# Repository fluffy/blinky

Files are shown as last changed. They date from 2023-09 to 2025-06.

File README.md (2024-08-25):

# blinky

Blinking lights to tell time. And it beeps.

# Build and flash

Build with:
```
mkdir build ; cd build ; cmake .. ; make
```

Note when programming the GPS board, the GPS must be unplugged while
programming.

Program flash using stlink with:
```
st-flash --reset --format ihex write build/blinky.hex
```

Can program using Stm32CubeProgrammer with RTS=1, DTR=0, baud at 115200,
Parity Even, data bits 8, stop bits 1, flow control off.

Program flash using USB serial with:
```
stm32flash -w build/blinky.hex -v -b 115200 -m 8e1 -i "-dtr," /dev/cu.usbserial-31110
```

If this fails, try the following reset then try to flash again. This
will not work on a brand new uninitialized board, the board needs to be
programmed for the first time with st-flash.

Can reset the board with:
```
stty -f /dev/cu.usbserial-31110 hup
```

Monitor output connect with Serial program. Use 115200 baud with 8 bits,
no parity, 1 stop bit. Set the RTS and DTR both low. Screen fails to do
this. It sets RTS and DTR both high it will not work.

To use python miniterm (replace usbserial-31110 with number on your machine):
```
pyserial-miniterm -e --parity N --rts 0 --dtr 0 /dev/cu.usbserial-31110 115200
```
Can exit the miniterm with CTRL+]. This will cause board reset when it starts.

# Tools and Dependencies

Set up a mac to be able to build by installing:

* TODO
* pip3 install pyserial

# Features

## Blink Timing Board

On the Rev A hardware 1.0 software have:

* Timing board with TXCO, LTC Sync in, LTC Sync out, LED grid,
  battery power, USB debug, audio in/out

* Display 120 fps tick on 10x4 grid
* 3.3V LTC Sync Out
* PPS out is hold sync button while booting
* Jitter of less than 1 ms
* Jam sync to 3.3V Sync input
* Time drift of < 5 ms in 1 hour
* USB port for serial data
* read  calibration from EEPROM
* audio out of beep
* headset monitor of audio out
* usb upgrade of firmware
* Status LEDs: error(red), external synced (green),  not sync (
  blue ), have sync (teal)
* audio input to detect beep
* battery with 2h life and USB charger

## Clock and GPS Board

On the Rev A hardware 0.2 software have:

* GPS board with GPS, OCXO
* LTC sync out, LTC sync in
* Does not have audio or led display grid
* 10 MHz sine wave output 1V p2p into 50 ohm, 3 channels
* Sync to GPS PPS
* Show current PPS offset from GPS PPS
* Compare PPS accuracy to GPS over 24 hours
* read  calibration from EEPROM
* USB serial display of: Time, GPS Error, SyncIn Error
* Aux input of 10 MHz signal to compare
* PPS jitter of about +/- 20 ns and error less than 10 ns
* USB upgrade of firmware
* USB 3A power for gps board
* USB output serial data for computer time sync

## Light GPS Board

On the Rev A hardware 0.2 software have:

* GPS board with GPS
* LTC sync out
* Does not have audio or led display grid
* Sync to GPS PPS
* USB upgrade of firmware
* USB power
* USB output serial data for computer time sync

## Wishlist

* time into browser measure computer time offset
* software upgrade from browser

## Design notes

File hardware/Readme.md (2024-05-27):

# Notes on updating hardware

If the schematic or boards in changed such that the software can tell
the difference, the rev need to go up a letter. Other changes can get a
sub number on the rev letter.

## Schematics

Don't update sybols  / footprint from libraries. It over writes stuff.

When done, do a plot to generate schematic in production subdir.

## PCB

When done, do an export of step to generate a model in production
subdir.

## JLCPCB

Make sure to have them check part placement becuase it will be
wrong. Even what they have in the preivewi tool does not allways match
what they have in productions.

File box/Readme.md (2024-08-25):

# Box Info

The main design is in the .FCStd files and crearted with FreeCad.

Most the design paramters are on the "Data" sheet.

Select the object in FreeCad to export the parts as .3mf and .step. The
exported files are in the prod subdirectory.

Go to the front and back drawing and right click on page to select
"Export DXF" and export as .dxf to the prod subdirectory. Using the
export option on the file menu does not work. The eDrawings app on osx
can look at DXF and STEP files.

Import the DXF files into XCR or lightburn for laser cutting.

Upload the step file to sendcutsend.com or jlcpcb.co. With send cut
send, had selected 2mm thick 6061 T6 Aluminum and had it annodized.

3D print using the .3mf files. Set a inner brim of 7 mm on 1st layer
seems to help with small holes.

## Data Flow

KiCad generates step models for the PCBs and puts them in
hardware/blink/productions dir.

This PCB is imported into the FreeCAD drawing for box which generates
DXF files in box/prod dir.

This is brought in to laserA.xcs with "xTool Creative Space" application
to add the labels and set up for laser cutting.

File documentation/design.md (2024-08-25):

# Design Notes for Rev A

## Terminology

Sync refers to Sync In

PPS refers to Sync Out

Mon refers to monitor of PPS

## Signals

- ExtIn 10 MHz input on PA0
- RefIn 10 Mhz OCXO input on PA15

- PPS 1 pps output - inverts on on output buffer - PA8 on Timer #1
- Mon 1 pps in ( from PPS ) - PB11 & AUX PA2
- SyncIn 1 pps input - inverts on buffer  - PB3 and aux PC6
- GpsIn 1 pps input - PB10 and aux PA1

 On blink board:
 - AUX\_CLK, AUX\_GPS_PPS , GPS\_RX, GPX\_TX not used
 - CLK on PA15 is 2.048 Mhz signal

## Timers

system clock or RefIn drives main 32 bit counter

ExtIn drives aux 32 bit counter

Main and aux count at 10 Mhz and wrap ever second.

Every timer can capture syncMon to provide sync of counters

Main and Aux can capture: SyncMon, SyncIn, GpsIn

Timer 1 can generate SyncOut and can sync to Main or Aux timer.

Display TImer drives LED and sync to main or aux rollover

### PPS Out Timer #1  - hTimePps (aka Sync Out)

* Use timer 1. This timer running at 168 Mhz input clock

* CH1 - PA8 - TimePps\_CH\_SYNC\_OUT increments at 50 KHz does 20 ms
wide output pulse every 1 second Resets based on ITR1 from Tim2 Update
Event (main)

* 16 bits

* sync off of timer 2.  loop ever 1.1 seconds.  Input APB2 @ 168 MHz

### Main Timer #2 - hTimeSync (aka SyncIn/main)

* Use timer 2
* max 42 Mhz
* 32 bits
* clocked with ETR from main TCXO at 2.024 MHz or 10 MHz
* period of 1 second ( adjusted in software )
* adjustment store in EEPROM

* ETR: PA15
* CH1: PA0 - NA with ETR
* CH2: PA3  - sync\_in   TimeSync\_CH\_SYNC\_IN
* CH3: PB10  - gps   TimeSync\_CH\_GPS\_PPS
* CH4: PB11  - sync\_mon   TimeSync\_CH\_SYNC\_MON

CH1 is disabled if ETR is in use

* Capture Sync Mon
* Capture PPS In
* Capture GPS PPS

Input APB1 at 84 MHz

### ADC Timer - Timer 3

* count at 1MHz
* 114 count - about 440*20 Hz
* not sync, trigger out to ADC1
Input APB1 at 84 MHz

### Blink Timer - TImer 4

* use timer 4
* trigger reset by main timer every second
* Reset on ITR1 from Tim2
* period 1 ms
* interrupt ( 1 KHz) to drive LEDs
Input APB1 at 84 MHz

### Aux Timer - Timer 5

Assumes that that Aux signal is getting a 10Mhz signal.

* Use 32 bit timer 5
* max 42 Mhz
* ETR:
* CH1: PA0 - AUX\_CLK
* CH2:  PA1 - GPS
* CH3: PA2 - AUX_MON
* Ch4: PA4  - no

CH1 ends up feeding clock.  Capture the Captures both edges of external
so scale by 2 to couting at 10 MHz. The SyncMon capture time allows this
to be coorelated with the other main clock.

* capture SyncMon
* capture GPS PPS
* capture SyncIn
* Input APB1 at 84 MHz

### DAC Timer - Timer 6

* note this does not reset on main
* 1 Mhz count rate
* 8 KHz period ( 1000 count )
* trigger out to DAC2
* Input APB1 at 84 MHz

### TImer 8 - used to time LTC

* has SYCN_IN2 on CH1 on PC6
* reset on main
* 50 KHz rate

1.1 seconds , count up on main at 50 KHz
Input APB2 @ 168 MHz

## Serial

* USB\_RX/TX on PB6/PB7 on USART1

* GPS\_RX1/TX1 on PC10/PC11

* GPS is NMEA-0183 set at 4800 baud 8N1

* GPS is Garmin "GPS 16x LVS"

## DAC

* CH1 is voltage toVCO - PA4
* CH2 is audio out - PA5

* DAC2 is DMA stream 6 memory to peripheral on DMA controller #1
* Normal not circular

## ADC

* uses TIM 3

# Interrupt Handling

On each Main Sync Mon
- save sync out local seconds and microseconds

On each Main GPS PPS
- increment gps seconds and save lastGpsTime in local seconds, microseconds

on each Main SyncIn
- save syncIn local seconds and microsecond

on each Main SyncOut
- if off, turn on, load syncOutOffset+10ms * (seconds%10)
- in on, turn off, load syncOutOffset

on each Aux SyncMon
* save aux 32 bit timer in AuxSyncMon auxSeconds

On each Main Timer rollover
* reset ms time and offset by syncOutOffset
* increment local seconds

On each Blink Timer
* increment msTime
* set all the LEDS based on msTime and local Seconds

Periodically on main thread
* compute gps offset microseconds (32 bit signed)
* compute syncIn offset microseconds (32 bit signed)
* compute syncMon offset microseconds (32 bit signed)
* compute aux offset microseconds ( 32 bit ) from synMon times on main and aux
* if have recent syncIn, adjust syncOutOffset to match syncIn
* if have recent gpsPPS, adjust syncOutOffset to match gps pps

* save last 100 seconds of syncInOffset, gpsOffset, auxOffset, syncMon offset
* compute average offset over last 100s for GPS, Aux, SyncIn
* compute drift rate in Hz over last 100s for GPS, Aux, SyncIn
* compute stdDev off of drift linear for GPS, Aux, Sync

* adjust period of main to match GPS, Aux, Sync in that priority order

# Charging & Power

Max charges rate is 500 mA up to 4.1 V then drops off with m charges up
to 4.2 V. This charge rate selected to not go over USB limit.  Using 820
mAH battery. Current consumption of about 170 mA when *not* on battery.

The blink board uses about 150 mA when running ( bouncing around 145 to
165 based on how many leds ).

On the ev9 board blink board, the 3.3v regulator, in 25C room, runs
about 40 C at 5V input and 50C at 7V input. Indicating about 33 C/watt
thermal resitance which pretty much matched specs for AMS117.

# Calibrating and Adjusting

On frequency counter. On "internal setup" set timeout off.  Noise Reject
on, DC, 1M ohm, manual level 200 mV History grom from 1 s - 20 ns to 1
s+20 ns, 40 bins

On the 2.048 Mhz VCO, will need to adjust pot to get in range. 30 degree
turn made huge difference.

# ESD

The SN74LVC1G14 provide ESD protection. The USB has pretection with the
TODO chip. The USB power CC1/2 power monitor circuits have no
protection. The AD8397 for audio ciricuits on blink board have no
protection on current design. The ADA4807 on clock board have no
protection. The power input on clock board has no protection.

# Linear Time Codes

The spec for them is at
https://www.itu.int/dms_pubrec/itu-r/rec/br/R-REC-BR.780-2-200504-W!!PDF-E.pdf
and more info at https://en.wikipedia.org/wiki/Linear_timecode

# UI and Modes

Buttons controll the varios modes.

Sync button causes it to sync to an input. If it has GPS then use
that, otherwise if have sync in, use that.

Display button moves between: blink,  audio latency, and off

Mute button moves between: rx only, rx & tx

Status LED is:
RED: Error
Purple: Bad power
Blue: Running but not synced
Green: Synced and running

Will auto sync on first sync if sync buton has never been hit

## Configureation

EEProm stores, serial number and device type, calibration info, config
if LTC or PPS output

## Serial Ouput

Sends @ mark for timing host software

Sends current time HH::MM:SS

All metrics reset to zero on first mon pulse after press of sync button

On clock board, mark pulse is GPS, on blink it is Sync

Measurements:

* Current SyncIn Offset in uS

* Current GPS Offset in uS

* Current Mon Offset in uS

* Tick time of last mon pulse

* Tick time of last sync pulse

* Tick time of last gps pulse

* Current Mon ExtOffset in uS

* Current GPS ExtOffset in uS

* Tick time of last ext mon pulse

* Tick time of last ext gps pulse

* GPS seconds of last gps pulse

* LTC seconds of last sync pulse

* Local counter rollover count  ( seconds )

* Ext counter rollover count ( seconds )

The current values are copied to prev once a seconds in the mon pulse
interupt then used to compute the rest of the metrics

Metrics:

* Current time from varios soruces.

* Time erorrs between sources

* Rate of change between sources over 1,10,100 seconds

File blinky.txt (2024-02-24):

Configuration	blinky
STM32CubeMX 	6.10.0
Date	02/24/2024
MCU	STM32F405RGTx

PERIPHERALS	MODES	FUNCTIONS	PINS
ADC1	IN10	ADC1_IN10	PC0
ADC2	IN7	ADC2_IN7	PA7
DAC	DAC_OUT1	DAC_OUT1	PA4
DAC	DAC_OUT2	DAC_OUT2	PA5
I2C1	I2C	I2C1_SCL	PB8
I2C1	I2C	I2C1_SDA	PB9
RCC	Crystal/Ceramic Resonator	RCC_OSC_IN	PH0-OSC_IN
RCC	Crystal/Ceramic Resonator	RCC_OSC_OUT	PH1-OSC_OUT
SYS	Serial Wire	SYS_JTCK-SWCLK	PA14
SYS	Serial Wire	SYS_JTMS-SWDIO	PA13
SYS	SysTick	SYS_VS_Systick	VP_SYS_VS_Systick
TIM1	Reset Mode	TIM1_VS_ControllerModeReset	VP_TIM1_VS_ControllerModeReset
TIM1	ITR1	TIM1_VS_ClockSourceITR	VP_TIM1_VS_ClockSourceITR
TIM1	Internal Clock	TIM1_VS_ClockSourceINT	VP_TIM1_VS_ClockSourceINT
TIM1	Output Compare CH1	TIM1_CH1	PA8
TIM2	ETR2	TIM2_ETR	PA15
TIM2	Input Capture direct mode	TIM2_CH2	PB3
TIM2	Input Capture direct mode	TIM2_CH3	PB10
TIM2	Input Capture direct mode	TIM2_CH4	PB11
TIM3	Internal Clock	TIM3_VS_ClockSourceINT	VP_TIM3_VS_ClockSourceINT
TIM4	Reset Mode	TIM4_VS_ControllerModeReset	VP_TIM4_VS_ControllerModeReset
TIM4	ITR1	TIM4_VS_ClockSourceITR	VP_TIM4_VS_ClockSourceITR
TIM4	Internal Clock	TIM4_VS_ClockSourceINT	VP_TIM4_VS_ClockSourceINT
TIM5	External Clock Mode 1	TIM5_VS_ControllerModeClock	VP_TIM5_VS_ControllerModeClock
TIM5	TI1_ED	TIM5_CH1	PA0-WKUP
TIM5	Input Capture direct mode	TIM5_CH2	PA1
TIM5	Input Capture direct mode	TIM5_CH3	PA2
TIM8	Internal Clock	TIM8_VS_ClockSourceINT	VP_TIM8_VS_ClockSourceINT
TIM8	Input Capture direct mode	TIM8_CH1	PC6
USART1	Asynchronous	USART1_RX	PA10
USART1	Asynchronous	USART1_TX	PA9
USART3	Asynchronous	USART3_RX	PC11
USART3	Asynchronous	USART3_TX	PC10

Pin Nb	PINs	FUNCTIONs	LABELs
2	PC13-ANTI_TAMP	GPIO_Input	BTN1
3	PC14-OSC32_IN	GPIO_Output	NCOL10
4	PC15-OSC32_OUT	GPIO_Output	NROW1
5	PH0-OSC_IN	RCC_OSC_IN	HSE_IN
6	PH1-OSC_OUT	RCC_OSC_OUT	HSE_OUT
8	PC0	ADC1_IN10	AUD_IN
9	PC1	GPIO_Output	NROW2
10	PC2	GPIO_Output	NROW3
11	PC3	GPIO_Output	NROW4
14	PA0-WKUP	TIM5_CH1	AUX_CLK
15	PA1	TIM5_CH2	AUX_GPS_PPS
16	PA2	TIM5_CH3	AUX_SYNC_MON
17	PA3	GPIO_Output	LED4
20	PA4	DAC_OUT1	OSC_ADJ
21	PA5	DAC_OUT2	AUD_OUT
22	PA6	GPIO_Output	LED1
23	PA7	ADC2_IN7	LED2
24	PC4	GPIO_Output	LED7
25	PC5	GPIO_Output	LED8
26	PB0	GPIO_Output	LED9
27	PB1	GPIO_Output	LED10
28	PB2	GPIO_Input	BOOT1
29	PB10	TIM2_CH3	GPS_PPS
30	PB11	TIM2_CH4	SYNC_MON
33	PB12	GPIO_Output	NCOL8
34	PB13	GPIO_Output	NCOL7
35	PB14	GPIO_Output	NCOL6
36	PB15	GPIO_Output	NCOL5
37	PC6	TIM8_CH1	AUX_SYNC_IN
38	PC7	GPIO_Output	NCOL4
39	PC8	GPIO_Output	NCOL3
40	PC9	GPIO_Output	NCOL2
41	PA8	TIM1_CH1	SYNC_OUT
42	PA9	USART1_TX	USB_RX
43	PA10	USART1_RX	USB_TX
44	PA11	GPIO_Output	LEDMG
45	PA12	GPIO_Output	LEDMR
46	PA13	SYS_JTMS-SWDIO	SWDIO
49	PA14	SYS_JTCK-SWCLK	SWDCLK
50	PA15	TIM2_ETR	CLK
51	PC10	USART3_TX	GPS_RX1
52	PC11	USART3_RX	GPS_TX1
53	PC12	GPIO_Output	NCOL9
54	PD2	GPIO_Output	DB3
55	PB3	TIM2_CH2	SYNC_IN
56	PB4	GPIO_Input	LED3
57	PB5	GPIO_Output	NROW5
58	PB6	GPIO_Output	NCOL1
59	PB7	GPIO_Output	LEDMB
61	PB8	I2C1_SCL	SCL
62	PB9	I2C1_SDA	SDA
PERIPHERALS	MODES	FUNCTIONS	PINS
ADC1	IN10	ADC1_IN10	PC0
ADC2	IN7	ADC2_IN7	PA7
DAC	DAC_OUT1	DAC_OUT1	PA4
DAC	DAC_OUT2	DAC_OUT2	PA5
I2C1	I2C	I2C1_SCL	PB8
I2C1	I2C	I2C1_SDA	PB9
RCC	Crystal/Ceramic Resonator	RCC_OSC_IN	PH0-OSC_IN
RCC	Crystal/Ceramic Resonator	RCC_OSC_OUT	PH1-OSC_OUT
SYS	Serial Wire	SYS_JTCK-SWCLK	PA14
SYS	Serial Wire	SYS_JTMS-SWDIO	PA13
SYS	SysTick	SYS_VS_Systick	VP_SYS_VS_Systick
TIM1	Reset Mode	TIM1_VS_ControllerModeReset	VP_TIM1_VS_ControllerModeReset
TIM1	ITR1	TIM1_VS_ClockSourceITR	VP_TIM1_VS_ClockSourceITR
TIM1	Internal Clock	TIM1_VS_ClockSourceINT	VP_TIM1_VS_ClockSourceINT
TIM1	Output Compare CH1	TIM1_CH1	PA8
TIM2	ETR2	TIM2_ETR	PA15
TIM2	Input Capture direct mode	TIM2_CH2	PB3
TIM2	Input Capture direct mode	TIM2_CH3	PB10
TIM2	Input Capture direct mode	TIM2_CH4	PB11
TIM3	Internal Clock	TIM3_VS_ClockSourceINT	VP_TIM3_VS_ClockSourceINT
TIM4	Reset Mode	TIM4_VS_ControllerModeReset	VP_TIM4_VS_ControllerModeReset
TIM4	ITR1	TIM4_VS_ClockSourceITR	VP_TIM4_VS_ClockSourceITR
TIM4	Internal Clock	TIM4_VS_ClockSourceINT	VP_TIM4_VS_ClockSourceINT
TIM5	External Clock Mode 1	TIM5_VS_ControllerModeClock	VP_TIM5_VS_ControllerModeClock
TIM5	TI1_ED	TIM5_CH1	PA0-WKUP
TIM5	Input Capture direct mode	TIM5_CH2	PA1
TIM5	Input Capture direct mode	TIM5_CH3	PA2
TIM8	Internal Clock	TIM8_VS_ClockSourceINT	VP_TIM8_VS_ClockSourceINT
TIM8	Input Capture direct mode	TIM8_CH1	PC6
USART1	Asynchronous	USART1_RX	PA10
USART1	Asynchronous	USART1_TX	PA9
USART3	Asynchronous	USART3_RX	PC11
USART3	Asynchronous	USART3_TX	PC10

Pin Nb	PINs	FUNCTIONs	LABELs
2	PC13-ANTI_TAMP	GPIO_Input	BTN1
3	PC14-OSC32_IN	GPIO_Output	NCOL10
4	PC15-OSC32_OUT	GPIO_Output	NROW1
5	PH0-OSC_IN	RCC_OSC_IN	HSE_IN
6	PH1-OSC_OUT	RCC_OSC_OUT	HSE_OUT
8	PC0	ADC1_IN10	AUD_IN
9	PC1	GPIO_Output	NROW2
10	PC2	GPIO_Output	NROW3
11	PC3	GPIO_Output	NROW4
14	PA0-WKUP	TIM5_CH1	AUX_CLK
15	PA1	TIM5_CH2	AUX_GPS_PPS
16	PA2	TIM5_CH3	AUX_SYNC_MON
17	PA3	GPIO_Output	LED4
20	PA4	DAC_OUT1	OSC_ADJ
21	PA5	DAC_OUT2	AUD_OUT
22	PA6	GPIO_Output	LED1
23	PA7	ADC2_IN7	LED2
24	PC4	GPIO_Output	LED7
25	PC5	GPIO_Output	LED8
26	PB0	GPIO_Output	LED9
27	PB1	GPIO_Output	LED10
28	PB2	GPIO_Input	BOOT1
29	PB10	TIM2_CH3	GPS_PPS
30	PB11	TIM2_CH4	SYNC_MON
33	PB12	GPIO_Output	NCOL8
34	PB13	GPIO_Output	NCOL7
35	PB14	GPIO_Output	NCOL6
36	PB15	GPIO_Output	NCOL5
37	PC6	TIM8_CH1	AUX_SYNC_IN
38	PC7	GPIO_Output	NCOL4
39	PC8	GPIO_Output	NCOL3
40	PC9	GPIO_Output	NCOL2
41	PA8	TIM1_CH1	SYNC_OUT
42	PA9	USART1_TX	USB_RX
43	PA10	USART1_RX	USB_TX
44	PA11	GPIO_Output	LEDMG
45	PA12	GPIO_Output	LEDMR
46	PA13	SYS_JTMS-SWDIO	SWDIO
49	PA14	SYS_JTCK-SWCLK	SWDCLK
50	PA15	TIM2_ETR	CLK
51	PC10	USART3_TX	GPS_RX1
52	PC11	USART3_RX	GPS_TX1
53	PC12	GPIO_Output	NCOL9
54	PD2	GPIO_Output	DB3
55	PB3	TIM2_CH2	SYNC_IN
56	PB4	GPIO_Input	LED3
57	PB5	GPIO_Output	NROW5
58	PB6	GPIO_Output	NCOL1
59	PB7	GPIO_Output	LEDMB
61	PB8	I2C1_SCL	SCL
62	PB9	I2C1_SDA	SDA

SOFTWARE PROJECT

Project Settings : 
Project Name : blinky
Project Folder : /Users/fluffy/src/blinky
Toolchain / IDE : STM32CubeIDE
Firmware Package Name and Version : STM32Cube FW_F4 V1.27.1

Code Generation Settings : 
STM32Cube MCU packages and embedded software packs : Copy only the necessary library files
Generate peripheral initialization as a pair of '.c/.h' files per peripheral : No
Backup previously generated files when re-generating : No
Delete previously generated files when not re-generated : Yes
Set all free pins as analog (to optimize the power consumption) : No

Toolchains Settings : 
Compiler Optimizations :

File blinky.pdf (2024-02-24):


24/02/2024

blinky Project
Configuration Report

## 1. Description

### 1.1. Project

Project Name | blinky
Board Name | custom
Generated with: | STM32CubeMX 6.10.0
Date | 02/24/2024

### 1.2. MCU

MCU Series | STM32F4
MCU Line | STM32F405/415
MCU name | STM32F405RGTx
MCU Package | LQFP64
MCU Pin number | 64

### 1.3. Core(s) information

Core(s) | Arm Cortex-M4

## 2. Pinout Configuration

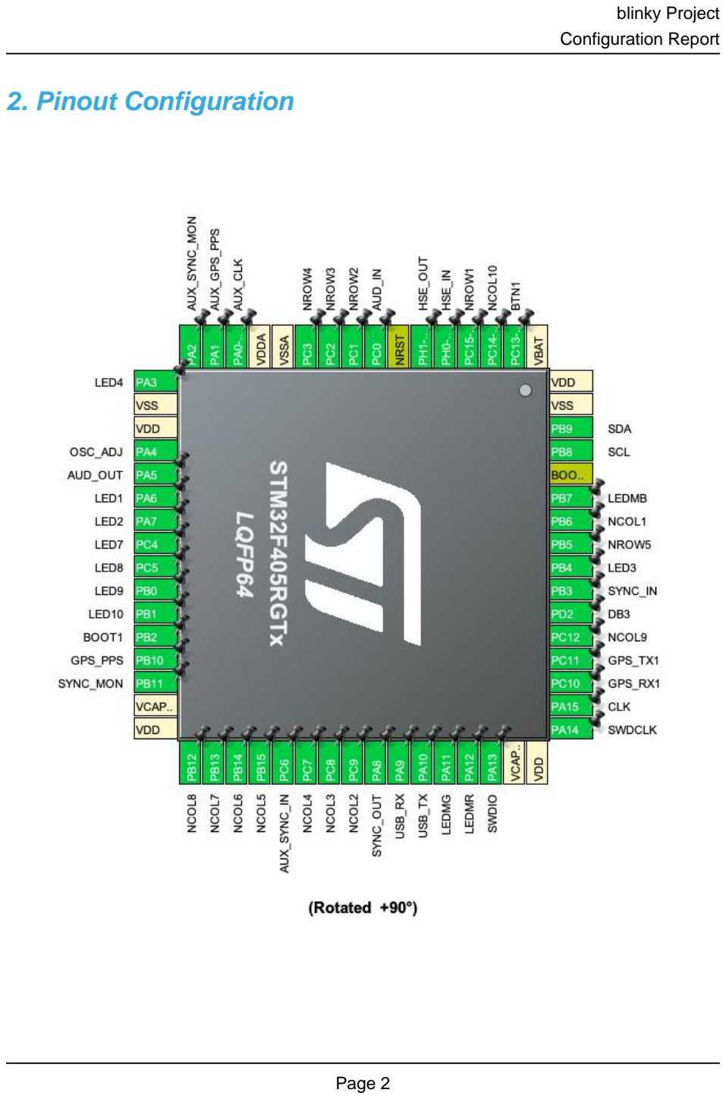
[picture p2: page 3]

## 3. Pins Configuration

Pin Number LQFP64 | Pin Name (function after reset) | Pin Type | Alternate Function(s) | Label
1 | VBAT | Power
2 | PC13-ANTI_TAMP * | I/O | GPIO_Input | BTN1
3 | PC14-OSC32_IN * | I/O | GPIO_Output | NCOL10
4 | PC15-OSC32_OUT * | I/O | GPIO_Output | NROW1
5 | PH0-OSC_IN | I/O | RCC_OSC_IN | HSE_IN
6 | PH1-OSC_OUT | I/O | RCC_OSC_OUT | HSE_OUT
7 | NRST | Reset
8 | PC0 | I/O | ADC1_IN10 | AUD_IN
9 | PC1 * | I/O | GPIO_Output | NROW2
10 | PC2 * | I/O | GPIO_Output | NROW3
11 | PC3 * | I/O | GPIO_Output | NROW4
12 | VSSA | Power
13 | VDDA | Power
14 | PA0-WKUP | I/O | TIM5_CH1 | AUX_CLK
15 | PA1 | I/O | TIM5_CH2 | AUX_GPS_PPS
16 | PA2 | I/O | TIM5_CH3 | AUX_SYNC_MON
17 | PA3 * | I/O | GPIO_Output | LED4
18 | VSS | Power
19 | VDD | Power
20 | PA4 | I/O | DAC_OUT1 | OSC_ADJ
21 | PA5 | I/O | DAC_OUT2 | AUD_OUT
22 | PA6 * | I/O | GPIO_Output | LED1
23 | PA7 | I/O | ADC2_IN7 | LED2
24 | PC4 * | I/O | GPIO_Output | LED7
25 | PC5 * | I/O | GPIO_Output | LED8
26 | PB0 * | I/O | GPIO_Output | LED9
27 | PB1 * | I/O | GPIO_Output | LED10
28 | PB2 * | I/O | GPIO_Input | BOOT1
29 | PB10 | I/O | TIM2_CH3 | GPS_PPS
30 | PB11 | I/O | TIM2_CH4 | SYNC_MON
31 | VCAP_1 | Power
32 | VDD | Power
33 | PB12 * | I/O | GPIO_Output | NCOL8
34 | PB13 * | I/O | GPIO_Output | NCOL7
35 | PB14 * | I/O | GPIO_Output | NCOL6
36 | PB15 * | I/O | GPIO_Output | NCOL5

Pin Number LQFP64 | Pin Name (function after reset) | Pin Type | Alternate Function(s) | Label
37 | PC6 | I/O | TIM8_CH1 | AUX_SYNC_IN
38 | PC7 * | I/O | GPIO_Output | NCOL4
39 | PC8 * | I/O | GPIO_Output | NCOL3
40 | PC9 * | I/O | GPIO_Output | NCOL2
41 | PA8 | I/O | TIM1_CH1 | SYNC_OUT
42 | PA9 | I/O | USART1_TX | USB_RX
43 | PA10 | I/O | USART1_RX | USB_TX
44 | PA11 * | I/O | GPIO_Output | LEDMG
45 | PA12 * | I/O | GPIO_Output | LEDMR
46 | PA13 | I/O | SYS_JTMS-SWDIO | SWDIO
47 | VCAP_2 | Power
48 | VDD | Power
49 | PA14 | I/O | SYS_JTCK-SWCLK | SWDCLK
50 | PA15 | I/O | TIM2_ETR | CLK
51 | PC10 | I/O | USART3_TX | GPS_RX1
52 | PC11 | I/O | USART3_RX | GPS_TX1
53 | PC12 * | I/O | GPIO_Output | NCOL9
54 | PD2 * | I/O | GPIO_Output | DB3
55 | PB3 | I/O | TIM2_CH2 | SYNC_IN
56 | PB4 * | I/O | GPIO_Input | LED3
57 | PB5 * | I/O | GPIO_Output | NROW5
58 | PB6 * | I/O | GPIO_Output | NCOL1
59 | PB7 * | I/O | GPIO_Output | LEDMB
60 | BOOT0 | Boot
61 | PB8 | I/O | I2C1_SCL | SCL
62 | PB9 | I/O | I2C1_SDA | SDA
63 | VSS | Power
64 | VDD | Power

* The pin is affected with an I/O function

## 4. Clock Tree Configuration

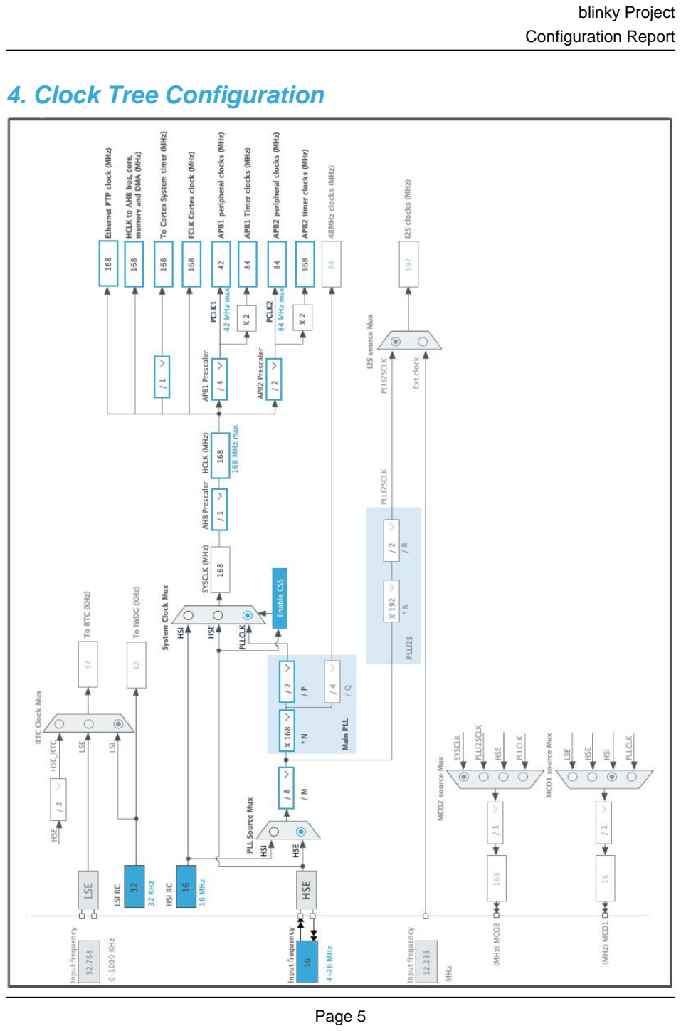
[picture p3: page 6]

## 5. Software Project

### 5.1. Project Settings

Name | Value
Project Name | blinky
Project Folder | /Users/fluffy/src/blinky
Toolchain / IDE | STM32CubeIDE
Firmware Package Name and Version | STM32Cube FW_F4 V1.27.1
Application Structure | Advanced
Generate Under Root | Yes
Do not generate the main() | No
Minimum Heap Size | 0x200
Minimum Stack Size | 0x400

### 5.2. Code Generation Settings

Name | Value
STM32Cube MCU packages and embedded software | Copy only the necessary library files
Generate peripheral initialization as a pair of '.c/.h' files | No
Backup previously generated files when re-generating | No
Keep User Code when re-generating | Yes
Delete previously generated files when not re-generated | Yes
Set all free pins as analog (to optimize the power consumption) | No
Enable Full Assert | Yes

### 5.3. Advanced Settings - Generated Function Calls

Rank | Function Name | Peripheral Instance Name
1 | SystemClock_Config | RCC
2 | MX_GPIO_Init | GPIO
3 | MX_DMA_Init | DMA
4 | MX_TIM8_Init | TIM8
5 | MX_DAC_Init | DAC
6 | MX_I2C1_Init | I2C1
7 | MX_USART1_UART_Init | USART1
8 | MX_ADC1_Init | ADC1
9 | MX_TIM5_Init | TIM5
10 | MX_TIM1_Init | TIM1
11 | MX_TIM4_Init | TIM4

Rank | Function Name | Peripheral Instance Name
12 | MX_TIM2_Init | TIM2
13 | MX_TIM6_Init | TIM6
14 | MX_TIM3_Init | TIM3
15 | MX_ADC2_Init | ADC2
16 | MX_USART3_UART_Init | USART3

## 1. Power Consumption Calculator report

### 1.1. Microcontroller Selection

Series | STM32F4
Line | STM32F405/415
MCU | STM32F405RGTx
Datasheet | DS8626_Rev8

### 1.2. Parameter Selection

Temperature | 25
Vdd | 3.3

### 1.3. Battery Selection

Battery | Li-SOCL2(A3400)
Capacity | 3400.0 mAh
Self Discharge | 0.08 %/month
Nominal Voltage | 3.6 V
Max Cont Current | 100.0 mA
Max Pulse Current | 200.0 mA
Cells in series | 1
Cells in parallel | 1

### 1.4. Sequence

Step | Step1 | Step2
Mode | RUN | STOP
Vdd | 3.3 | 3.3
Voltage Source | Battery | Battery
Range | Scale1-High | No Scale
Fetch Type | FLASH | n/a
CPU Frequency | 168 MHz | 0 Hz
Clock Configuration | HSE PLL | Regulator_LP Flash-PwrDwn
Clock Source Frequency | 4 MHz | 0 Hz
Peripherals
Additional Cons. | 0 mA | 0 mA
Average Current | 46 mA | 280 µA
Duration | 0.1 ms | 0.9 ms
DMIPS | 210.0 | 0.0
Ta Max | 98.02 | 104.96
Category | In DS Table | In DS Table

### 1.5. Results

Sequence Time | 1 ms | Average Current | 4.85 mA
Battery Life | 29 days, 4 hours | Average DMIPS | 210.0 DMIPS

### 1.6. Chart

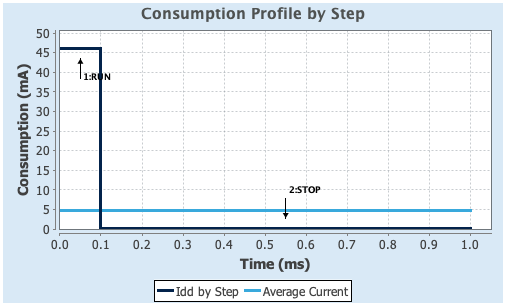
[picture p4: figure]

## 2. Peripherals and Middlewares Configuration

### 2.1. ADC1

mode: IN10
2.1.1. Parameter Settings:

ADCs_Common_Settings:

Mode | Independent mode
ADC_Settings:
Clock Prescaler | PCLK2 divided by 4
Resolution | 12 bits (15 ADC Clock cycles)
Data Alignment | Right alignment
Scan Conversion Mode | Disabled
Continuous Conversion Mode | Disabled
Discontinuous Conversion Mode | Disabled
DMA Continuous Requests | Disabled
End Of Conversion Selection | EOC flag at the end of single channel conversion
ADC_Regular_ConversionMode:
Number Of Conversion | 1
External Trigger Conversion Source | Regular Conversion launched by software
External Trigger Conversion Edge | None
Rank | 1
Channel | Channel 10
Sampling Time | 3 Cycles
ADC_Injected_ConversionMode:
Number Of Conversions | 0
WatchDog:
Enable Analog WatchDog Mode | false

### 2.2. ADC2

mode: IN7
2.2.1. Parameter Settings:

ADCs_Common_Settings:

Mode | Independent mode
ADC_Settings:
Clock Prescaler | PCLK2 divided by 4
Resolution | 12 bits (15 ADC Clock cycles)
Data Alignment | Right alignment

Scan Conversion Mode | Disabled
Continuous Conversion Mode | Disabled
Discontinuous Conversion Mode | Disabled
DMA Continuous Requests | Disabled
End Of Conversion Selection | EOC flag at the end of single channel conversion
ADC_Regular_ConversionMode:
Number Of Conversion | 1
External Trigger Conversion Source | Regular Conversion launched by software
External Trigger Conversion Edge | None
Rank | 1
Channel | Channel 7
Sampling Time | 3 Cycles
ADC_Injected_ConversionMode:
Number Of Conversions | 0
WatchDog:
Enable Analog WatchDog Mode | false

### 2.3. DAC

mode: OUT1 Configuration
mode: OUT2 Configuration
2.3.1. Parameter Settings:

DAC Out1 Settings:

Output Buffer | Enable
Trigger | None
DAC Out2 Settings:
Output Buffer | Enable
Trigger | Timer 6 Trigger Out event *
Wave generation mode | Disabled

### 2.4. I2C1

I2C: I2C
2.4.1. Parameter Settings:

Master Features:

I2C Speed Mode | Standard Mode
I2C Clock Speed (Hz) | 100000

Slave Features:

Clock No Stretch Mode | Disabled
Primary Address Length selection | 7-bit
Dual Address Acknowledged | Disabled
Primary slave address | 0
General Call address detection | Disabled

### 2.5. RCC

High Speed Clock (HSE): Crystal/Ceramic Resonator
2.5.1. Parameter Settings:

System Parameters:

VDD voltage (V) | 3.3
Instruction Cache | Enabled
Prefetch Buffer | Enabled
Data Cache | Enabled
Flash Latency(WS) | 5 WS (6 CPU cycle)
RCC Parameters:
HSI Calibration Value | 16
HSE Startup Timout Value (ms) | 100
LSE Startup Timout Value (ms) | 5000
Power Parameters:
Power Regulator Voltage Scale | Power Regulator Voltage Scale 1

### 2.6. SYS

Debug: Serial Wire
Timebase Source: SysTick

### 2.7. TIM1

Slave Mode: Reset Mode
Trigger Source: ITR1
Clock Source : Internal Clock Channel1: Output Compare CH1
2.7.1. Parameter Settings:

Counter Settings:

Prescaler (PSC - 16 bits value) | 3360-1 *
Counter Mode | Up
Counter Period (AutoReload Register - 16 bits value ) | 55000-1 *
Internal Clock Division (CKD) | No Division
Repetition Counter (RCR - 8 bits value) | 0
auto-reload preload | Disable
Slave Mode Controller | Reset Mode
Trigger Output (TRGO) Parameters:
Master/Slave Mode (MSM bit) | Disable (Trigger input effect not delayed)
Trigger Event Selection | Reset (UG bit from TIMx_EGR)
Break And Dead Time management - BRK Configuration:
BRK State | Disable
BRK Polarity | High
Break And Dead Time management - Output Configuration:
Automatic Output State | Disable
Off State Selection for Run Mode (OSSR) | Disable
Off State Selection for Idle Mode (OSSI) | Disable
Lock Configuration | Off
Output Compare Channel 1:
Mode | Toggle on match *
Pulse (16 bits value) | 1000 *
Output compare preload | Disable
CH Polarity | High
CH Idle State | Reset

### 2.8. TIM2

Clock Source : ETR2
Channel2: Input Capture direct mode Channel3: Input Capture direct mode Channel4: Input Capture direct mode
2.8.1. Parameter Settings:

Counter Settings:

Prescaler (PSC - 16 bits value) | 0
Counter Mode | Up
Counter Period (AutoReload Register - 32 bits value ) | 2048000-1 *
Internal Clock Division (CKD) | No Division
auto-reload preload | Disable

Trigger Output (TRGO) Parameters:

Master/Slave Mode (MSM bit) | Disable (Trigger input effect not delayed)
Trigger Event Selection | Update Event *
Clock:
Clock Filter (4 bits value) | 0
Clock Polarity | non inverted
Clock Prescaler | Prescaler not used
Input Capture Channel 2:
Polarity Selection | Falling Edge *
IC Selection | Direct
Prescaler Division Ratio | No division
Input Filter (4 bits value) | 0
Input Capture Channel 3:
Polarity Selection | Falling Edge *
IC Selection | Direct
Prescaler Division Ratio | No division
Input Filter (4 bits value) | 0
Input Capture Channel 4:
Polarity Selection | Falling Edge *
IC Selection | Direct
Prescaler Division Ratio | No division
Input Filter (4 bits value) | 0

### 2.9. TIM3

Clock Source : Internal Clock
2.9.1. Parameter Settings:

Counter Settings:

Prescaler (PSC - 16 bits value) | 84-1 *
Counter Mode | Up
Counter Period (AutoReload Register - 16 bits value ) | 114-1 *
Internal Clock Division (CKD) | No Division
auto-reload preload | Disable
Trigger Output (TRGO) Parameters:
Master/Slave Mode (MSM bit) | Disable (Trigger input effect not delayed)
Trigger Event Selection | Update Event *

### 2.10. TIM4

Slave Mode: Reset Mode
Trigger Source: ITR1
mode: Clock Source
2.10.1. Parameter Settings:

Counter Settings:

Prescaler (PSC - 16 bits value) | 84-1 *
Counter Mode | Up
Counter Period (AutoReload Register - 16 bits value ) | 1000-1 *
Internal Clock Division (CKD) | No Division
auto-reload preload | Disable
Slave Mode Controller | Reset Mode
Trigger Output (TRGO) Parameters:
Master/Slave Mode (MSM bit) | Disable (Trigger input effect not delayed)
Trigger Event Selection | Reset (UG bit from TIMx_EGR)

### 2.11. TIM5

Slave Mode: External Clock Mode 1
Trigger Source: TI1_ED
Channel2: Input Capture direct mode Channel3: Input Capture direct mode
2.11.1. Parameter Settings:

Counter Settings:

Prescaler (PSC - 16 bits value) | 1 *
Counter Mode | Up
Counter Period (AutoReload Register - 32 bits value ) | 10000000-1 *
Internal Clock Division (CKD) | No Division
auto-reload preload | Disable
Slave Mode Controller | ETR mode 1
Trigger Output (TRGO) Parameters:
Master/Slave Mode (MSM bit) | Disable (Trigger input effect not delayed)
Trigger Event Selection | Reset (UG bit from TIMx_EGR)
Trigger:
Trigger Filter (4 bits value) | 0

Input Capture Channel 2:

Polarity Selection | Rising Edge
IC Selection | Direct
Prescaler Division Ratio | No division
Input Filter (4 bits value) | 0
Input Capture Channel 3:
Polarity Selection | Rising Edge
IC Selection | Direct
Prescaler Division Ratio | No division
Input Filter (4 bits value) | 0

### 2.12. TIM6

mode: Activated
2.12.1. Parameter Settings:

Counter Settings:

Prescaler (PSC - 16 bits value) | 84-1 *
Counter Mode | Up
Counter Period (AutoReload Register - 16 bits value ) | 114-1 *
auto-reload preload | Disable
Trigger Output (TRGO) Parameters:
Trigger Event Selection | Update Event *

### 2.13. TIM8

Clock Source : Internal Clock Channel1: Input Capture direct mode
2.13.1. Parameter Settings:

Counter Settings:

Prescaler (PSC - 16 bits value) | 3360-1 *
Counter Mode | Up
Counter Period (AutoReload Register - 16 bits value ) | 55000-1 *
Internal Clock Division (CKD) | No Division
Repetition Counter (RCR - 8 bits value) | 0
auto-reload preload | Disable
Trigger Output (TRGO) Parameters:

Master/Slave Mode (MSM bit) | Disable (Trigger input effect not delayed)
Trigger Event Selection | Reset (UG bit from TIMx_EGR)
Input Capture Channel 1:
Polarity Selection | Both Edges *
IC Selection | Direct
Prescaler Division Ratio | No division
Input Filter (4 bits value) | 0

### 2.14. USART1

Mode: Asynchronous
2.14.1. Parameter Settings:

Basic Parameters:

Baud Rate | 115200
Word Length | 8 Bits (including Parity)
Parity | None
Stop Bits | 1
Advanced Parameters:
Data Direction | Receive and Transmit
Over Sampling | 16 Samples

### 2.15. USART3

Mode: Asynchronous
2.15.1. Parameter Settings:

Basic Parameters:

Baud Rate | 4800 *
Word Length | 8 Bits (including Parity)
Parity | None
Stop Bits | 1
Advanced Parameters:
Data Direction | Receive and Transmit
Over Sampling | 16 Samples

* User modified value

## 3. System Configuration

### 3.1. GPIO configuration

IP | Pin | Signal | GPIO mode | GPIO pull/up pull down | Max Speed | User Label
ADC1 | PC0 | ADC1_IN10 | Analog mode | No pull-up and no pull-down | n/a | AUD_IN
ADC2 | PA7 | ADC2_IN7 | Analog mode | No pull-up and no pull-down | n/a | LED2
DAC | PA4 | DAC_OUT1 | Analog mode | No pull-up and no pull-down | n/a | OSC_ADJ
| PA5 | DAC_OUT2 | Analog mode | No pull-up and no pull-down | n/a | AUD_OUT
I2C1 | PB8 | I2C1_SCL | Alternate Function Open Drain | No pull-up and no pull-down | Very High * | SCL
| PB9 | I2C1_SDA | Alternate Function Open Drain | No pull-up and no pull-down | Very High * | SDA
RCC | PH0-OSC_IN | RCC_OSC_IN | n/a | n/a | n/a | HSE_IN
| PH1-OSC_OUT | RCC_OSC_OUT | n/a | n/a | n/a | HSE_OUT
SYS | PA13 | SYS_JTMS-SWDIO | n/a | n/a | n/a | SWDIO
| PA14 | SYS_JTCK-SWCLK | n/a | n/a | n/a | SWDCLK
TIM1 | PA8 | TIM1_CH1 | Alternate Function Push Pull | No pull-up and no pull-down | Low | SYNC_OUT
TIM2 | PB10 | TIM2_CH3 | Alternate Function Push Pull | No pull-up and no pull-down | Low | GPS_PPS
| PB11 | TIM2_CH4 | Alternate Function Push Pull | No pull-up and no pull-down | Low | SYNC_MON
| PA15 | TIM2_ETR | Alternate Function Push Pull | No pull-up and no pull-down | Low | CLK
| PB3 | TIM2_CH2 | Alternate Function Push Pull | No pull-up and no pull-down | Low | SYNC_IN
TIM5 | PA0-WKUP | TIM5_CH1 | Alternate Function Push Pull | No pull-up and no pull-down | Low | AUX_CLK
| PA1 | TIM5_CH2 | Alternate Function Push Pull | No pull-up and no pull-down | Low | AUX_GPS_PPS
| PA2 | TIM5_CH3 | Alternate Function Push Pull | No pull-up and no pull-down | Low | AUX_SYNC_MON
TIM8 | PC6 | TIM8_CH1 | Alternate Function Push Pull | No pull-up and no pull-down | Low | AUX_SYNC_IN
USART1 | PA9 | USART1_TX | Alternate Function Push Pull | No pull-up and no pull-down | High * | USB_RX
| PA10 | USART1_RX | Alternate Function Push Pull | No pull-up and no pull-down | High * | USB_TX
USART3 | PC10 | USART3_TX | Alternate Function Push Pull | No pull-up and no pull-down | High * | GPS_RX1
| PC11 | USART3_RX | Alternate Function Push Pull | No pull-up and no pull-down | High * | GPS_TX1
GPIO | PC13-ANTI_TAMP | GPIO_Input | Input mode | Pull-down * | n/a | BTN1
| PC14-OSC32_IN | GPIO_Output | Output Push Pull | No pull-up and no pull-down | Low | NCOL10
| PC15-OSC32_OU T | GPIO_Output | Output Push Pull | No pull-up and no pull-down | Low | NROW1
| PC1 | GPIO_Output | Output Push Pull | No pull-up and no pull-down | Low | NROW2

IP | Pin | Signal | GPIO mode | GPIO pull/up pull down | Max Speed | User Label
| PC2 | GPIO_Output | Output Push Pull | No pull-up and no pull-down | Low | NROW3
| PC3 | GPIO_Output | Output Push Pull | No pull-up and no pull-down | Low | NROW4
| PA3 | GPIO_Output | Output Push Pull | No pull-up and no pull-down | Low | LED4
| PA6 | GPIO_Output | Output Push Pull | No pull-up and no pull-down | Low | LED1
| PC4 | GPIO_Output | Output Push Pull | No pull-up and no pull-down | Low | LED7
| PC5 | GPIO_Output | Output Push Pull | No pull-up and no pull-down | Low | LED8
| PB0 | GPIO_Output | Output Push Pull | No pull-up and no pull-down | Low | LED9
| PB1 | GPIO_Output | Output Push Pull | No pull-up and no pull-down | Low | LED10
| PB2 | GPIO_Input | Input mode | Pull-down * | n/a | BOOT1
| PB12 | GPIO_Output | Output Push Pull | No pull-up and no pull-down | Low | NCOL8
| PB13 | GPIO_Output | Output Push Pull | No pull-up and no pull-down | Low | NCOL7
| PB14 | GPIO_Output | Output Push Pull | No pull-up and no pull-down | Low | NCOL6
| PB15 | GPIO_Output | Output Push Pull | No pull-up and no pull-down | Low | NCOL5
| PC7 | GPIO_Output | Output Push Pull | No pull-up and no pull-down | Low | NCOL4
| PC8 | GPIO_Output | Output Push Pull | No pull-up and no pull-down | Low | NCOL3
| PC9 | GPIO_Output | Output Push Pull | No pull-up and no pull-down | Low | NCOL2
| PA11 | GPIO_Output | Output Push Pull | No pull-up and no pull-down | Low | LEDMG
| PA12 | GPIO_Output | Output Push Pull | No pull-up and no pull-down | Low | LEDMR
| PC12 | GPIO_Output | Output Push Pull | No pull-up and no pull-down | Low | NCOL9
| PD2 | GPIO_Output | Output Push Pull | No pull-up and no pull-down | High * | DB3
| PB4 | GPIO_Input | Input mode | Pull-down * | n/a | LED3
| PB5 | GPIO_Output | Output Push Pull | No pull-up and no pull-down | Low | NROW5
| PB6 | GPIO_Output | Output Push Pull | No pull-up and no pull-down | Low | NCOL1
| PB7 | GPIO_Output | Output Push Pull | No pull-up and no pull-down | Low | LEDMB

### 3.2. DMA configuration

DMA request | Stream | Direction | Priority
DAC2 | DMA1_Stream6 | Memory To Peripheral | Low
ADC1 | DMA2_Stream0 | Peripheral To Memory | Low

DAC2: DMA1_Stream6 DMA request Settings:

Mode: | Circular *
Use fifo: | Disable
Peripheral Increment: | Disable
Memory Increment: | Enable *
Peripheral Data Width: | Word *
Memory Data Width: | Word *

ADC1: DMA2_Stream0 DMA request Settings:

Mode: | Circular *
Use fifo: | Disable
Peripheral Increment: | Disable
Memory Increment: | Enable *
Peripheral Data Width: | Word *
Memory Data Width: | Word *

### 3.3. NVIC configuration

3.3.1. NVIC
Interrupt Table | Enable | Preenmption Priority | SubPriority
Non maskable interrupt | true | 0 | 0
Hard fault interrupt | true | 0 | 0
Memory management fault | true | 0 | 0
Pre-fetch fault, memory access fault | true | 0 | 0
Undefined instruction or illegal state | true | 0 | 0
System service call via SWI instruction | true | 0 | 0
Debug monitor | true | 0 | 0
Pendable request for system service | true | 0 | 0
System tick timer | true | 15 | 0
DMA1 stream6 global interrupt | true | 0 | 0
ADC1, ADC2 and ADC3 global interrupts | true | 0 | 0
TIM1 capture compare interrupt | true | 0 | 0
TIM2 global interrupt | true | 2 | 0
TIM3 global interrupt | true | 0 | 0
TIM4 global interrupt | true | 0 | 0
USART3 global interrupt | true | 0 | 0
TIM8 trigger and commutation interrupts and TIM14 global interrupt | true | 15 | 0
TIM8 capture compare interrupt | true | 3 | 0
TIM5 global interrupt | true | 0 | 0
TIM6 global interrupt, DAC1 and DAC2 underrun error interrupts | true | 0 | 0
DMA2 stream0 global interrupt | true | 0 | 0
PVD interrupt through EXTI line 16 | unused
Flash global interrupt | unused
RCC global interrupt | unused
TIM1 break interrupt and TIM9 global interrupt | unused
TIM1 update interrupt and TIM10 global interrupt | unused
TIM1 trigger and commutation interrupts and TIM11 global interrupt | unused
I2C1 event interrupt | unused
I2C1 error interrupt | unused
USART1 global interrupt | unused
TIM8 break interrupt and TIM12 global interrupt | unused
TIM8 update interrupt and TIM13 global interrupt | unused
FPU global interrupt | unused

3.3.2. NVIC Code generation
Enabled interrupt Table | Select for init sequence ordering | Generate IRQ handler | Call HAL handler
Non maskable interrupt | false | true | false
Hard fault interrupt | false | true | false
Memory management fault | false | true | false
Pre-fetch fault, memory access fault | false | true | false
Undefined instruction or illegal state | false | true | false
System service call via SWI instruction | false | true | false
Debug monitor | false | true | false
Pendable request for system service | false | true | false
System tick timer | false | true | true
DMA1 stream6 global interrupt | false | true | true
ADC1, ADC2 and ADC3 global interrupts | false | true | true
TIM1 capture compare interrupt | false | true | true
TIM2 global interrupt | false | true | true
TIM3 global interrupt | false | true | true
TIM4 global interrupt | false | true | true
USART3 global interrupt | false | true | true
TIM8 trigger and commutation interrupts and TIM14 global interrupt | false | true | true
TIM8 capture compare interrupt | false | true | true
TIM5 global interrupt | false | true | true
TIM6 global interrupt, DAC1 and DAC2 underrun error interrupts | false | true | true
DMA2 stream0 global interrupt | false | true | true

* User modified value

## 4. System Views

4.1. Category view
4.1.1. Current

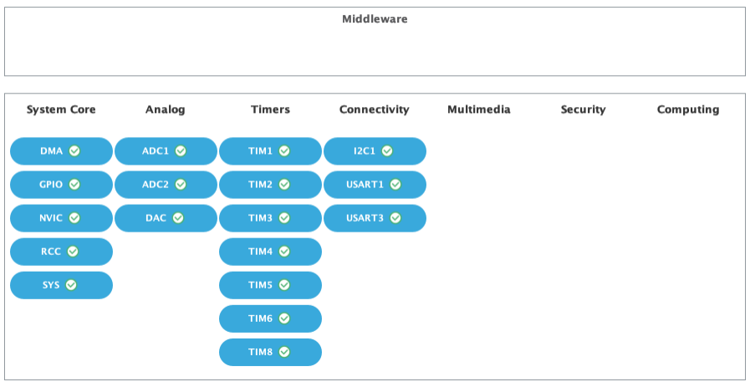
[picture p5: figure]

## 5. Docs & Resources

Type | Link
BSDL files | https://www.st.com/resource/en/bsdl_model/stm32f405-415_407-417_bsdl.zip
IBIS models | https://www.st.com/resource/en/ibis_model/stm32f405-415_407-417_ibis.zip
System View Description | https://www.st.com/resource/en/svd/stm32f4_svd.zip
Presentations | https://www.st.com/resource/en/product_presentation/stm32-stm8_embedded_software_solutions.pdf
Presentations | https://www.st.com/resource/en/product_presentation/stm32_eval-tools_portfolio.pdf
Presentations | https://www.st.com/resource/en/product_presentation/stm32_stm8_functi onal-safety-packages.pdf
Presentations | https://www.st.com/resource/en/product_presentation/stm32-stm8_software_development_tools.pdf
Presentations | https://www.st.com/resource/en/product_presentation/microcontrollers-stm32-family-overview.pdf
Brochures | https://www.st.com/resource/en/brochure/products-and-solutions-for-plcs-and-smart-i-os.pdf
Flyers | https://www.st.com/resource/en/flyer/flstm32nucleo.pdf
Flyers | https://www.st.com/resource/en/flyer/flstmcsuite.pdf
Flyers | https://www.st.com/resource/en/flyer/flstm32trust.pdf
Product Certifications | https://www.st.com/resource/en/certification_document/stm32_authentication_can.pdf
Application Notes | https://www.st.com/resource/en/application_note/an1181-electrostatic-discharge-sensitivity-measurement-stmicroelectronics.pdf
Application Notes | https://www.st.com/resource/en/application_note/an1709-emc-design-guide-for-stm8-stm32-and-legacy-mcus-stmicroelectronics.pdf
Application Notes | https://www.st.com/resource/en/application_note/an2606-stm32-microcontroller-system-memory-boot-mode-stmicroelectronics.pdf

Application Notes | https://www.st.com/resource/en/application_note/an2639-soldering-recommendations-and-package-information-for-leadfree-ecopack-mcus-and-mpus-stmicroelectronics.pdf
Application Notes | https://www.st.com/resource/en/application_note/an2867-oscillator-design-guide-for-stm8afals-stm32-mcus-and-mpus-stmicroelectronics.pdf
Application Notes | https://www.st.com/resource/en/application_note/an2945-stm8s-and-stm32-mcus-a-consistent-832bit-product-line-for-painless-migration-stmicroelectronics.pdf
Application Notes | https://www.st.com/resource/en/application_note/an3070-managing-the-driver-enable-signal-for-rs485-and-iolink-communications-with-the-stm32s-usart-stmicroelectronics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
Application Notes | https://www.st.com/resource/en/application_note/an3126-audio-and-waveform-generation-using-the-dac-in-stm32-products-stmicroelectronics.pdf
Application Notes | https://www.st.com/resource/en/application_note/an3154-can-protocol-used-in-the-stm32-bootloader-stmicroelectronics.pdf
Application Notes | https://www.st.com/resource/en/application_note/an3155-usart-protocol-used-in-the-stm32-bootloader-stmicroelectronics.pdf
Application Notes | https://www.st.com/resource/en/application_note/an3156-usb-dfu-protocol-used-in-the-stm32-bootloader-stmicroelectronics.pdf
Application Notes | https://www.st.com/resource/en/application_note/an3364-migration-and-compatibility-guidelines-for-stm32-microcontroller-applications-stmicroelectronics.pdf
Application Notes | https://www.st.com/resource/en/application_note/an3371-using-the-hardware-realtime-clock-rtc-in-stm32-f0-f2-f3-f4-and-l1-series-of-mcus-stmicroelectronics.pdf
Application Notes | https://www.st.com/resource/en/application_note/an3997-audio-playback-and-recording-using-the-stm32f4discovery-stmicroelectronics.pdf
Application Notes | https://www.st.com/resource/en/application_note/an3998-pdm-audio-software-decoding-on-stm32-microcontrollers-stmicroelectronics.pdf
Application Notes | https://www.st.com/resource/en/application_note/an4013-stm32-crossseries-timer-overview-stmicroelectronics.pdf
Application Notes | https://www.st.com/resource/en/application_note/an4031-using-the-

| stm32f2-stm32f4-and-stm32f7-series-dma-controller-stmicroelectronics.pdf
Application Notes | https://www.st.com/resource/en/application_note/an4073-how-to-improve-adc-accuracy-when-using-stm32f2xx-and-stm32f4xx-microcontrollers-stmicroelectronics.pdf
Application Notes | https://www.st.com/resource/en/application_note/an4076-two-or-three-shunt-resistor-based-current-sensing-circuit-design-in-3phase-inverters-stmicroelectronics.pdf
Application Notes | https://www.st.com/resource/en/application_note/an4221-i2c-protocol-used-in-the-stm32-bootloader-stmicroelectronics.pdf
Application Notes | https://www.st.com/resource/en/application_note/an4229-how-to-implement-a-vocoder-solution-using-stm32-microcontrollers-stmicroelectronics.pdf
Application Notes | https://www.st.com/resource/en/application_note/an4277-using-stm32-device-pwm-shutdown-features-for-motor-control-and-digital-power-conversion-stmicroelectronics.pdf
Application Notes | https://www.st.com/resource/en/application_note/an4286-spi-protocol-used-in-the-stm32-bootloader-stmicroelectronics.pdf
Application Notes | https://www.st.com/resource/en/application_note/an4488-getting-started-with-stm32f4xxxx-mcu-hardware-development-stmicroelectronics.pdf
Application Notes | https://www.st.com/resource/en/application_note/an4566-extending-the-dac-performance-of-stm32-microcontrollers-stmicroelectronics.pdf
Application Notes | https://www.st.com/resource/en/application_note/an4640-peripherals-interconnections-on-stm32f4057xx-stm32f4157xx-stm32f42xxx-stm32f43xxx-stm32f446xx-and-stm32f469479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
Application Notes | https://www.st.com/resource/en/application_note/an4655-virtually-increasing-the-number-of-serial-communication-peripherals-in-stm32-applications-stmicroelectronics.p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
Application Notes | https://www.st.com/resource/en/application_note/an4739-stm32cube-firmware-examples-for-stm32f4-series-stmicroelectronics.pdf
Application Notes | https://www.st.com/resource/en/application_note/an4750-handling-of-soft-errors-in-stm32-applications-stmicroelectronics.pdf
Application Notes | https://www.st.com/resource/en/application_note/an4759-using-the-

| hardware-realtime-clock-rtc-and-the-tamper-management-unit-tamp-with-stm32-microcontrollers-stmicroelectronics.pdf
Application Notes | https://www.st.com/resource/en/application_note/an4776-generalpurpose-timer-cookbook-for-stm32-microcontrollers-stmicroelectronics.pdf
Application Notes | https://www.st.com/resource/en/application_note/an4803-highspeed-si-simulations-using-ibis-and-boardlevel-simulations-using-hyperlynx-si-on-stm32-mcus-and-mpus-stmic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
Application Notes | https://www.st.com/resource/en/application_note/an4821-migrating-from-stm32f405415-line-and-stm32f407417-line-to-stm32l4-series-and-stm32l4-series-microcontrollers-s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
Application Notes | https://www.st.com/resource/en/application_note/an4850-stm32-mcus-spreadspectrum-clock-generation-principles-properties-and-implementation-stmicroelectronics.pdf
Application Notes | https://www.st.com/resource/en/application_note/an4908-stm32-usart-automatic-baud-rate-detection-stmicroelectronics.pdf
Application Notes | https://www.st.com/resource/en/application_note/an4989-stm32-microcontroller-debug-toolbox-stmicroelectronics.pdf
Application Notes | https://www.st.com/resource/en/application_note/an4995-using-an-electromyogram-technique-to-detect-muscle-activity-stmicroelectronics.pdf
Application Notes | https://www.st.com/resource/en/application_note/an5027-interfacing-pdm-digital-microphones-using-stm32-mcus-and-mpus-stmicroelectronics.pdf
Application Notes | https://www.st.com/resource/en/application_note/an5036-thermal-management-guidelines-for-stm32-applications-stmicroelectronics.pdf
Application Notes | https://www.st.com/resource/en/application_note/an5073-receiving-spdif-audio-stream-with-the-stm32f4f7h7-series-stmicroelectronics.pdf
Application Notes | https://www.st.com/resource/en/application_note/an5543-enhanced-methods-to-handle-spi-communication-on-stm32-devices-stmicroelectronics.pdf
Application Notes | https://www.st.com/resource/en/application_note/an4899-stm32-microcontroller-gpio-hardware-settings-and-lowpower-consumption-stmicroelectronics.pdf
Application Notes | https://www.st.com/resource/en/application_note/an5612-esd-protection-

| of-stm32-mcus-and-mpus-stmicroelectronics.pdf
Application Notes | https://www.st.com/resource/en/application_note/an5156-introduction-to-stm32-microcontrollers-security-stmicroelectronics.pdf
Application Notes | https://www.st.com/resource/en/application_note/an4838-introduction-to-memory-protection-unit-management-on-stm32-mcus-stmicroelectronics.pdf
Application Notes | https://www.st.com/resource/en/application_note/an4230-random-number-generation-validation-using-nist-statistical-test-suite-for-stm32-microcontrollers-stmicroelectr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
Application Notes | https://www.st.com/resource/en/application_note/an4879-introduction-to-usb-hardware-and-pcb-guidelines-using-stm32-mcus-stmicroelectronics.pdf
Application Notes | https://www.st.com/resource/en/application_note/an5225-introduction-to-usb-typec-power-delivery-for-stm32-mcus-and-mpus-stmicroelectronics.pdf
Application Notes | https://www.st.com/resource/en/application_note/an2834-how-to-optimize-the-adc-accuracy-in-the-stm32-mcus-stmicroelectronics.pdf
Application Notes | https://www.st.com/resource/en/application_note/an5816-how-to-build-stm32-lpbam-application-using-stm32cubemx-stmicroelectronics.pdf
Application Notes | https://www.st.com/resource/en/application_note/an5537-how-to-use-adc-oversampling-techniques-to-improve-signaltonoise-ratio-on-stm32-mcus-stmicroelectronics.pdf
Application Notes for related Tools & Software | https://www.st.com/resource/en/application_note/an1202_freertos_guide-freertos-guide-stmicroelectronics.pdf
Application Notes for related Tools & Software | https://www.st.com/resource/en/application_note/an1602_semihosting_in_truestudio-how-to-do-semihosting-in-truestudio-stmicroelectronics.pdf
Application Notes for related Tools & Software | https://www.st.com/resource/en/application_note/an1801_stm32cubeprogrammer_in_truestudio-installing-stm32cubeprogrammer-in-truestudio-stmicroelectronics.pdf
Application Notes for related Tools & Software | https://www.st.com/resource/en/application_note/atollic_editing_keyboard_shortcuts-atollic-editing-keyboard-shortcuts-stmicroelectronics.pdf

Application Notes for related Tools & Software | https://www.st.com/resource/en/application_note/iar_to_atollic_truestudio_migration_guide-truestudio-for-arm-migration-guide-iar-embedded-workbench-to-truestudio-stm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
Application Notes for related Tools & Software | https://www.st.com/resource/en/application_note/stm32cubemx_installation_in_truestudio-stm32cubemx-installation-in-truestudio-stmicroelectronics.pdf
Application Notes for related Tools & Software | https://www.st.com/resource/en/application_note/an2656-stm32f10xxx-lcd-glass-driver-firmware-stmicroelectronics.pdf
Application Notes for related Tools & Software | https://www.st.com/resource/en/application_note/an2790-tft-lcd-interfacing-with-the-highdensity-stm32f10xxx-fsmc-stmicroelectronics.pdf
Application Notes for related Tools & Software | https://www.st.com/resource/en/application_note/an3078-stm32-inapplication-programming-over-the-ic-bus-stmicroelectronics.pdf
Application Notes for related Tools & Software | https://www.st.com/resource/en/application_note/an3116-stm32s-adc-modes-and-their-applications-stmicroelectronics.pdf
Application Notes for related Tools & Software | https://www.st.com/resource/en/application_note/an3174-implementing-receivers-for-infrared-remote-control-protocols-using-stm32f10xxx-microcontrollers-stmicroelectro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
Application Notes for related Tools & Software | https://www.st.com/resource/en/application_note/an3241-qvga-tftlcd-direct-drive-using-the-stm32f10xx-fsmc-peripheral-stmicroelectronics.pdf
Application Notes for related Tools & Software | https://www.st.com/resource/en/application_note/an3307-guidelines-for-obtaining-iec-60335-class-b-certification-for-any-stm32-application-stmicroelectronics.pdf
Application Notes for related Tools & Software | https://www.st.com/resource/en/application_note/an3364-migration-and-compatibility-guidelines-for-stm32-microcontroller-applications-stmicroelectronics.pdf
Application Notes for related Tools & Software | https://www.st.com/resource/en/application_note/an3965-stm32f40xstm32f41x-inapplication-programming-using-the-usart-stmicroelectronics.pdf
Application Notes | https://www.st.com/resource/en/application_note/an3969-eeprom-

for related Tools & Software | emulation-in-stm32f40xstm32f41x-microcontrollers-stmicroelectronics.pdf
Application Notes for related Tools & Software | https://www.st.com/resource/en/application_note/an3988-clock-configuration-tool-for-stm32f40xx41xx427x437x-microcontrollers-stmicroelectronics.pdf
Application Notes for related Tools & Software | https://www.st.com/resource/en/application_note/an3990-upgrading-stm32f4discovery-board-firmware-using-a-usb-key-stmicroelectronics.pdf
Application Notes for related Tools & Software | https://www.st.com/resource/en/application_note/an3997-audio-playback-and-recording-using-the-stm32f4discovery-stmicroelectronics.pdf
Application Notes for related Tools & Software | https://www.st.com/resource/en/application_note/an3998-pdm-audio-software-decoding-on-stm32-microcontrollers-stmicroelectronics.pdf
Application Notes for related Tools & Software | https://www.st.com/resource/en/application_note/an4044-floating-point-unit-demonstration-on-stm32-microcontrollers-stmicroelectronics.pdf
Application Notes for related Tools & Software | https://www.st.com/resource/en/application_note/an4323-getting-started-with-stemwin-library-stmicroelectronics.pdf
Application Notes for related Tools & Software | https://www.st.com/resource/en/application_note/an4365-using-stm32f4-mcu-power-modes-with-best-dynamic-efficiency-stmicroelectronics.pdf
Application Notes for related Tools & Software | https://www.st.com/resource/en/application_note/an4435-guidelines-for-obtaining-ulcsaiec-607301603351-class-b-certification-in-any-stm32-application-stmicroelectroni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
Application Notes for related Tools & Software | https://www.st.com/resource/en/application_note/an4457-implementing-an-emulated-uart-on-stm32f4-microcontrollers-stmicroelectronics.pdf
Application Notes for related Tools & Software | https://www.st.com/resource/en/application_note/an4499-stm32--nrf51822-bluetooth-low-energy-system-solution-stmicroelectronics.pdf

Application Notes
for related Tools

https://www.st.com/resource/en/application_note/an4657-stm32-inapplication-programming-iap-using-the-usart-stmicroelectronics.pdf

& Software
Application Notes for related Tools & Software | https://www.st.com/resource/en/application_note/an4666-parallel-synchronous-transmission-using-gpio-and-dma-stmicroelectronics.pdf
Application Notes for related Tools & Software | https://www.st.com/resource/en/application_note/an4678-full-duplex-spi-emulation-for-stm32f4-microcontrollers-stmicroelectronics.pdf
Application Notes for related Tools & Software | https://www.st.com/resource/en/application_note/an4701-proprietary-code-readout-protection-on-microcontrollers-of-the-stm32f4-series-stmicroelectronics.pdf
Application Notes for related Tools & Software | https://www.st.com/resource/en/application_note/an4739-stm32cube-firmware-examples-for-stm32f4-series-stmicroelectronics.pdf
Application Notes for related Tools & Software | https://www.st.com/resource/en/application_note/an4758-proprietary-code-readout-protection-on-stm32l4-stm32l4-stm32g4-and-stm32wb-series-mcus-stmicroelectronics.pdf
Application Notes for related Tools & Software | https://www.st.com/resource/en/application_note/an4759-using-the-hardware-realtime-clock-rtc-and-the-tamper-management-unit-tamp-with-stm32-microcontrollers-stmicroe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
Application Notes for related Tools & Software | https://www.st.com/resource/en/application_note/an4841-digital-signal-processing-for-stm32-microcontrollers-using-cmsis-stmicroelectronics.pdf
Application Notes for related Tools & Software | https://www.st.com/resource/en/application_note/an4968-proprietary-code-read-out-protection-pcrop-on-stm32f72xxx-and-stm32f73xxx-microcontrollers-stmicroelectronics.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
Application Notes for related Tools & Software | https://www.st.com/resource/en/application_note/an5054-secure-programming-using-stm32cubeprogrammer-stmicroelectronics.pdf
Application Notes for related Tools & Software | https://www.st.com/resource/en/application_note/an5056-integration-guide-for-the-xcubesbsfu-stm32cube-expansion-package-stmicroelectronics.pdf
Application Notes for related Tools & Software | https://www.st.com/resource/en/application_note/an5360-getting-started-with-projects-based-on-the-stm32mp1-series-in-stm32cubeide-stmicroelectronics.pdf

Application Notes for related Tools & Software | https://www.st.com/resource/en/application_note/an5361-getting-started-with-projects-based-on-dualcore-stm32h7-microcontrollers-in-stm32cubeide-stmicroelectronics.pd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
Application Notes for related Tools & Software | https://www.st.com/resource/en/application_note/an5394-getting-started-with-projects-based-on-the-stm32l5-series-in-stm32cubeide-stmicroelectronics.pdf
Application Notes for related Tools & Software | https://www.st.com/resource/en/application_note/an5418-how-to-build-a-simple-usbpd-sink-application-with-stm32cubemx-stmicroelectronics.pdf
Application Notes for related Tools & Software | https://www.st.com/resource/en/application_note/an5426-migrating-graphics-middleware-projects-from-stm32cubemx-540-to-stm32cubemx-550-stmicroelectronics.pdf
Application Notes for related Tools & Software | https://www.st.com/resource/en/application_note/an5464-position-control-of-a-threephase-permanent-magnet-motor-using-xcubemcsdk-or-xcubemcsdkful-stmicroelectronics.p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
Application Notes for related Tools & Software | https://www.st.com/resource/en/application_note/an5564-getting-started-with-projects-based-on-dualcore-stm32wl-microcontrollers-in-stm32cubeide-stmicroelectronics.pd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
Application Notes for related Tools & Software | https://www.st.com/resource/en/application_note/an5698-adapting-the-xcubestl-functional-safety-package-for-stm32-iec-61508-compliant-to-other-safety-standards-stmicr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
Application Notes for related Tools & Software | https://www.st.com/resource/en/application_note/an5731-stm32cubemx-and-stm32cubeide-threadsafe-solution-stmicroelectronics.pdf
Application Notes for related Tools & Software | https://www.st.com/resource/en/application_note/an4502-stm32-smbuspmbus-expansion-package-for-stm32cube-stmicroelectronics.pdf
Application Notes for related Tools & Software | https://www.st.com/resource/en/application_note/an5952-how-to-use-cmake-in-stm32cubeide-stmicroelectronics.pdf
Errata Sheets | https://www.st.com/resource/en/errata_sheet/es0182-stm32f405407xx-and-stm32f415417xx-device-errata-stmicroelectronics.pdf
Datasheet | https://www.st.com/resource/en/datasheet/dm00037051.pdf
Programming | https://www.st.com/resource/en/programming_manual/pm0214-stm32-

Manuals | cortexm4-mcus-and-mpus-programming-manual-stmicroelectronics.pdf
Reference Manuals | https://www.st.com/resource/en/reference_manual/rm0090-stm32f405415-stm32f407417-stm32f427437-and-stm32f429439-advanced-armbased-32bit-mcus-stmicroelectronics.pdf
Technical Notes & Articles | https://www.st.com/resource/en/technical_note/tn0516-overview-of-the-stm32f0xf100xxf103xx-and-stm32f2xxf30xf4xx-mcus-pmsm-singledual-foc-sdk-v40-stmicroelectronics.p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
Technical Notes & Articles | https://www.st.com/resource/en/technical_note/tn1163-description-of-wlcsp-for-microcontrollers-and-recommendations-for-its-use-stmicroelectronics.pdf
Technical Notes & Articles | https://www.st.com/resource/en/technical_note/tn1204-tape-and-reel-shipping-media-for-stm32-microcontrollers-in-bga-packages-stmicroelectronics.pdf
Technical Notes & Articles | https://www.st.com/resource/en/technical_note/tn1205-tape-and-reel-shipping-media-for-stm8-and-stm32-microcontrollers-in-fpn-packages-stmicroelectronics.pdf
Technical Notes & Articles | https://www.st.com/resource/en/technical_note/tn1206-tape-and-reel-shipping-media-for-stm8-and-stm32-microcontrollers-in-qfp-packages-stmicroelectronics.pdf
Technical Notes & Articles | https://www.st.com/resource/en/technical_note/tn1207-tape-and-reel-shipping-media-for-stm8-and-stm32-microcontrollers-in-so-packages-stmicroelectronics.pdf
Technical Notes & Articles | https://www.st.com/resource/en/technical_note/tn1208-tape-and-reel-shipping-media-for-stm8-and-stm32-microcontrollers-in-tssop-and-ssop-packages-stmicroelectronics.p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
Technical Notes & Articles | https://www.st.com/resource/en/technical_note/tn1433-reference-device-marking-schematics-for-stm32-microcontrollers-and-microprocessors-stmicroelectronics.pdf

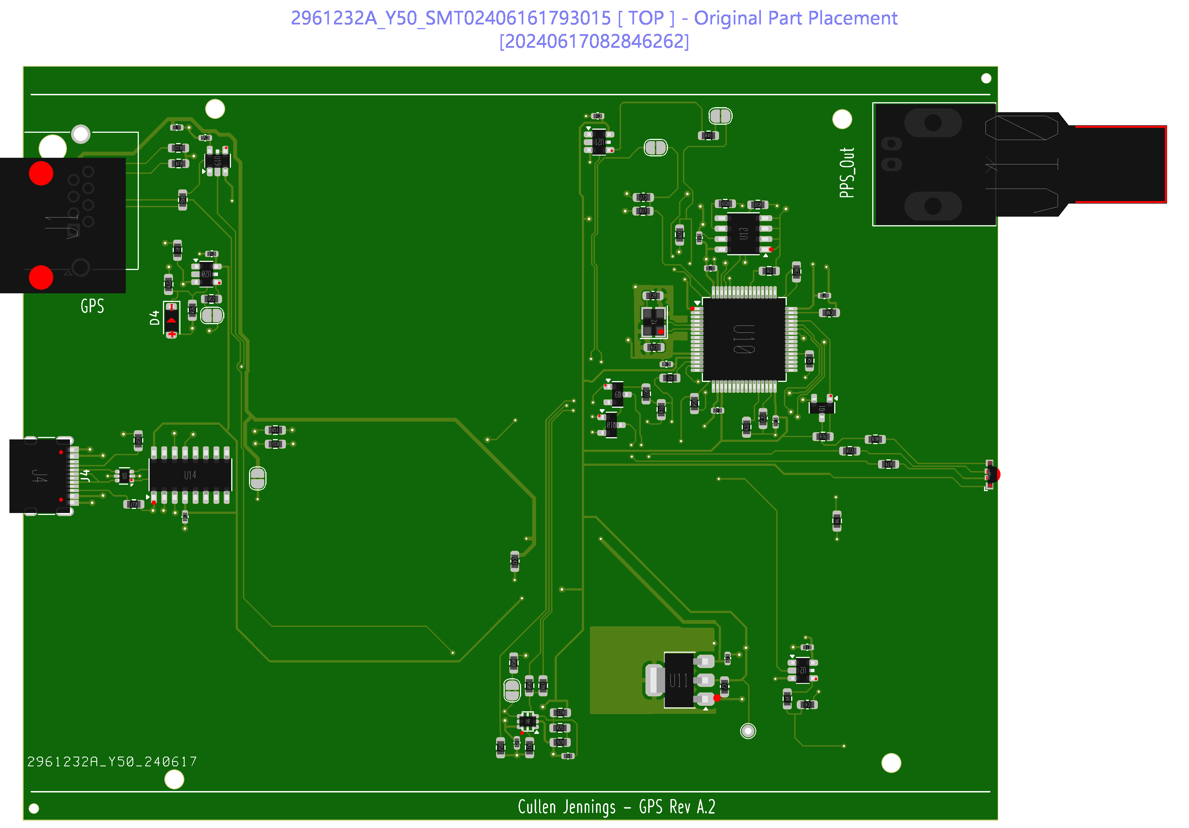
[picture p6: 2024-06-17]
hardware/gps_A/production/orig-pcb.png

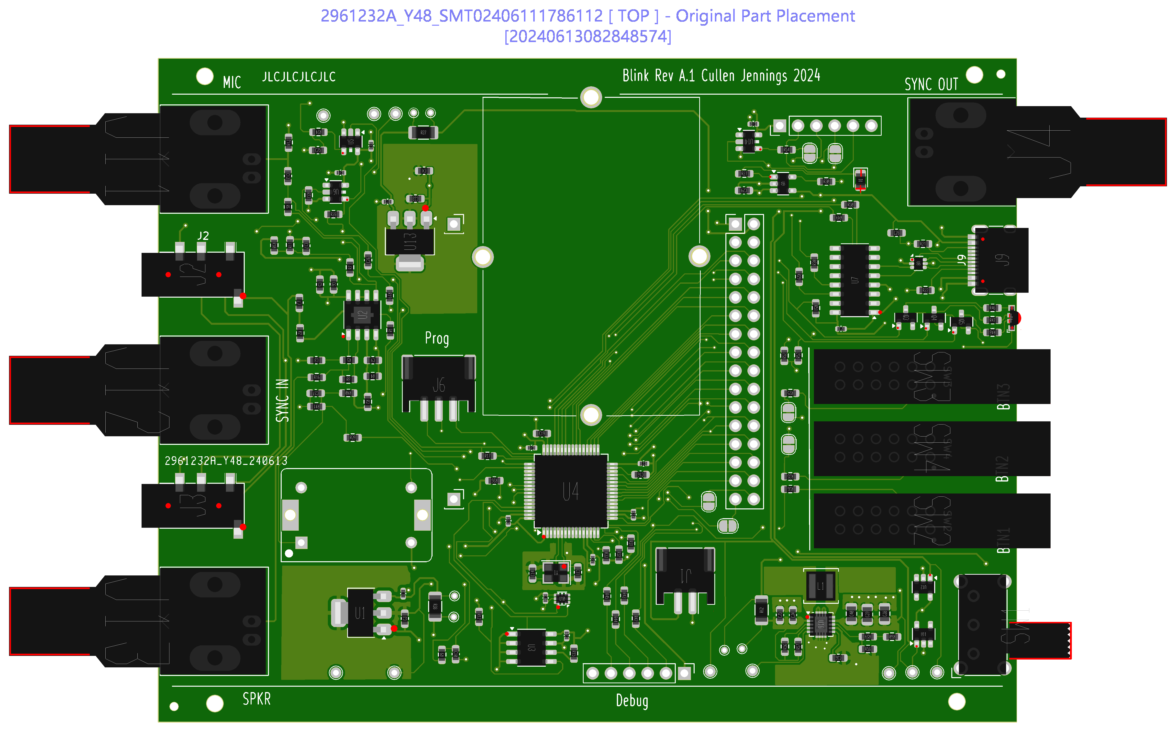
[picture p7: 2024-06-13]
hardware/blink_A/production/prod-original.png

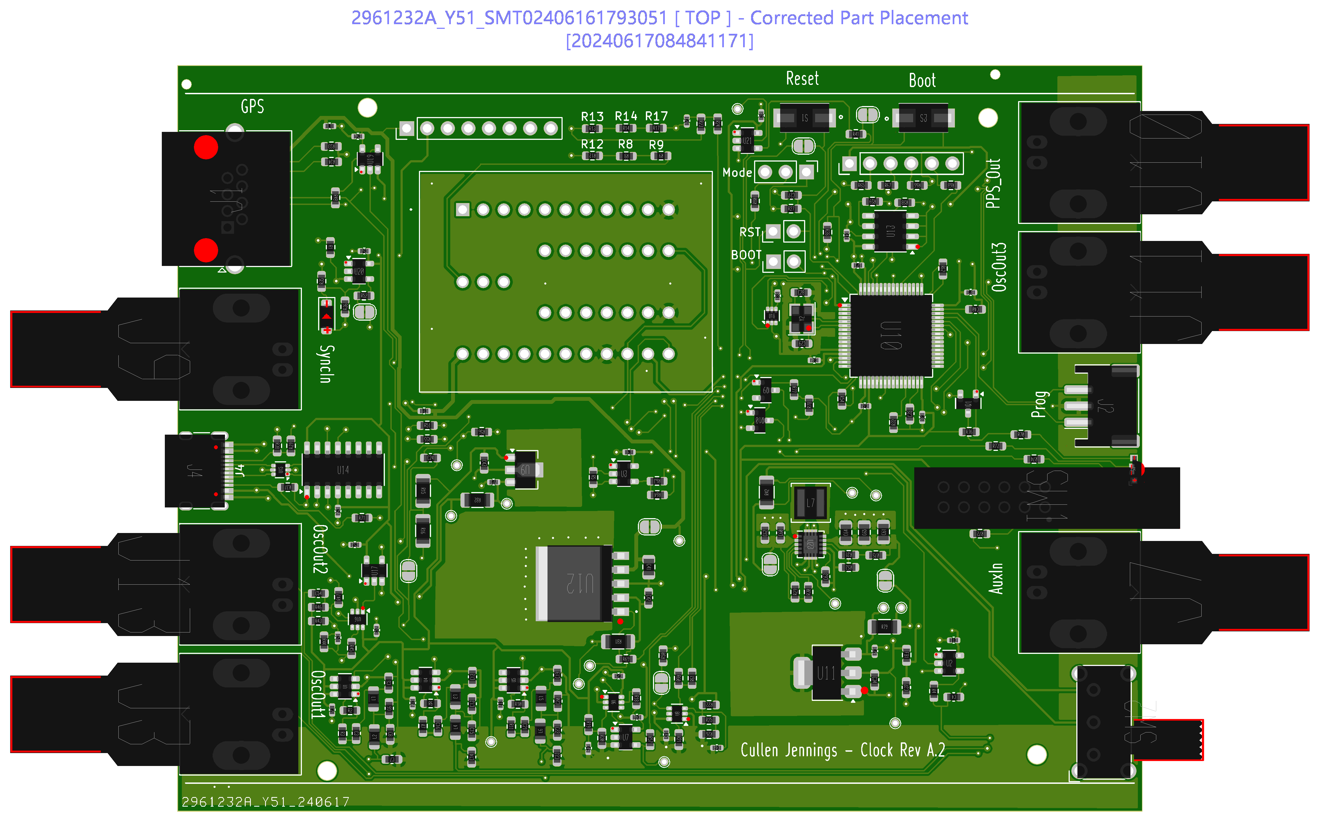
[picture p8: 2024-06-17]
hardware/clock_A/production/fixed-pcb.png

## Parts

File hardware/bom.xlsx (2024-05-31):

Part | MPN | NumGPS | NumClock | NumBlink | Price | Needed | Have | Order Notes | Ordered
GPS PCB |  | 1 |  |  | 62.00 | 5 |  | price is Q2
Clock PCB |  |  | 1 |  | 110.00 | 2 |  | price is Q2
Blink PCB |  |  |  | 1 | 60.00 | 10 |  | price is Q2
Disp PCB |  |  |  | 1 | 9.00 | 10 |  | price is Q10
Battery |  |  |  | 1 | 15.00 | 10 |  | https://www.amazon.ca/gp/product/B082152887
Battery Tape |  |  |  | 1 | 0.25 | 10 | 10 | https://www.amazon.ca/gp/product/B0BDFDS75Z | 0
1/2 Nut |  | 1 | 6 | 4 | 0.50 | 57 |  |  | 100
1/2 Washer |  | 1 | 6 | 4 | 0.40 | 57 | 0 |  | 100
Red Button | Mouser 612-1R-RD | 1 | 1 | 1 | 0.25 | 17 | 3 |  | 50
Black Button |  |  |  | 1 | 0.25 | 10 | 3 |  | 30
White Button |  |  |  | 1 | 0.25 | 10 | 4 |  | 30
TCXO | ACVTX1018A-2.048MHZ-D10 |  |  | 1 | 44.00 | 10 | 4 |  | 6
OCXO | AOCJY4A-10.000MHZ-SW |  | 1 |  | 220.00 | 2 | 2 |  | 0
GPS Unit | Garmin GPS 16x LVS | 1 | 1 |  | 100.00 | 7 | 1 | https://www.amazon.ca/gp/product/B0016NYHOA | 1
M3x6CapScrew |  | 8 | 8 | 8 | 0.10 | 136 |  | https://www.amazon.ca/Alloy-Steel-Socket-Screws-Black/dp/B00W8YSCIS | 200
Box |  | 1 | 1 | 1 | 13.50 | 17 | 19 | https://www.amazon.ca/gp/product/B010DHQPVW | 0
Plexiglass |  |  |  | 1 |  | 10
front plate gps |  | 1 |  |  | 9.00 | 5 |  | Q4
front plate clock |  |  | 1 |  | 9.00 | 2 |  | Q4
front plate blink |  |  |  | 1 | 7.50 | 10 |  | Q10 ?
back plate gps |  | 1 |  |  | 9.00 | 5 |  | Q4
back plate clock |  |  | 1 |  | 9.00 | 2 |  | Q4
back plate blink |  |  |  | 1 | 7.50 | 10 |  | Q10
2 row headers |  |  |  | 1 |  | 10
1 row headers |  |  |  | 2 |  | 20
window glue |  |  |  |  |  |  |  |  | 0
usb cable |  | 1 | 1 | 1
audio cable |  |  |  | 1
headset |  |  |  | 1
 | Total Cost | $195.45 | $467.95 | $161.90

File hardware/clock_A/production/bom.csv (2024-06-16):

Designator | Footprint | Quantity | Value | LCSC Part #
C1, C10, C11, C17, C18, C2, C25, C26, C30, C31, C32, C33, C36, C38, C39, C45, C46, C47, C48, C49, C50, C51, C52, C53, C55, C56, C57, C58, C9 | 0402 | 29 | 100n | C307331
C12, C14, C19, C23, C5, C7 | 0603 | 6 | 150p | C1594
C13, C20, C8 | 0603 | 3 | 330p | C1664
C15, C22, C6 | 0603 | 3 | 220p | C1603
C16, C21, C3 | 0603 | 3 | 1n0 | C1588
C24, C27, C37, C54, C63 | 0603 | 5 | 100n | C14663
C28, C29 | 0603 | 2 | 33p | C1663
C34, C43, C60, C62 | 0603 | 4 | 10u | C96446
C35, C40, C42 | 0603 | 3 | 2u2 | C23630
C4 | 0603 | 1 | 47p | C1671
C41, C61, C64, C65 | 0805 | 4 | 22u | C45783
D4 | D_SOD-123 | 1 | B5819W SL | C8598
D5 | LED_RGB_MHS110FRGBCT | 1 | LED_ABGR | C496820
FB1 | 0603 | 1 | 120Ω@100MHz | C127301
J1 | RJ45_Amphenol_RJHSE5380 | 1 | RJ45 | C464586
J10, J11, J13, J3, J7, J9 | BNC_Amphenol_B6252HB-NPP3G-50_Horizontal-CJ | 6 | KH-BNC50-3511 | C2837587
J2 | JST_PH_S3B-PH-SM4-TB_1x03-1MP_P2.00mm_Horizontal | 1 | Conn_01x03 | C265101
J4 | USB_C_Receptacle_HRO_TYPE-C-31-M-12 | 1 | USB_C_Receptacle | C165948
L1, L2, L3, L4, L5, L6 | 0805 | 6 | 1uH | C1042
L7 | L_Coilcraft_XAL4020-XXX | 1 | 1.5uH | C3033018
Q1, Q10, Q9 | SOT-23 | 3 | 2N7002 | C8545
R1, R46, R47 | 0603 | 3 | 100R | C22775
R10, R2, R6 | 0603 | 3 | 510R | C23193
R11, R3, R7 | 0603 | 3 | 49R9 | C23185
R12, R13, R58, R59 | 0603 | 4 | 1K5 | C22843
R14 | 0603 | 1 | 330R | C23138
R15, R16 | 1206 | 2 | 100R 250mW | C17901
R17 | 0603 | 1 | 20R | C22950
R18, R21, R45 | 0603 | 3 | 130K | C22795
R19, R20, R22, R24, R29, R30, R39, R41, R43, R44, R5, R51, R52, R54, R55, R56, R57, R60, R61, R62, R63, R64, R65, R66, R67, R68, R69, R71, R72, R80 | 0603 | 30 | 1K0 | C21190
R23 | 0603 | 1 | 22K | C31850
R25, R48, R8 | 0603 | 3 | 270R | C22966
R26 | 0603 | 1 | 22R0 | C23345
R27, R28, R76, R77, R78 | 0603 | 5 | 47K | C25819
R31 | 0603 | 1 | 120K | C25808
R32, R33, R34, R36 | 0603 | 4 | 4K7 | C23162
R35 | 0603 | 1 | 3K3 | C22978
R37, R38 | 0603 | 2 | 5K1 | C23186
R4 | 0603 | 1 | 200R | C8218
R42 | 1206 | 1 | 0R020 | C2765435
R50 | 0603 | 1 | 10K | C25804
R53, R75 | 0603 | 2 | 12K | C22790
R70 | 0603 | 1 | 150R | C22808
R73, R74 | 0603 | 2 | 47R | C23182
R79, R81, R82 | 1206 | 3 | 0R1 | C25334
R9 | 0603 | 1 | 2R0 | C22977
S1, S3 | SW_147873-2 | 2 | 147873-2 | C266189
SW1 | PBH4UOANAGX | 1 | SW_Push_4PDT | C273424
SW2 | SW_E-Switch_EG1224_SPDT_Angled | 1 | SW_SPDT | C273395
U1, U4, U5 | SOT-23-6 | 3 | ADA4807-1 | C2058411
U10 | LQFP-64_10x10mm_P0.5mm | 1 | STM32F405RGTx | C15742
U11 | SOT-223-3_TabPin2 | 1 | AMS1117-3.3 | C6186
U12 | DPAK172P1054X200-6N | 1 | BA50DD0WHFP-TR | C509718
U13 | SOIC-8_3.9x4.9mm_P1.27mm | 1 | M24C02-RMN | C83836
U14 | SOIC-16_3.9x9.9mm_P1.27mm | 1 | CH340C | C7464026
U15 | SOT-666 | 1 | USBLC6-2P6 | C2827693
U16, U6, U8 | SOT-363_SC-70-6 | 3 | TLV3603DCKR | C5213955
U17, U19, U2, U20, U21, U3, U7 | SOT-23-5 | 7 | SN74LVC1G14DBV | C133145
U18 | SOT-563 | 1 | TMP112AIDRLR | C28927
U23 | Texas_S-PWSON-N10_ThermalVias-CJ | 1 | TPS63060 | C48567
U9 | SOT-89-3 | 1 | L78L05_SOT89 | C71136
Y2 | Crystal_SMD_3225-4Pin_3.2x2.5mm | 1 | 16MHz | C13738

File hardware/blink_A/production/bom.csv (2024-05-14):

Designator | Footprint | Quantity | Value | LCSC Part #
C1, C12, C15, C18, C2, C20, C21, C22, C23, C24, C30, C31, C32 | 0402 | 13 | 100n | C307331
C10, C17, C27, C36, C4, C6, C9 | 0603 | 7 | 100n | C14663
C11, C14 | 0603 | 2 | 33p | C1663
C13, C26, C3, C33, C5, C7, C8 | 0603 | 7 | 10u | C19702
C16, C19 | 0603 | 2 | 2u2 | C23630
C25 | 0603 | 1 | 47p | C1671
C28, C29 | 0603 | 2 | 4u7 | C19666
C34, C35 | 0603 | 2 | 10u | C96446
C38, C39, C40 | 0805 | 3 | 22uF | C45783
D1 | 0805 | 1 | LED | C130114
D4 | LED_RGB_MHS110FRGBCT | 1 | LED_ABGR | C496820
J1 | JST_PH_S2B-PH-SM4-TB_1x02-1MP_P2.00mm_Horizontal | 1 | Conn_01x02 | C295747
J11, J12, J13, J4 | BNC_Amphenol_B6252HB-NPP3G-50_Horizontal-CJ | 4 | KH-BNC50-3511 | C2837587
J2, J3 | Jack_3.5mm_PJ320D_Horizontal-CJ | 2 | PJ-320D | C431535
J6 | JST_PH_S3B-PH-SM4-TB_1x03-1MP_P2.00mm_Horizontal | 1 | Conn_01x03 | C265101
J9 | USB_C_Receptacle_HRO_TYPE-C-31-M-12 | 1 | USB_C_Receptacle | C165948
L1 | L_Coilcraft_XAL4020-XXX | 1 | 1.5uH | C3033018
Q3, Q4, Q5 | SOT-23 | 3 | 2N7002 | C8545
R1, R13, R16, R19, R2 | 0603 | 5 | 560R | C23204
R10, R11, R17, R20, R23, R25, R27, R28, R29, R35, R36, R42, R43, R44, R45, R49, R5, R50, R54, R56, R57 | 0603 | 21 | 1K0 | C21190
R12, R15 | 0603 | 2 | 1K5 | C22843
R21, R22 | 0603 | 2 | 5K1 | C23186
R24 | 0603 | 1 | 200R | C8218
R26, R31, R32, R33, R40, R41 | 0603 | 6 | 4K7 | C23162
R3, R39, R4, R51, R52, R53, R59, R9 | 0603 | 8 | 47K | C25819
R30 | 0603 | 1 | 2K0 | C22975
R37, R38, R62 | 1206 | 3 | 0R1 | C25334
R46 | 0603 | 1 | 150R | C22808
R47, R48 | 0603 | 2 | 47R | C23182
R58 | 0603 | 1 | 5.6K | C23189
R6 | 0603 | 1 | 10K | C25804
R60 | 0603 | 1 | 33R0 | C23140
R7 | 0603 | 1 | 1R0 | C22936
R8 | 0603 | 1 | 100K | C25803
SW1 | SW_E-Switch_EG1224_SPDT_Angled | 1 | SW_SPDT | C273395
SW2, SW3, SW4 | PBH4UOANAGX | 3 | SW_Push_4PDT | C273424
U1, U13 | SOT-223-3_TabPin2 | 2 | AMS1117-3.3 | C6186
U10 | SOT-563 | 1 | TMP112AIDRLR | C28927
U11, U12 | SOT-23-5 | 2 | MAX40200AUK | C2649430
U14, U5, U6 | SOT-23-5 | 3 | SN74LVC1G14DBV | C133145
U16 | Texas_S-PWSON-N10_ThermalVias | 1 | TPS63060 | C48567
U2 | SOIC-8_3.9x4.9mm_P1.27mm | 1 | AD8397 | C578714
U3 | SOIC-8_3.9x4.9mm_P1.27mm | 1 | M24C02-RMN | C83836
U4 | LQFP-64_10x10mm_P0.5mm | 1 | STM32F405RGTx | C15742
U7 | SOIC-16_3.9x9.9mm_P1.27mm | 1 | CH340C | C84681
U8 | SOT-666 | 1 | USBLC6-2P6
U9 | SOT-23-5 | 1 | MCP73832-2-OT | C424093
Y1 | Crystal_SMD_3225-4Pin_3.2x2.5mm | 1 | 16MHz | C13738

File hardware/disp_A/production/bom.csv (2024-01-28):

Designator | Footprint | Quantity | Value | LCSC Part #
C32, C36, C38 | 0402 | 3 | 100n | C307331
D1, D10, D11, D4, D5, D6, D62, D63, D7, D8, D9 | 0603 | 11 | LED-R | C94869
D12, D13, D14, D15, D16, D17, D18, D19, D2, D20, D21, D22, D23, D24, D25, D26, D27, D28, D29, D30, D31, D32, D33, D34, D35, D36, D37, D38, D39, D40, D41, D42, D43, D44, D45, D46, D47, D48, D49, D50, D51, D52, D53, D54, D55, D56, D57, D58, D59, D60, D61 | 0603 | 51 | LED-G | C125093
D3 | 0603 | 1 | LED-Y | C72038
Q1, Q10, Q11, Q12, Q13, Q2, Q3, Q4, Q5, Q6, Q7, Q8, Q9 | SOT-23 | 13 | 2N7002 | C8545
R1, R2, R29, R30, R31, R34, R36, R38, R4, R40, R42, R44, R46, R48, R49, R50, R51, R52, R53, R55, R56, R57, R6 | 0603 | 23 | 100R | C22775
R3, R33, R35, R37, R39, R41, R43, R45, R47, R5 | 0603 | 10 | 4K7 | C23162

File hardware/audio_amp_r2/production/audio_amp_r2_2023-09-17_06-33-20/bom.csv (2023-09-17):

Designator | Footprint | Quantity | Value | LCSC Part #
C1, C3, C8 | 0805 | 3 | 0.1uF | C49678
C2, C6, C7 | 0805 | 3 | 10uF | C15850
C4 | CP_EIA-3528-21_Kemet-B | 1 | 100uF | C16133
C5 | CP_EIA-3216-18_Kemet-A | 1 | 10uF | C7171
J1, J2 | Jack_3.5mm_PJ320D_Horizontal-CJ | 2 | PJ-320D | C431535
J3 | JST_PH_S2B-PH-SM4-TB_1x02-1MP_P2.00mm_Horizontal | 1 | JST_PH_1x02 | C295747
J6, J7 | BNC_Amphenol_B6252HB-NPP3G-50_Horizontal-CJ | 2 | KH-BNC50-3511 | C2837587
J8 | PinHeader_1x04_P2.54mm_Vertical | 1 | Conn_01x04_Pin | C2883761
R1, R11, R2, R8 | 0805 | 4 | 47k | C17713
R12 | 0805 | 1 | 100R | C17408
R3 | 0805 | 1 | 1K | C17513
R4 | 0805 | 1 | 22K | C17560
R5, R6, R9 | 0805 | 3 | 560R | C28636
R7 | 0805 | 1 | 10K | C17414
U1 | SOIC-8_3.9x4.9mm_P1.27mm | 1 | AD8397 | C578714

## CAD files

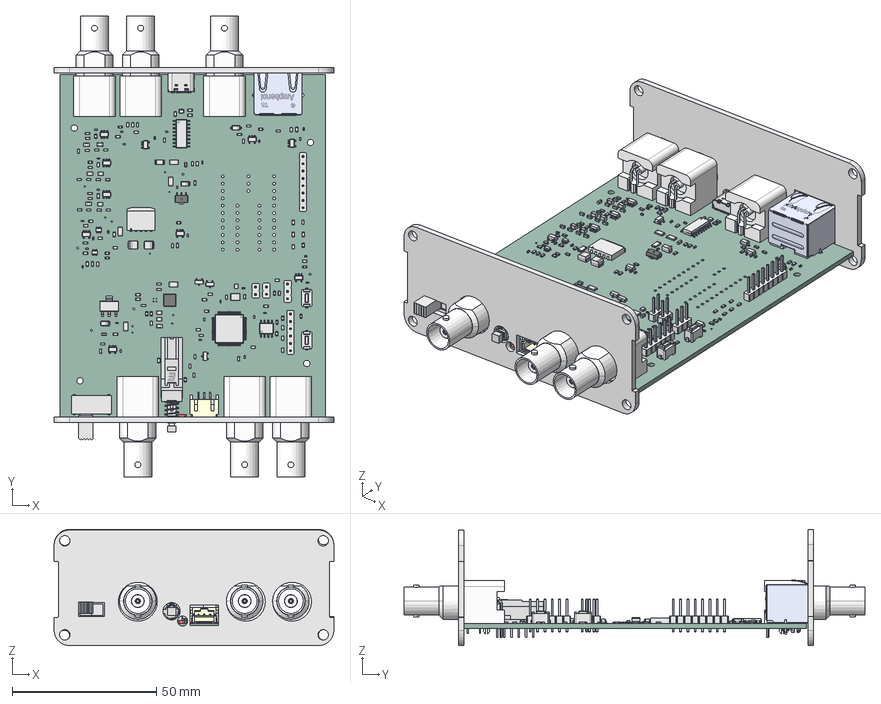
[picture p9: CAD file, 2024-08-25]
box/clockBoxA.FCStd
96.9 x 159.6 x 40.2 mm
Back
Front
C_0402_1005Metric
CP_EIA_3528_21_Kemet_B
R_0603_1608Metric
R_0603_1608Metric225
R_0603_1608Metric226
C_0603_1608Metric
C_0402_1005Metric055
C_0402_1005Metric056
R_0603_1608Metric227
R_0603_1608Metric228
D_SOD_123
R_0603_1608Metric229
SOT_23_5
R_0603_1608Metric231
R_0603_1608Metric233
R_0603_1608Metric235
SOT_23_017
R_0603_1608Metric237
R_1206_3216Metric
R_0603_1608Metric239
C_0603_1608Metric087
R_0603_1608Metric241
L_0805_2012Metric
L_0805_2012Metric002
Crystal_SMD_3225-4Pin_3.2x2.5mm
C_0603_1608Metric089
SOT_666
R_0603_1608Metric243
S3B-PH-SM4-TB(LF)(SN)
S3B-PH-SM4-TB(LF)(SN)001
S3B-PH-SM4-TB(LF)(SN)002
S3B-PH-SM4-TB(LF)(SN)003
S3B-PH-SM4-TB(LF)(SN)004
S3B-PH-SM4-TB(LF)(SN)005
C_0603_1608Metric091
C_0402_1005Metric058
R_0603_1608Metric245
CP_EIA_3216_18_Kemet_A
R_0603_1608Metric247
C_0402_1005Metric060
R_0603_1608Metric249
SW_E-Switch_EG1224_SPDT_Angled
R_0603_1608Metric251
CP_EIA_3216_18_Kemet_A001
R_0603_1608Metric253
R_0603_1608Metric255
R_0603_1608Metric257
C_0603_1608Metric093
C_0603_1608Metric095
PinHeader_1x08_P254mm_Vertical
SOT_23_018
R_0603_1608Metric259
C_0603_1608Metric097
C_0805_2012Metric
C_0402_1005Metric062
CP_EIA_3528_21_Kemet_B001
RJHSEx380x
R_1206_3216Metric013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

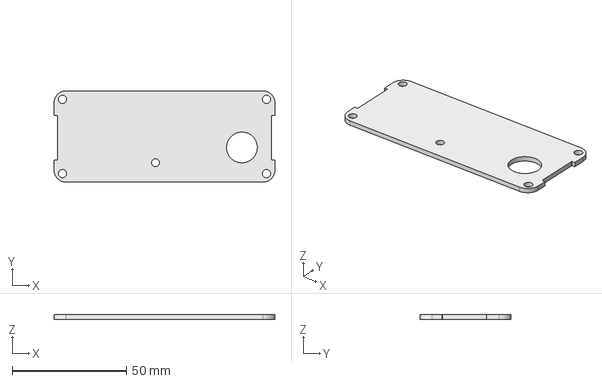
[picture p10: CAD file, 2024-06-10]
box/prod/gpsBoxA-Front.step
96.9 x 40.0 x 2.00 mm

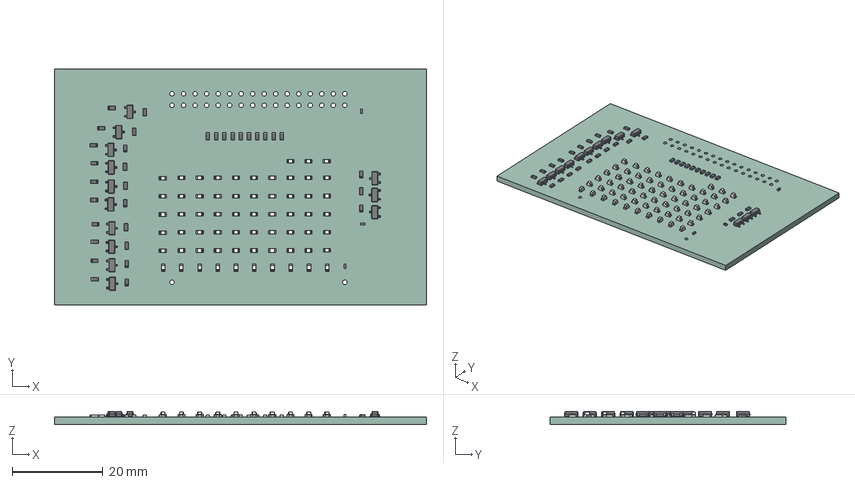
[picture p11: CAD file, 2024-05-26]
hardware/disp_A/production/disp_A.step
82.0 x 52.0 x 2.85 mm
LED_0603_1608Metric x 63
R_0603_1608Metric x 33
SOT_23 x 13
C_0402_1005Metric x 3
disp_A_PCB

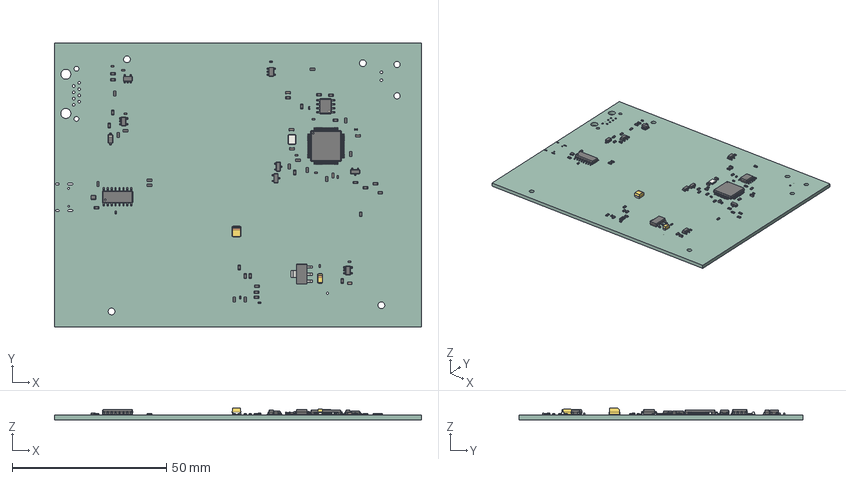
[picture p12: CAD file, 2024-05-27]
hardware/gps_A/production/gps_A.step
119.0 x 92.0 x 3.75 mm
C_0402_1005Metric x 15
R_0603_1608Metric x 38
C_0603_1608Metric x 6
D_SOD_123
SOT_23_5 x 4
Crystal_SMD_3225-4Pin_3.2x2.5mm
SOT_666
CP_EIA_3216_18_Kemet_A
CP_EIA_3528_21_Kemet_B
SOT_223
SOT_23 x 3
SOIC_8_39x49mm_P127mm
LQFP_64_10x10mm_P05mm
SOIC_16_39x99mm_P127mm
_autosave-gps_A_PCB

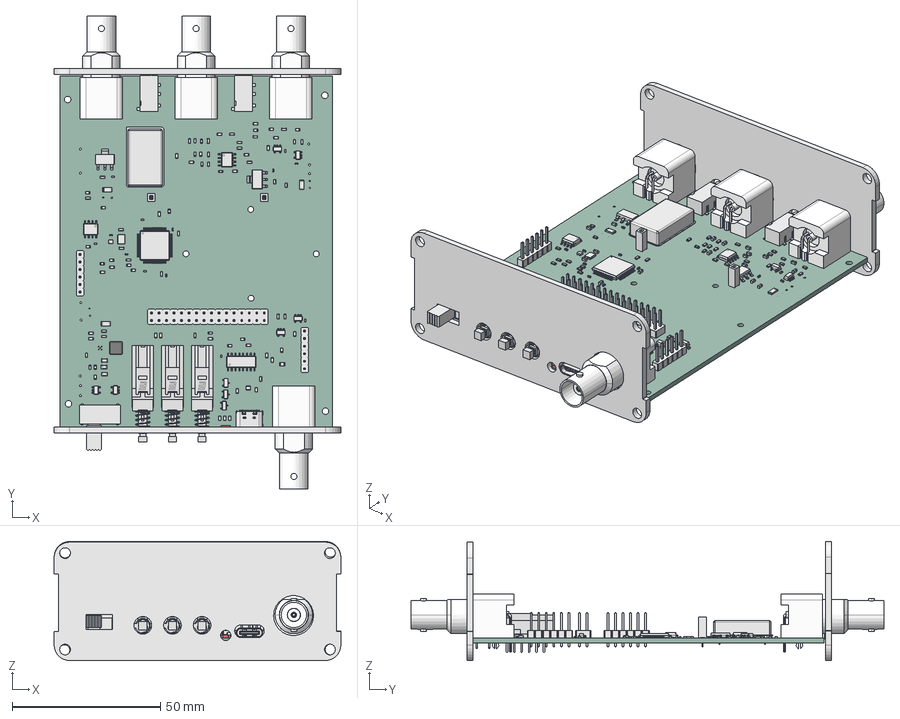
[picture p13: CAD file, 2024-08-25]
box/blinkBoxA.FCStd
96.9 x 159.8 x 40.2 mm
Back
Front
C_0603_1608Metric040
SOT_669
C_0603_1608Metric042
R_0603_1608Metric116
R_1206_3216Metric006
C_0402_1005Metric028
R_0603_1608Metric118
R_0603_1608Metric120
SOT_23_011
R_0603_1608Metric122
R_0603_1608Metric124
R_0603_1608Metric126
PBH4UxxNAGX006
C_0603_1608Metric044
C_0603_1608Metric046
C_0603_1608Metric048
R_0603_1608Metric128
Crystal_SMD_3225-4Pin_3.2x2.5mm002
SOIC_16_39x99mm_P127mm001
C_0603_1608Metric050
R_0603_1608Metric130
R_0603_1608Metric132
R_0603_1608Metric134
C_0603_1608Metric052
PinHeader_2x16_P254mm_Vertical001
R_0603_1608Metric136
SOT_670
PBH4UxxNAGX008
R_0603_1608Metric138
SOT_23_012
PinHeader_1x06_P254mm_Vertical002
C_0402_1005Metric030
R_0603_1608Metric140
SOT_23_013
C_0603_1608Metric054
R_0603_1608Metric142
R_0603_1608Metric144
SOT_671
C_0603_1608Metric056
R_0603_1608Metric146
SOT_672
R_0603_1608Metric148
SOT_673
SOT_23_014
C_0402_1005Metric032
C_0402_1005Metric034
R_0603_1608Metric150
C_0402_1005Metric036
PJ-320D-A
PJ-320D-A001
PJ-320D-A002
PJ-320D-A003
PJ-320D-A004
C_0603_1608Metric058
R_0603_1608Metric152
C_0402_1005Metric038
C_0603_1608Metric060
C_0603_1608Metric062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

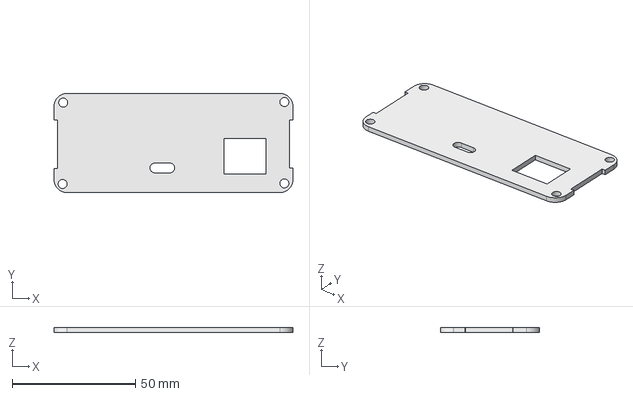
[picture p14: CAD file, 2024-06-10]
box/prod/gpsBoxA-Back.step
96.9 x 40.2 x 2.00 mm

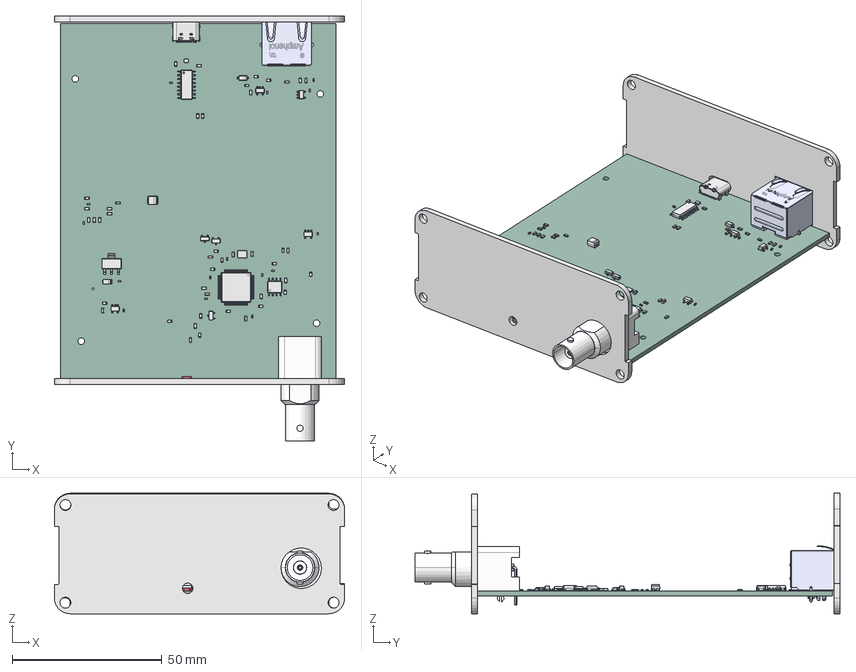
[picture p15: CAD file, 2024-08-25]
box/gpsBoxA.FCStd
96.9 x 141.8 x 40.2 mm
Back
Front
C_0402_1005Metric110
R_0603_1608Metric369
R_0603_1608Metric370
C_0603_1608Metric139
C_0402_1005Metric112
R_0603_1608Metric371
R_0603_1608Metric372
D_SOD_124
SOT_23_025
R_0603_1608Metric373
SOT_23_026
C_0603_1608Metric140
Crystal_SMD_3225-4Pin_3.2x2.5mm005
R_0603_1608Metric374
SOT_678
R_0603_1608Metric375
R_0603_1608Metric376
CP_EIA_3216_18_Kemet_A002
R_0603_1608Metric377
C_0402_1005Metric114
CP_EIA_3528_21_Kemet_B002
RJHSEx380x001
C_0603_1608Metric141
C_0402_1005Metric116
C_0402_1005Metric118
SOT_679
C_0402_1005Metric120
SOT_680
R_0603_1608Metric378
R_0603_1608Metric379
R_0603_1608Metric380
TYPE-C-31-M-12
TYPE-C-31-M-098
TYPE-C-31-M-099
TYPE-C-31-M-100
TYPE-C-31-M-101
TYPE-C-31-M-102
TYPE-C-31-M-103
TYPE-C-31-M-104
TYPE-C-31-M-105
TYPE-C-31-M-106
TYPE-C-31-M-107
TYPE-C-31-M-108
TYPE-C-31-M-109
TYPE-C-31-M-110
TYPE-C-31-M-111
TYPE-C-31-M-112
TYPE-C-31-M-113
TYPE-C-31-M-114
TYPE-C-31-M-115
TYPE-C-31-M-116
TYPE-C-31-M-117
TYPE-C-31-M-118
TYPE-C-31-M-119
TYPE-C-31-M-120
TYPE-C-31-M-121
TYPE-C-31-M-122
TYPE-C-31-M-123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

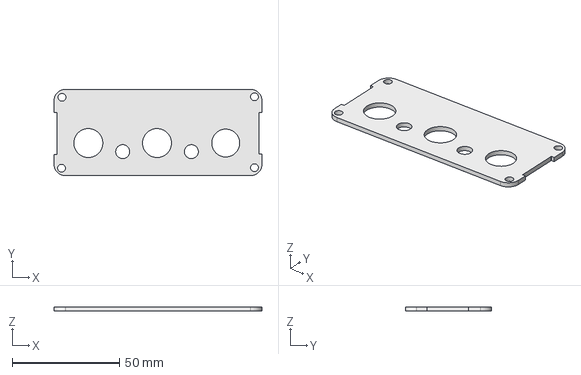
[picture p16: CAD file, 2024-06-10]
box/prod/blinkBoxA-Back.step
96.9 x 40.2 x 2.00 mm

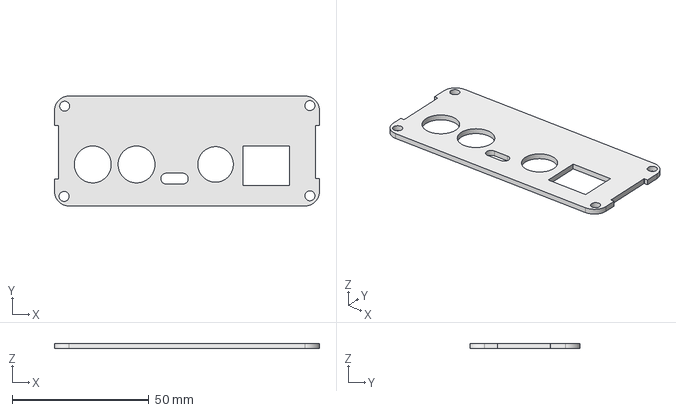
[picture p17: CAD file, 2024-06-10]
box/prod/clockBoxA-Back.step
96.9 x 40.2 x 2.00 mm

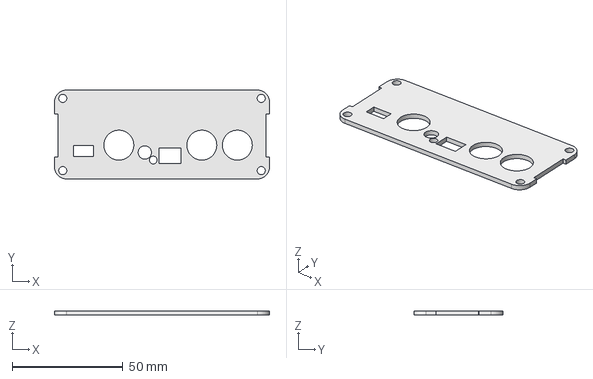
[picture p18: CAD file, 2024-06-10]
box/prod/clockBoxA-Front.step
96.9 x 40.0 x 2.00 mm

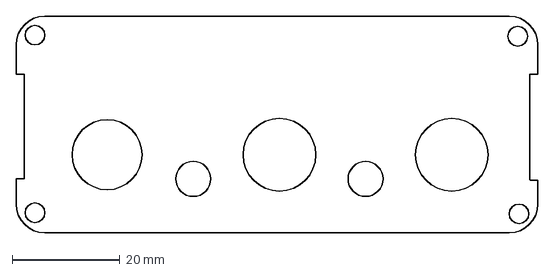
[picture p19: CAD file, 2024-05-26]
box/prod/blink-back.dxf
96.9 x 40.2 mm

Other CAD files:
box/prod/blinkBoxA-Front.step
box/prod/gpsA-front.step
box/prod/gpsA-back.step
box/prod/blinkA-front.step
box/prod/blinkA-back.step
box/prod/clockA-back.step
box/prod/clockA-front.step
box/prod/blinkA-back.dxf
box/prod/blinkBoxA-Back.3mf
box/prod/blinkBoxA-Back.dxf
box/prod/blinkBoxA-BlinkBoxABack.step
box/prod/blinkBoxA-Front.3mf
box/prod/blinkBoxA-Front.dxf
box/prod/clockA-back.dxf
box/prod/clockBoxA-Back.3mf
box/prod/clockBoxA-Back.dxf
box/prod/clockBoxA-BlinkBoxAFront.step
box/prod/clockBoxA-Front.3mf
box/prod/clockBoxA-Front.dxf
box/prod/gpsA-back.dxf
box/prod/gpsA-front.dxf
box/prod/gpsBoxA-Back.3mf
box/prod/gpsBoxA-Back.dxf
box/prod/gpsBoxA-Front.3mf
box/prod/gpsBoxA-Front.dxf

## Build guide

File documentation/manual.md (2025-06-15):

# Manual for Blink Box

This is the manual for V1.0 software on Rev A hardware.

## Overview

The blink box has a grid of LEDs that blink at a fix rate and are
synchronized to other blink box. The camera of a video conferencing device
can be pointed at one box, the send that the video conferencing system to
a screen. At the screen end, a photo is take of the screen of another
synchronized blink box. By looking at the image of the blink box on
screen, and the time that represents, and comparing it to the time
displayed by the local box, the overall camera glass to screen glass
latency can be computed.

Once the devices are synchronized, they will stay synchronized for over
10 hours.

## Controls and Display

### Buttons

Mute Button ( black  ): The audio beep used in testing can be very
irritating. This button turn the generation of the audio beep on and off.

Blank Button ( white  ): This control what is displayed on the LED
grid and cycles across three modes. In the first mode nothing is
displayed, in the second the detected audio latency is displayed, and in
the third, the time is displayed for video testing.

Sync Button ( red ):

### Status LED:

Red: Error. Look at USB serial to get more information.

Purple: Bad power. The USB port can not deliver enough power to run the
oscillator.

Blue: Not Synchronized. The output time is not synchronized and no
synchronization input is detected.

Teal: Could Sync. The output is not synchronized but an input sync signal
is detected. Pressing the sync button should cause the device to become
synchronized.

Green: Synchronized. The output has been synchronized with the device
connected to the sync input.

### LED grid

The main green LEDs display one green LED at a time and advance to the
next LED at a rate of 240 Hz. They display 4 across then go to the next
row. This results in the rows advancing at 30 Hz and there are 10 rows.

The red LEDs advance at a rate of 3 Hz and only the first 3 are used.

To read the time in frames for a 30 fps system, the user would look at
the red LEDs and take if it was 1,2 or 3rd and multiple that by 10 then
add which would give the frame numbers in the second.

Yellow LEDs: The first LED indicates an error, the second if the device
is synchronized or not, and the third if there is an input synchronization
signal detected or not.

## Video Latency Measurement

Two blink boxes are used called primary and secondary. The secondary will
synchronize it's time to the primary. The sync output of the primary is
connected to sync input of the secondary. This should cause the status
LED of the secondary to changes from blue to teal. At this point the sync
button can be pressed and the secondary should go to green to indicate
it is syhncrozed. The primary will remain blue.

The blank button is pressed once or twice to get into the mode where
video is showing timing data on both boxes.

The video camera of the input is pointed at the primary and relays that
video to screen at the output end. The secondary is set up beside the
output screen and a photo is take that captures both the screen and
secondary at the same time.

By looking at the photo, it is possible to see how far behind in time the
image on the screen is from the current time n the secondary unit which
provided the one way glass to glass latency of the system.

## Loss of Synchronization

They synchronization remains valid for about an hour on uncalibrated
system and over 10 hours on a calibrated system.

## Audio Latency Measurement

An headset need to be plugged into the headset jack of the blink
box. Without this, the computer will not detect there is a headset. A
cable is from the computer audio jack computer jack of the blink
box. For mobile devices, use a lightning or USB to 1/8 inch TRRS
adapter. The headsets can be used to check the that audio is working
thought the video conferencing system.

On the primary device, press mute button to toggle on off audio beep and
make sure you can hear it on the headset of the secondary device. You
may need to play with volume levels.

There are three ways to look at the audio latency. The first is to put
the display into audio mode and it will be displayed on the LEDs. TODO
explain reading. The second is plug the USB port into a computer and use
it as a serial connection which will print the latency. That is explain
in the uSB second. The last is to use the Speaker / Mic output jacks
and feed the mic from the primary and speaker from the secondary into a
two channel oscilloscope to measure the latency.

## Inputs and Outputs

### USB

The USB port provides a serial interface at 115200 baud, 8 bit, no
parity, 1 stop bit.

```
pyserial-miniterm -e --parity N --rts 0 --dtr 0  115200
```

The RTS and DTR do need to be low for the serial interface to work and
not all terminal programs support this.

The device of /dev/cu.usbserial-31110 would change but the easiest way to
find it is look at what devices are there before turning the blink box
on then what device are there after it is turned on.

### Sync in / out

The Sync in and out use Linear Time Codes to send and receive time.

### Headset and Computer Audio

These allow the blink box to be in the middle of the audio connection
and listening to audio going to the headset and sound coming from the mic
as well as inject synthetic audio beeps.

### Speaker / Mic

This allows an tap of what is going in mic or out speaker at amplified
levels that are appropriate for recording or sending to an
oscilloscope. The PicoScope 2204A is very nice for this.

## Mounting

Some iPad mounts and tripods can be used to hold the blink box in a good location.

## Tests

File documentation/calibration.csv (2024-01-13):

Date | Calibration | Product | Rev | Serial | OscType | intOsc | vcoValue | minError(ns) | maxError(ns) | slope(ns/vco)
11/1/23 | 53220A | Blink | EV6 | 1 | 2 |  | 1940 | 2 | 2 | -7.2
11/1/23 | 53220A | Blink | EV6 | 2 | 2 |  | 1950 | 13 | 13 | -6.3
11/26/23 | 53220A | Blink | EV8 | 3 | 2 | -542 |  | -14 | 8 | -0.3
11/26/23 | TM2500C | Clock | EV8 | 4 | 10 |  | 3250 | -18 | 6 | -0.015
11/26/23 | 53220A | Clock | EV8 | 5 | 0 | -658 |  | 144 | 160
11/26/23 | 53220A | Blink | EV8 | 6 | 2 | -534 |  | -10 | 8 | -0.3
1/7/24 | TM2500C | Clock | EV9.0 | 10 | 10 |  | 3300 | -12 | 8 | -0.01
1/7/24 | TM2500C | Blink | EV9.0 | 11 | 2 |  | 2750 | -10 | 16 | -0.25
1/7/24 | TM2500C | Blink | EV9.0 | 7 | 0 | -535 |  | -32 | 42 | 90
1/7/24 | TM2500C | Clock | EV9.1 | 12 | 0 | -566 |  | -40 | 190 | 75
1/12/24 | TM2500C | Blink | EV9.0 | 7 | 2 |  | 625 | -16 | 13 | -0.4

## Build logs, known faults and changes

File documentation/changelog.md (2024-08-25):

# 1.1 Software Changes

# Rev B  Harware Changes

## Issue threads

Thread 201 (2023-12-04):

Order Parts for Rev A

fluffy, 2023-12-04:
Order Stuff to build Rev A version
2 of the clock unit
5 of GPS unit
10 of Blink

- [x] nuts
- [x] washers
- [x] buttons
- [x] battery
- [x] battery tape
- [x] clock oscillators
- [x] blink oscillator
- [x] 6x2 gps end plates
- [x] 4x2 clock end plates
- [x] 12x2 blink end plates
- [x] boxes
- [x] bolts for boxes
- [ ] usb cables
- [ ] gps units
- [ ] plexiglass for disp window display
- [ ] audio cables
- [ ] headsets
- [x] 3 clock PCB
- [x] 6 GPS  PCB
- [x] 12 Blink PCB

Closed 2024-08-25.

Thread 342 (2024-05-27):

Build units for Rev A

fluffy, 2024-05-27:
- [ ] Cut box windows
- [x] Glue in box windows
- [ ] Solder display to blink boards
- [x] Solder headers & Osc
- [x] Engrave labels
- [x] Init flash and firmware
- [ ] Rough Calibration
- [x] Assemble box
- [ ] Burn in
- [ ] Final Calbration
- [ ] Final Test

Closed 2025-06-13.

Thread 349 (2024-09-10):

buttons labels wrong on end plates

fluffy, 2024-09-10:
1/2 plates are wrong

Closed 2025-06-15.

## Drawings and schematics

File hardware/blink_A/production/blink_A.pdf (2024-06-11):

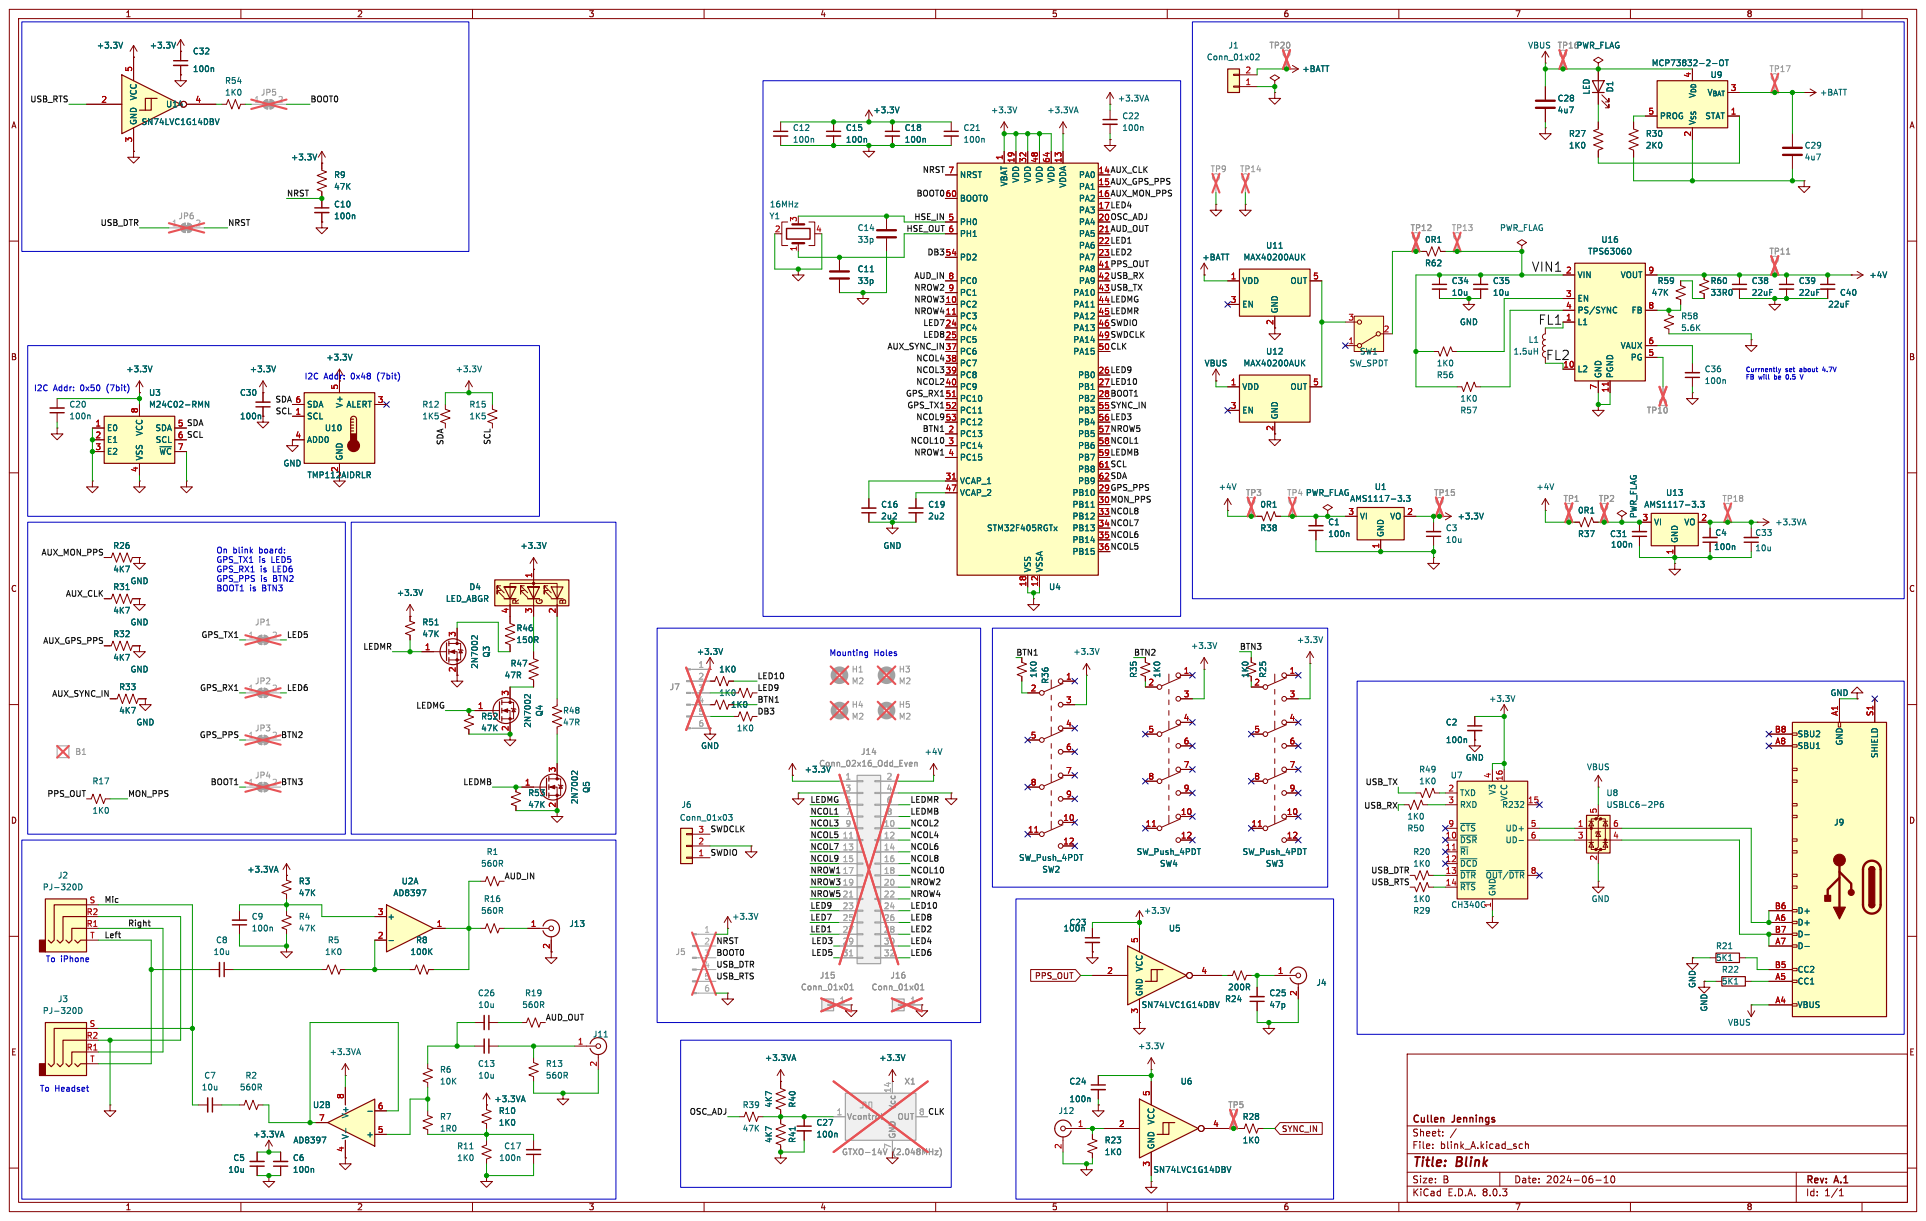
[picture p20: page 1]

1 PC2 10 PC3 11 VSSA 12 VDDA 13 PA0 14 PA1 15 PA2 16 PA3 17 VSS 18 VDD 19 PC13 2 PA4 20 PA5 21 PA6 22 PA7 23 PC4 24 PC5 25 PB0 26 PB1 27 PB2 28 PB10 29 PC14 3 PB11 30 VCAP_1 31 VDD 32 PB12 33 PB13 34 PB14 35 PB15 36 PC6 37 PC7 38 PC8 39 PC15 4 PC9 40 PA8 41 PA9 42 PA10 43 PA11 44 PA12 45 PA13 46 VCAP_2 47 VDD 48 PA14 49 PH0 5 PA15 50 PC10 51 PC11 52 PC12 53 PD2 54 PB3 55 PB4 56 PB5 57 PB6 58 PB7 59 PH1 6 BOOT0 60 PB8 61 PB9 62 VDD 64 NRST 7 PC0 8 PC1 9 +3.3V R60

1 PC2 10 PC3 11 VSSA 12 VDDA 13 PA0 14 PA1 15 PA2 16 PA3 17 VSS 18 VDD 19 PC13 2 PA4 20 PA5 21 PA6 22 PA7 23 PC4 24 PC5 25 PB0 26 PB1 27 PB2 28 PB10 29 PC14 3 PB11 30 VCAP_1 31 VDD 32 PB12 33 PB13 34 PB14 35 PB15 36 PC6 37 PC7 38 PC8 39 PC15 4 PC9 40 PA8 41 PA9 42 PA10 43 PA11 44 PA12 45 PA13 46 VCAP_2 47 VDD 48 PA14 49 PH0 5 PA15 50 PC10 51 PC11 52 PC12 53 PD2 54 PB3 55 PB4 56 PB5 57 PB6 58 PB7 59 PH1 6 BOOT0 60 PB8 61 PB9 62 VDD 64 NRST 7 PC0 8 PC1 9 U4 STM32F405RGTx R60

FB will be 0.5 V Mounting Holes

4 SDA 5 SCL 6 ~{WC}7 VCC

1 ~{DSR} 10 ~{RI} 11 ~{DCD} 12 ~{DTR} 13 ~{RTS} 14 R232 VCC 15 16 TXD 2 RXD 3 V3

4 UD+ 5 UD- 6 ~{OUT}/~{DTR} 8 ~{CTS} 9U7CH340C

To iPhone To Headset

File: blink_A.kicad_sch Sheet: / Cullen Jennings

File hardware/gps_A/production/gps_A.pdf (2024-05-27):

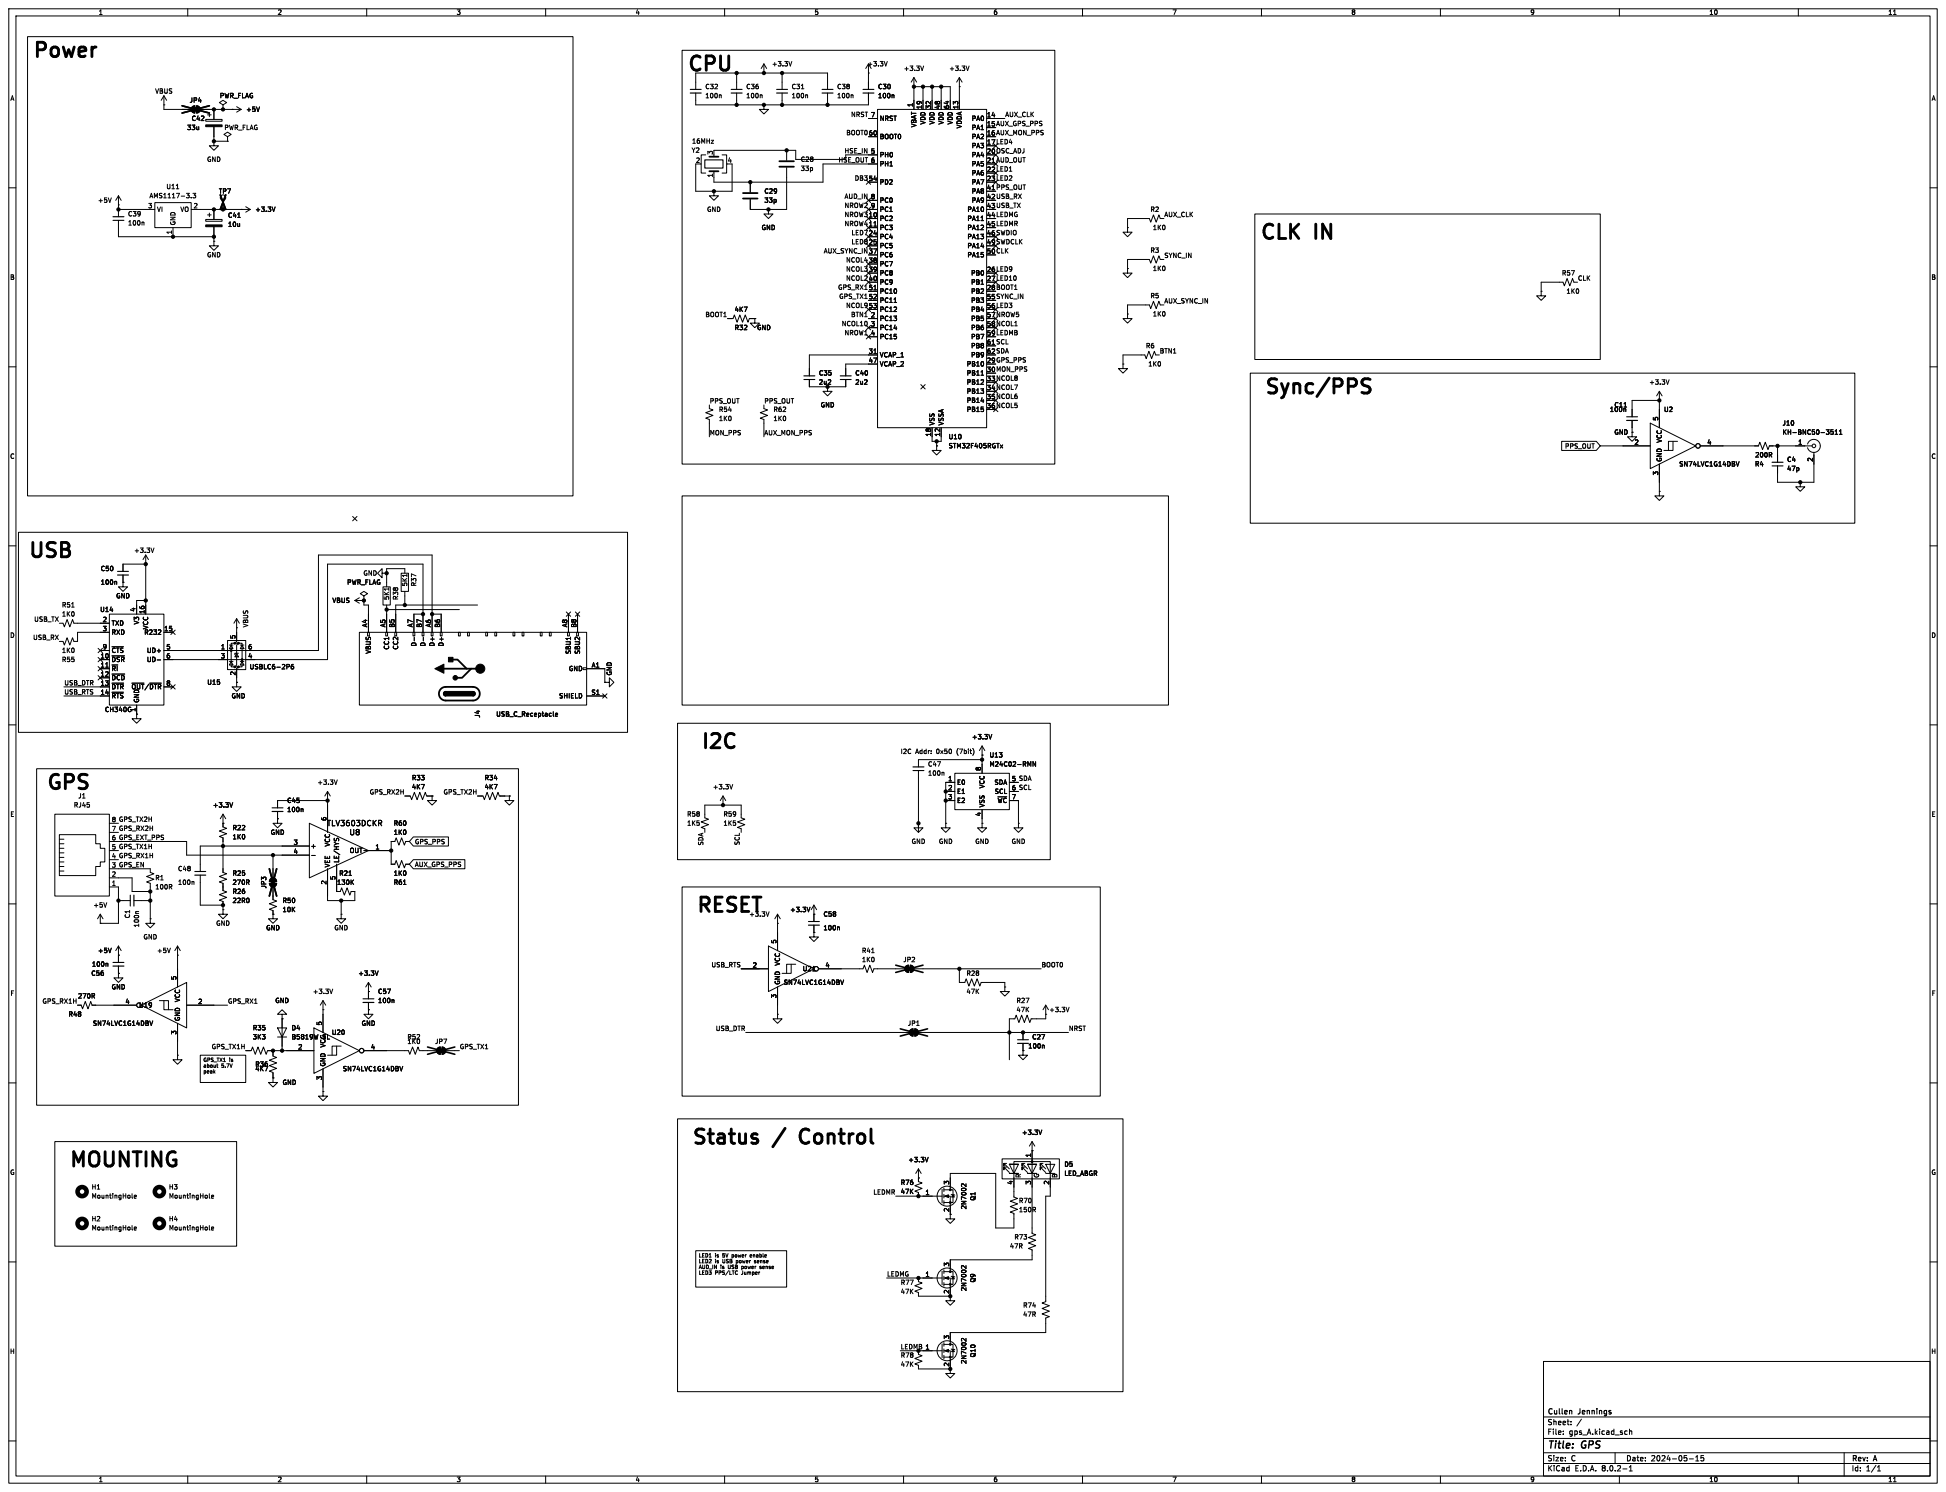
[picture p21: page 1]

LED3 PPS/LTC Jumper GPS_TX1 is about 5.7V

LED1 is 5V power enable
LED2 is USB power sense AUD_IN is USB power sense

File: gps_A.kicad_sch Sheet: / Cullen Jennings

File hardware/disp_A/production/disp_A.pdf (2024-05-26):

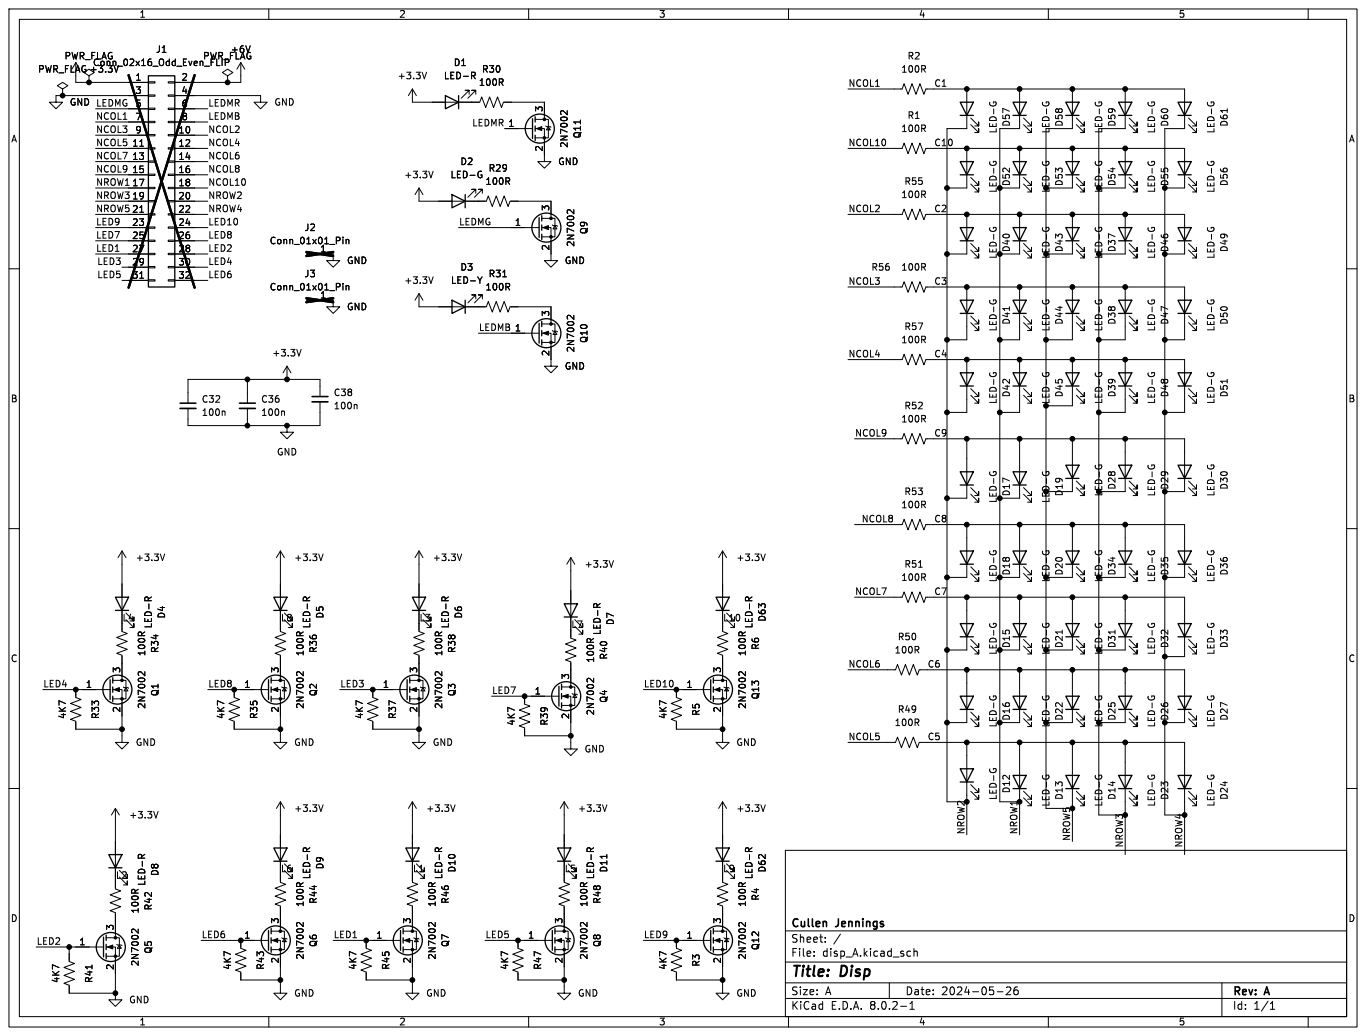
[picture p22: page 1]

File: disp_A.kicad_sch Sheet: / Cullen Jennings

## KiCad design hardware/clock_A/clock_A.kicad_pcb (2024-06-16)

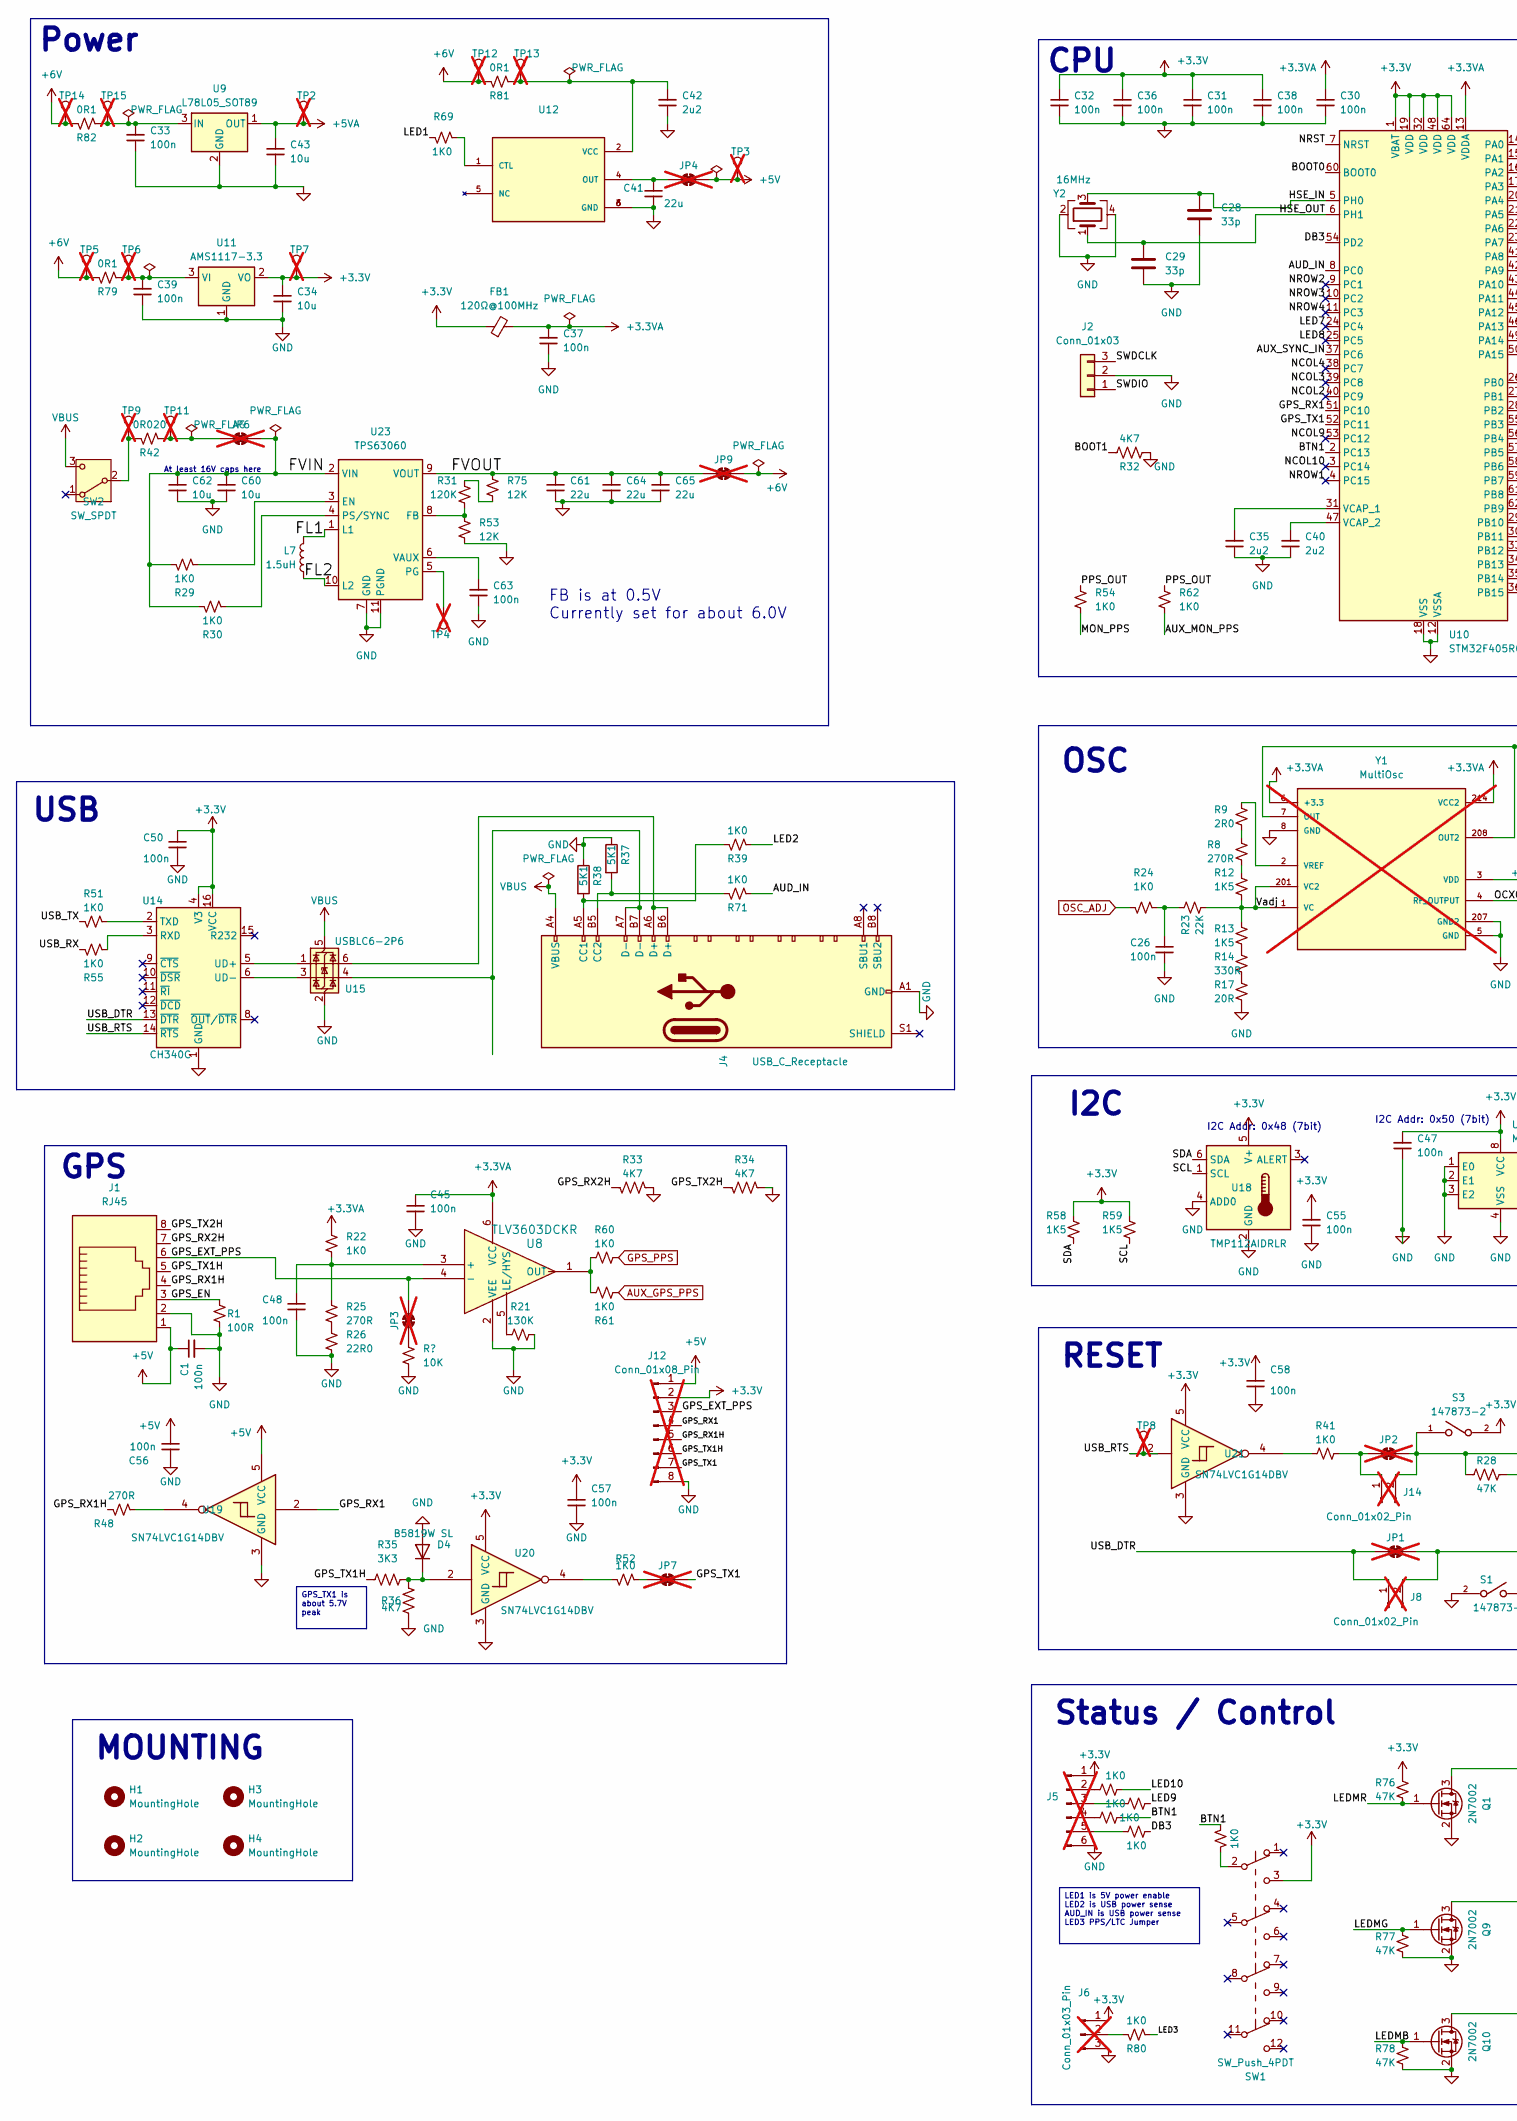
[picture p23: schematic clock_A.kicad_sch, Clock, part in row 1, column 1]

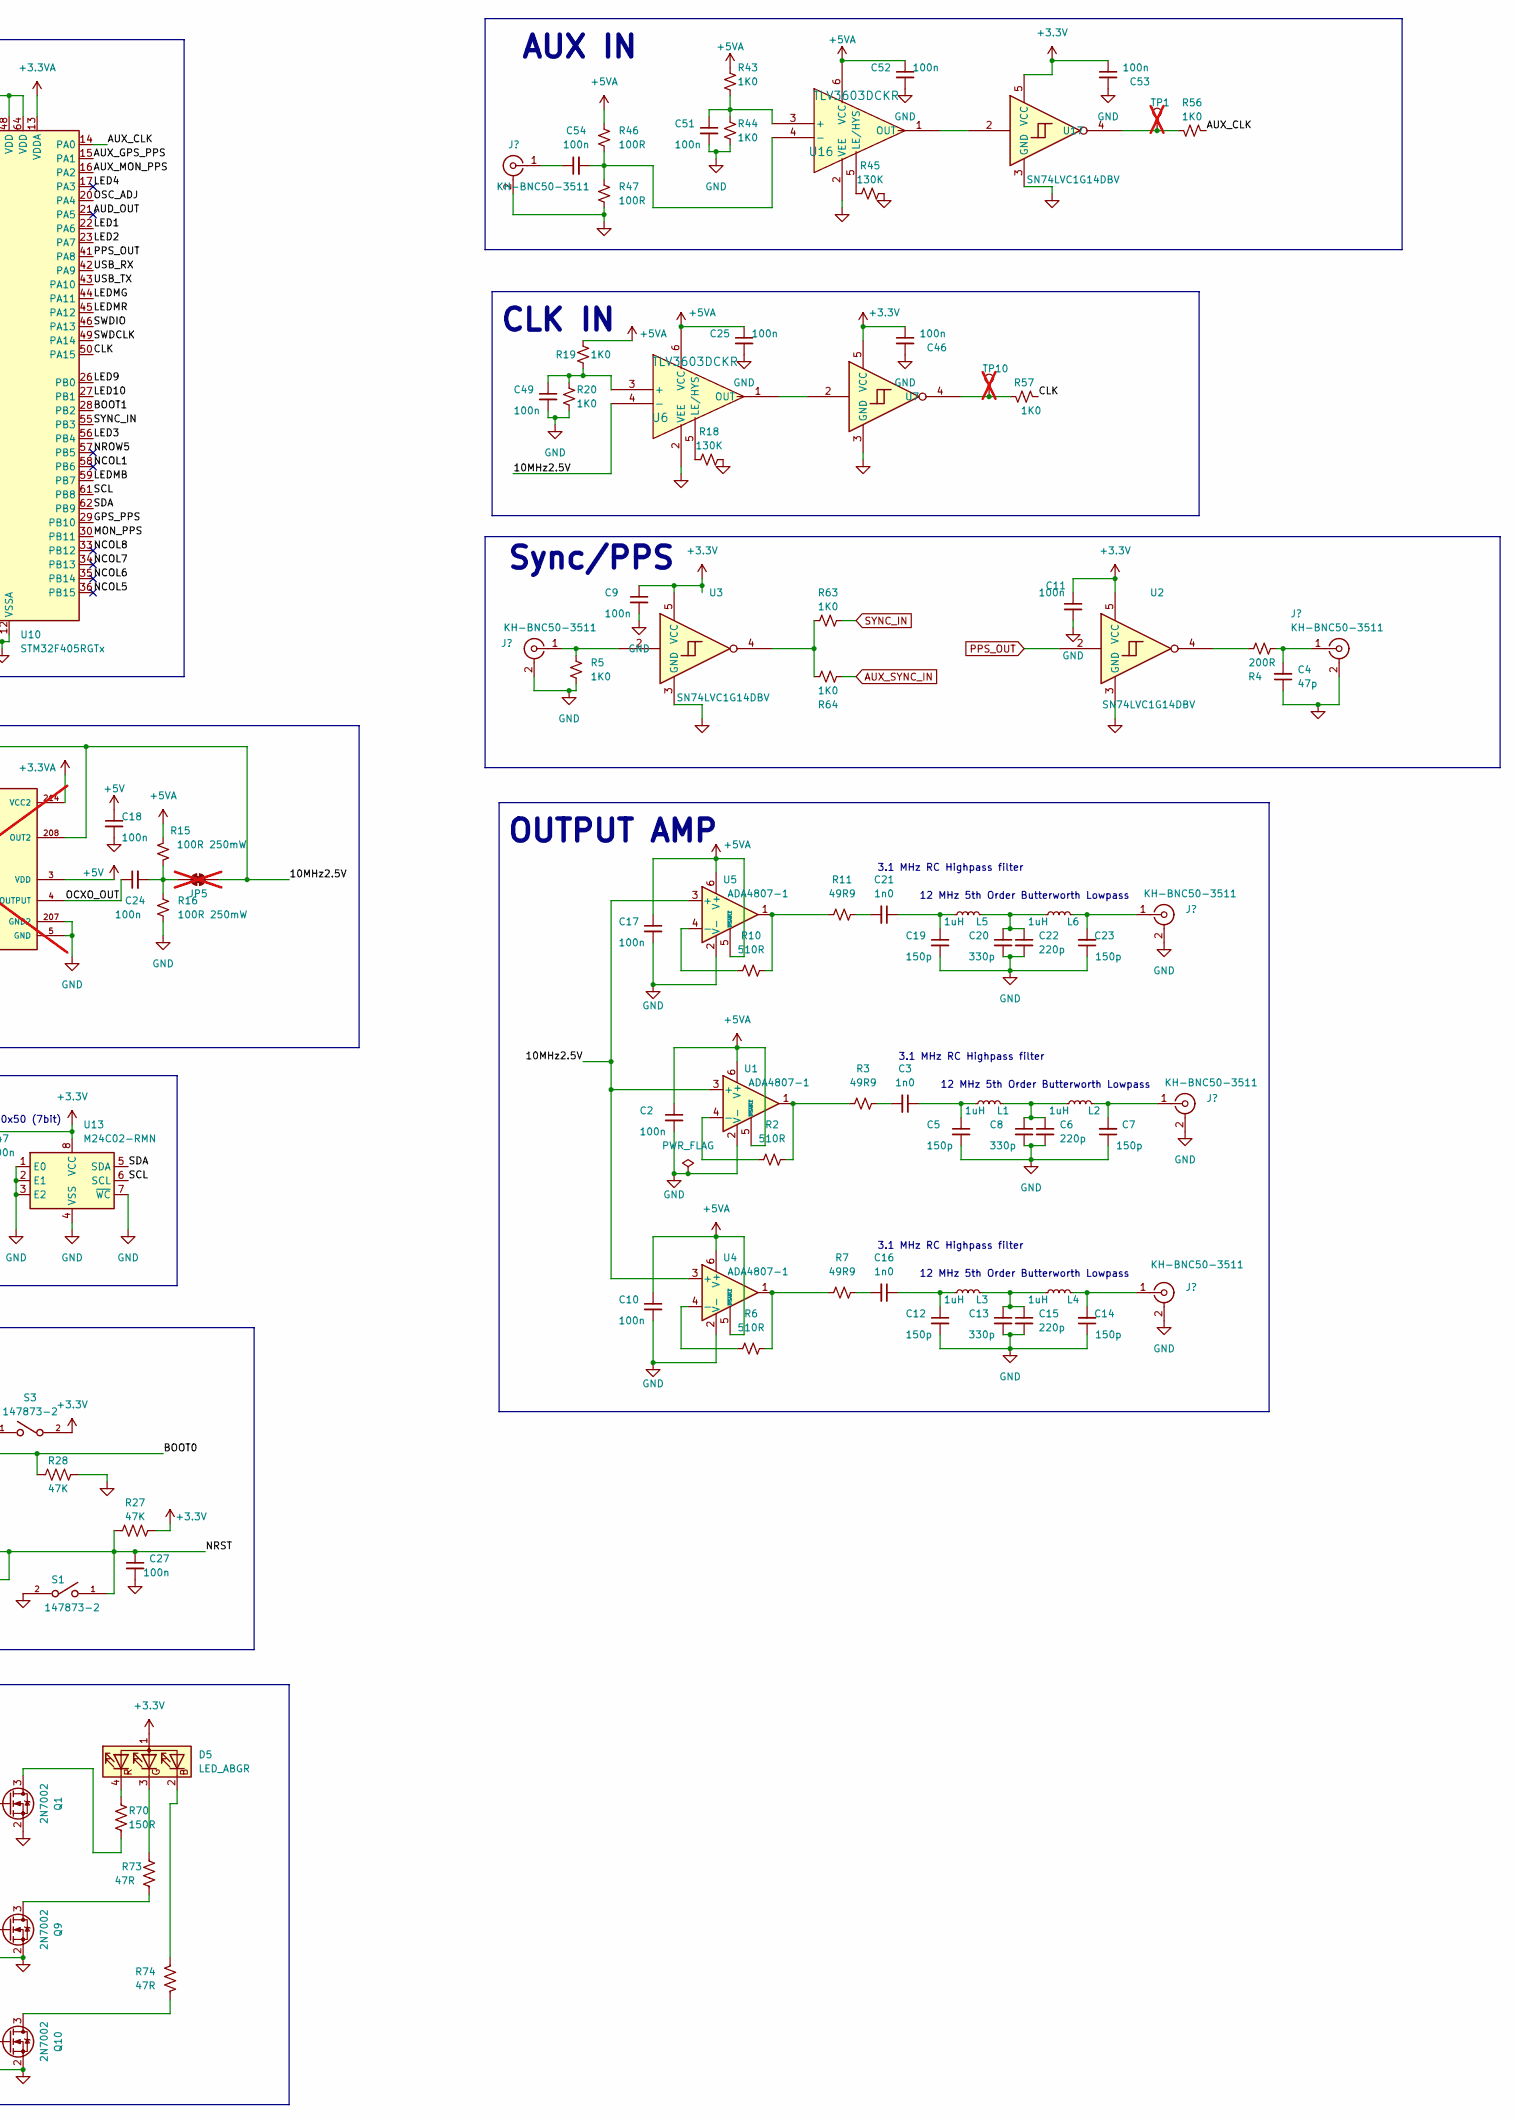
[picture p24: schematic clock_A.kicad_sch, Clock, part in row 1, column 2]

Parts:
C1, C2, C9, C10, C11, C17, C18, C25, C26, C30, C31, C32, C33, C36, C38, C39, C45, C46, C47, C48, C49, C50, C51, C52, C53, C55, C56, C57, C58: 100n; C_0402_1005Metric; JLCPCB Part # C307331
C3, C16, C21: 1n0; C_0603_1608Metric; JLCPCB Part # C1588
C4: 47p; C_0603_1608Metric; JLCPCB Part # C1671
C5, C7, C12, C14, C19, C23: 150p; C_0603_1608Metric; JLCPCB Part # C1594
C6, C15, C22: 220p; C_0603_1608Metric; JLCPCB Part # C1603
C8, C13, C20: 330p; C_0603_1608Metric; JLCPCB Part # C1664
C24, C27, C37, C54, C63: 100n; C_0603_1608Metric; JLCPCB Part # C14663
C28, C29: 33p; C_0603_1608Metric; JLCPCB Part # C1663
C34, C43, C60, C62: 10u; C_0603_1608Metric; JLCPCB Part # C96446
C35, C40, C42: 2u2; C_0603_1608Metric; JLCPCB Part # C23630
C41, C61, C64, C65: 22u; C_0805_2012Metric; JLCPCB Part # C45783
D4: B5819W SL; D_SOD-123; JLCPCB Part # C8598
D5: LED_ABGR; LED_RGB_MHS110FRGBCT; MPN MHS110FRGBCT; JLCPCB Part # C496820
FB1: 120Ω@100MHz; R_0603_1608Metric; JLCPCB Part # C127301
H1, H2, H3, H4: MountingHole; MountingHole_2.2mm_M2
J1: RJ45; RJ45_Amphenol_RJHSE5380; JLCPCB Part # C464586
J2: Conn_01x03; JST_PH_S3B-PH-SM4-TB_1x03-1MP_P2.00mm_Horizontal; JLCPCB Part # C265101
J3, J7, J9, J10, J11, J13: KH-BNC50-3511; BNC_Amphenol_B6252HB-NPP3G-50_Horizontal-CJ; JLCPCB Part # C2837587
J4: USB_C_Receptacle; USB_C_Receptacle_HRO_TYPE-C-31-M-12; JLCPCB Part # C165948
J5: Conn_01x06_Pin; PinHeader_1x06_P2.54mm_Vertical; not fitted
J6: Conn_01x03_Pin; PinHeader_1x03_P2.54mm_Vertical; not fitted
J8, J14: Conn_01x02_Pin; PinHeader_1x02_P2.54mm_Vertical; not fitted
J12: Conn_01x08_Pin; PinHeader_1x08_P2.54mm_Vertical; not fitted
JP1, JP2, JP3, JP4, JP5, JP6, JP7, JP9: SolderJumper_2_Bridged; SolderJumper-2_P1.3mm_Bridged2Bar_RoundedPad1.0x1.5mm; not fitted
L1, L2, L3, L4, L5, L6: 1uH; L_0805_2012Metric; JLCPCB Part # C1042
L7: 1.5uH; L_Coilcraft_XAL4020-XXX; MPN XFL4020-152MEC; JLCPCB Part # C3033018
Q1, Q9, Q10: 2N7002; SOT-23; JLCPCB Part # C8545
R1, R46, R47: 100R; R_0603_1608Metric; JLCPCB Part # C22775
R2, R6, R10: 510R; R_0603_1608Metric; JLCPCB Part # C23193
R3, R7, R11: 49R9; R_0603_1608Metric; JLCPCB Part # C23185
R4: 200R; R_0603_1608Metric; JLCPCB Part # C8218
R5, R19, R20, R22, R24, R29, R30, R39, R41, R43, R44, R51, R52, R54, R55, R56, R57, R60, R61, R62, R63, R64, R65, R66, R67, R68, R69, R71, R72, R80: 1K0; R_0603_1608Metric; JLCPCB Part # C21190
R8, R25, R48: 270R; R_0603_1608Metric; JLCPCB Part # C22966
R9: 2R0; R_0603_1608Metric; JLCPCB Part # C22977
R12, R13, R58, R59: 1K5; R_0603_1608Metric; JLCPCB Part # C22843
R14: 330R; R_0603_1608Metric; JLCPCB Part # C23138
R15, R16: 100R 250mW; R_1206_3216Metric; JLCPCB Part # C17901
R17: 20R; R_0603_1608Metric; JLCPCB Part # C22950
R18, R21, R45: 130K; R_0603_1608Metric; JLCPCB Part # C22795
R23: 22K; R_0603_1608Metric; JLCPCB Part # C31850
R26: 22R0; R_0603_1608Metric; JLCPCB Part # C23345
R27, R28, R76, R77, R78: 47K; R_0603_1608Metric; JLCPCB Part # C25819
R31: 120K; R_0603_1608Metric; JLCPCB Part # C25808
R32, R33, R34, R36: 4K7; R_0603_1608Metric; JLCPCB Part # C23162
R35: 3K3; R_0603_1608Metric; JLCPCB Part # C22978
R37, R38: 5K1; R_0603_1608Metric; JLCPCB Part # C23186
R42: 0R020; R_1206_3216Metric; JLCPCB Part # C2765435
R50: 10K; R_0603_1608Metric; JLCPCB Part # C25804
R53, R75: 12K; R_0603_1608Metric; JLCPCB Part # C22790
R70: 150R; R_0603_1608Metric; JLCPCB Part # C22808
R73, R74: 47R; R_0603_1608Metric; JLCPCB Part # C23182
R79, R81, R82: 0R1; R_1206_3216Metric; JLCPCB Part # C25334
S1, S3: 147873-2; SW_147873-2; JLCPCB Part # C266189
SW1: SW_Push_4PDT; PBH4UOANAGX; JLCPCB Part # C273424
SW2: SW_SPDT; SW_E-Switch_EG1224_SPDT_Angled; JLCPCB Part # C273395
TP1, TP2, TP3, TP4, TP5, TP6, TP7, TP8, TP9, TP10, TP11, TP12, TP13, TP14, TP15: TestPoint_THTPad_D1.0mm_Drill0.5mm; not fitted
U1, U4, U5: ADA4807-1; SOT-23-6; JLCPCB Rotation Offset 90
U2, U3, U7, U17, U19, U20, U21: SN74LVC1G14DBV; SOT-23-5; JLCPCB Part # C133145
U6, U8, U16: TLV3603DCKR; SOT-363_SC-70-6; JLCPCB Part # C5213955
U9: L78L05_SOT89; SOT-89-3; JLCPCB Part # C71136
U10: STM32F405RGTx; LQFP-64_10x10mm_P0.5mm; JLCPCB Part # C15742
U11: AMS1117-3.3; SOT-223-3_TabPin2; JLCPCB Part # C6186
U12: BA50DD0WHFP-TR; DPAK172P1054X200-6N; PARTREV 003; JLCPCB Position Offset -1.5,0
U13: M24C02-RMN; SOIC-8_3.9x4.9mm_P1.27mm; JLCPCB Part # C83836
U14: CH340C; SOIC-16_3.9x9.9mm_P1.27mm; JLCPCB Part # C7464026
U15: USBLC6-2P6; SOT-666; JLCPCB Part # C2827693
U18: TMP112AIDRLR; SOT-563; JLCPCB Part # C28927
U23: TPS63060; Texas_S-PWSON-N10_ThermalVias-CJ; JLCPCB Part # C48567
Y1: MultiOsc; XTAL_Multi; not fitted
Y2: 16MHz; Crystal_SMD_3225-4Pin_3.2x2.5mm; JLCPCB Part # C13738

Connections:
+3.3V: C9.1, C11.1, C31.1, C32.1, C34.1, C36.1, C38.1, C46.1, C47.2, C50.1, C53.1, C55.2, C57.1, C58.1, D5.1 (A), FB1.1, J5.1, J6.1, J12.2, R27.1, R58.1, R59.1, R76.1, S3.2, SW1.3 (C), TP7.1, U2.5 (VCC), U3.5 (VCC), U7.5 (VCC), U10.1 (VBAT), U10.19 (VDD), U10.32 (VDD), U10.48 (VDD), U10.64 (VDD), U11.2 (VO), U13.8 (VCC), U14.4 (V3), U14.16 (VCC), U17.5 (VCC), U18.5 (V+), U20.5 (VCC), U21.5 (VCC)
+3.3VA: C30.1, C37.2, C45.1, FB1.2, R22.1, U8.6 (VCC), U10.13 (VDDA), Y1.6 (+3.3), Y1.214 (VCC2)
+5V: C1.1, C18.1, C56.1, J1.1, J12.1, JP4.2 (B), TP3.1, U19.5 (VCC), Y1.3 (VDD)
+5VA: C2.1, C10.1, C17.1, C25.1, C43.1, C52.1, R15.1, R19.1, R43.1, R46.1, TP2.1, U1.5 (~DISABLE), U1.6 (V+), U4.5 (~DISABLE), U4.6 (V+), U5.5 (~DISABLE), U5.6 (V+), U6.6 (VCC), U9.1 (OUT), U16.6 (VCC)
+6V: JP9.2 (B), R79.2, R81.2, R82.2, TP5.1, TP12.1, TP14.1
/10MHz2.5V: JP5.1 (A), U1.3 (+), U4.3 (+), U5.3 (+), U6.4 (-), Y1.7 (OUT), Y1.208 (OUT2)
/AUD_IN: R71.2, U10.8 (PC0)
/AUD_OUT: U10.21 (PA5)
/AUX_CLK: R56.1, U10.14 (PA0)
/AUX_MON_PPS: R62.2, U10.16 (PA2)
/BOOT0: J14.2, JP2.2 (B), R28.1, S3.1, U10.60 (BOOT0)
/BOOT1: R32.2, U10.28 (PB2)
/BTN1: R66.1, R72.2, U10.2 (PC13)
/CLK: R57.1, U10.50 (PA15)
/DB3: R68.1, U10.54 (PD2)
/FL1: L7.1, U23.1 (L1)
/FL2: L7.2, U23.10 (L2)
/FVIN: C60.1, C62.1, JP6.2 (B), R29.1, R30.1, U23.2 (VIN)
/FVOUT: C61.1, C64.1, C65.1, JP9.1 (A), R75.1, U23.9 (VOUT)
/GPS_EN: J1.3, R1.1
/GPS_EXT_PPS: J1.6, J12.3, JP3.2 (B), U8.4 (-)
/GPS_RX1: J12.4, U10.51 (PC10), U19.2
/GPS_RX1H: J1.4, J12.5, R48.2
/GPS_RX2H: J1.7, R33.2
/GPS_TX1: J12.7, JP7.2 (B), U10.52 (PC11)
/GPS_TX1H: J1.5, J12.6, R35.2
/GPS_TX2H: J1.8, R34.2
/HSE_IN: C28.1, U10.5 (PH0), Y2.3
/HSE_OUT: C29.1, U10.6 (PH1), Y2.1
/LED1: R69.2, U10.22 (PA6)
/LED2: R39.2, U10.23 (PA7)
/LED3: R80.1, U10.56 (PB4)
/LED4: U10.17 (PA3)
/LED7: U10.24 (PC4)
/LED8: U10.25 (PC5)
/LED9: R67.1, U10.26 (PB0)
/LED10: R65.1, U10.27 (PB1)
/LEDMB: Q10.1 (G), R78.1, U10.59 (PB7)
/LEDMG: Q9.1 (G), R77.1, U10.44 (PA11)
/LEDMR: Q1.1 (G), R76.2, U10.45 (PA12)
/MON_PPS: R54.2, U10.30 (PB11)
/NCOL1: U10.58 (PB6)
/NCOL2: U10.40 (PC9)
/NCOL3: U10.39 (PC8)
/NCOL4: U10.38 (PC7)
/NCOL5: U10.36 (PB15)
/NCOL6: U10.35 (PB14)
/NCOL7: U10.34 (PB13)
/NCOL8: U10.33 (PB12)
/NCOL9: U10.53 (PC12)
/NCOL10: U10.3 (PC14)
/NROW1: U10.4 (PC15)
/NROW2: U10.9 (PC1)
/NROW3: U10.10 (PC2)
/NROW4: U10.11 (PC3)
/NROW5: U10.57 (PB5)
/NRST: C27.1, J8.2, JP1.2 (B), R27.2, S1.1, U10.7 (NRST)
/OCXO_OUT: C24.1, Y1.4 (RF_OUTPUT)
/SCL: R59.2, U10.61 (PB8), U13.6 (SCL), U18.1 (SCL)
/SDA: R58.2, U10.62 (PB9), U13.5 (SDA), U18.6 (SDA)
/SWDCLK: J2.3, U10.49 (PA14)
/SWDIO: J2.1, U10.46 (PA13)
/USB_DTR: J8.1, JP1.1 (A), U14.13 (~DTR)
/USB_RTS: TP8.1, U14.14 (~RTS), U21.2
/USB_RX: R55.1, U10.42 (PA9)
/USB_TX: R51.2, U10.43 (PA10)
/Vadj: R12.2, R13.1, R23.2, Y1.1 (VC), Y1.201 (VC2)
AUX_GPS_PPS: R61.2, U10.15 (PA1)
AUX_SYNC_IN: R64.1, U10.37 (PC6)
GND: C1.2, C2.2, C4.1, C5.2, C6.2, C7.1, C8.2, C9.2, C10.2, C11.2, C12.2, C13.2, C14.1, C15.2, C17.2, C18.2, C19.2, C20.2, C22.2, C23.1, C25.2, C26.2, C27.2, C28.2, C29.2, C30.2, C31.2, C32.2, C33.1, C34.2, C35.1, C36.2, C37.1, C38.2, C39.1, C40.1, C41.2, C42.1, C43.2, C45.2, C46.2, C47.1, C48.2, C49.2, C50.2, C51.2, C52.2, C53.2, C55.1, C56.2, C57.2, C58.2, C60.2, C61.2, C62.2, C63.1, C64.2, C65.2, D4.2 (A), J1.2, J2.2, J3.2 (Ext), J4.A1 (GND), J4.A12 (GND), J4.B1 (GND), J4.B12 (GND), J5.6, J6.3, J7.2 (Ext), J9.2 (Ext), J10.2 (Ext), J11.2 (Ext), J12.8, J13.2 (Ext), Q1.2 (S), Q9.2 (S), Q10.2 (S), R1.2, R5.2, R16.2, R17.2, R18.2, R20.2, R21.2, R26.2, R28.2, R32.1, R33.1, R34.1, R36.1, R37.1, R38.1, R44.2, R45.2, R47.2, R50.2, R53.2, R77.2, R78.2, S1.2, U1.2 (V-), U2.3 (GND), U3.3 (GND), U4.2 (V-), U5.2 (V-), U6.2 (VEE), U7.3 (GND), U8.2 (VEE), U9.2 (GND), U10.12 (VSSA), U10.18 (VSS), U10.63 (VSS), U11.1 (GND), U12.3 (GND), U12.6 (GND), U13.1 (E0), U13.2 (E1), U13.3 (E2), U13.4 (VSS), U13.7 (~WC), U14.1 (GND), U15.2 (GND), U16.2 (VEE), U17.3 (GND), U18.2 (GND), U18.4 (ADD0), U19.3 (GND), U20.3 (GND), U21.3 (GND), U23.7 (GND), U23.11 (PGND), Y1.5 (GND), Y1.8 (GND), Y1.207 (GND2), Y2.2, Y2.4
GPS_PPS: R60.1, U10.29 (PB10)
unnamed: C3.1, C5.1, L1.1
unnamed: C3.2, R3.2
unnamed: C6.1, C8.1, L1.2, L2.2
unnamed: C12.1, C16.1, L3.1
unnamed: C13.1, C15.1, L3.2, L4.2
unnamed: C16.2, R7.2
unnamed: C19.1, C21.1, L5.1
unnamed: C20.1, C22.1, L5.2, L6.2
unnamed: C21.2, R11.2
unnamed: C26.1, R23.1, R24.1
unnamed: D4.1 (K), R35.1, R36.2, U20.2
unnamed: D5.2 (BK), R74.1
unnamed: D5.3 (GK), R73.2
unnamed: D5.4 (RK), R70.2
unnamed: C23.2, J3.1 (In), L6.1
unnamed: J4.A5 (CC1), R38.2, R39.1
unnamed: J4.B5 (CC2), R37.2, R71.1
unnamed: J4.A6 (D+), J4.B6 (D+), U15.6 (I/O1)
unnamed: J4.A7 (D-), J4.B7 (D-), U15.4 (I/O2)
unnamed: J5.2, R65.2
unnamed: J5.3, R67.2
unnamed: J5.4, R66.2
unnamed: J5.5, R68.2
unnamed: J6.2, R80.2
unnamed: C54.1, J7.1 (In)
unnamed: J9.1 (In), R5.1, U3.2
unnamed: C4.2, J10.1 (In), R4.2
unnamed: C14.2, J11.1 (In), L4.1
unnamed: C7.2, J13.1 (In), L2.1
unnamed: J14.1, JP2.1 (A), R41.2
unnamed: JP3.1 (A), R50.1
unnamed: C41.1, JP4.1 (A), U12.4 (OUT)
unnamed: C24.2, JP5.2 (B), R15.2, R16.1
unnamed: JP6.1 (A), R42.1, TP11.1
unnamed: JP7.1 (A), R52.1
unnamed: Q1.3 (D), R70.1
unnamed: Q9.3 (D), R73.1
unnamed: Q10.3 (D), R74.2
unnamed: R2.2, R3.1, U1.1
unnamed: R4.1, U2.4
unnamed: R6.2, R7.1, U4.1
unnamed: R8.1, R9.2
unnamed: R10.2, R11.1, U5.1
unnamed: R8.2, R12.1
unnamed: R13.2, R14.1
unnamed: R14.2, R17.1
unnamed: R25.2, R26.1
unnamed: R31.1, R75.2
unnamed: R41.1, U21.4
unnamed: R48.1, U19.4
unnamed: R52.2, U20.4
unnamed: R56.2, TP1.1, U17.4
unnamed: R57.2, TP10.1, U7.4
unnamed: R63.2, R64.2, U3.4
unnamed: R72.1, SW1.2 (B)
unnamed: R42.2, SW2.2 (B), TP9.1
unnamed: R2.1, U1.4 (-)
unnamed: R6.1, U4.4 (-)
unnamed: R10.1, U5.4 (-)
unnamed: C49.1, R19.2, R20.1, U6.3 (+)
unnamed: R18.1, U6.5 (LE/HYS)
unnamed: U6.1 (OUT), U7.2
unnamed: C48.1, R22.2, R25.1, U8.3 (+)
unnamed: R21.1, U8.5 (LE/HYS)
unnamed: R60.2, R61.1, U8.1 (OUT)
unnamed: C33.2, R82.1, TP15.1, U9.3 (IN)
unnamed: C35.2, U10.31 (VCAP_1)
unnamed: C40.2, U10.47 (VCAP_2)
unnamed: C39.2, R79.1, TP6.1, U11.3 (VI)
unnamed: R69.1, U12.1 (CTL)
unnamed: C42.2, R81.1, TP13.1, U12.2 (VCC)
unnamed: R55.2, U14.3 (RXD)
unnamed: R51.1, U14.2 (TXD)
unnamed: U14.5 (UD+), U15.1 (I/O1)
unnamed: U14.6 (UD-), U15.3 (I/O2)
unnamed: C51.1, R43.2, R44.1, U16.3 (+)
unnamed: C54.2, R46.2, R47.1, U16.4 (-)
unnamed: R45.1, U16.5 (LE/HYS)
unnamed: U16.1 (OUT), U17.2
unnamed: R29.2, U23.3 (EN)
unnamed: R31.2, R53.1, U23.8 (FB)
unnamed: TP4.1, U23.5 (PG)
unnamed: R30.2, U23.4 (PS/SYNC)
unnamed: C63.2, U23.6 (VAUX)
unnamed: R9.1, Y1.2 (VREF)
OSC_ADJ: R24.2, U10.20 (PA4)
PPS_OUT: R54.1, R62.1, U2.2, U10.41 (PA8)
SYNC_IN: R63.1, U10.55 (PB3)
VBUS: J4.A4 (VBUS), J4.A9 (VBUS), J4.B4 (VBUS), J4.B9 (VBUS), SW2.3 (C), U15.5 (VBUS)

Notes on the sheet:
LED1 is 5V power enable LED2 is USB power sense AUD_IN is USB power sense LED3 PPS/LTC Jumper
GPS_TX1 is about 5.7V peak
At least 16V caps here
AUX IN
RESET
OUTPUT AMP
USB
3.1 MHz RC Highpass filter
GPS
CPU
I2C
Status / Control
Sync/PPS
CLK IN
MOUNTING
12 MHz 5th Order Butterworth Lowpass
FB is at 0.5V Currently set for about 6.0V
I2C Addr: 0x48 (7bit)
I2C Addr: 0x50 (7bit)
OSC
Power

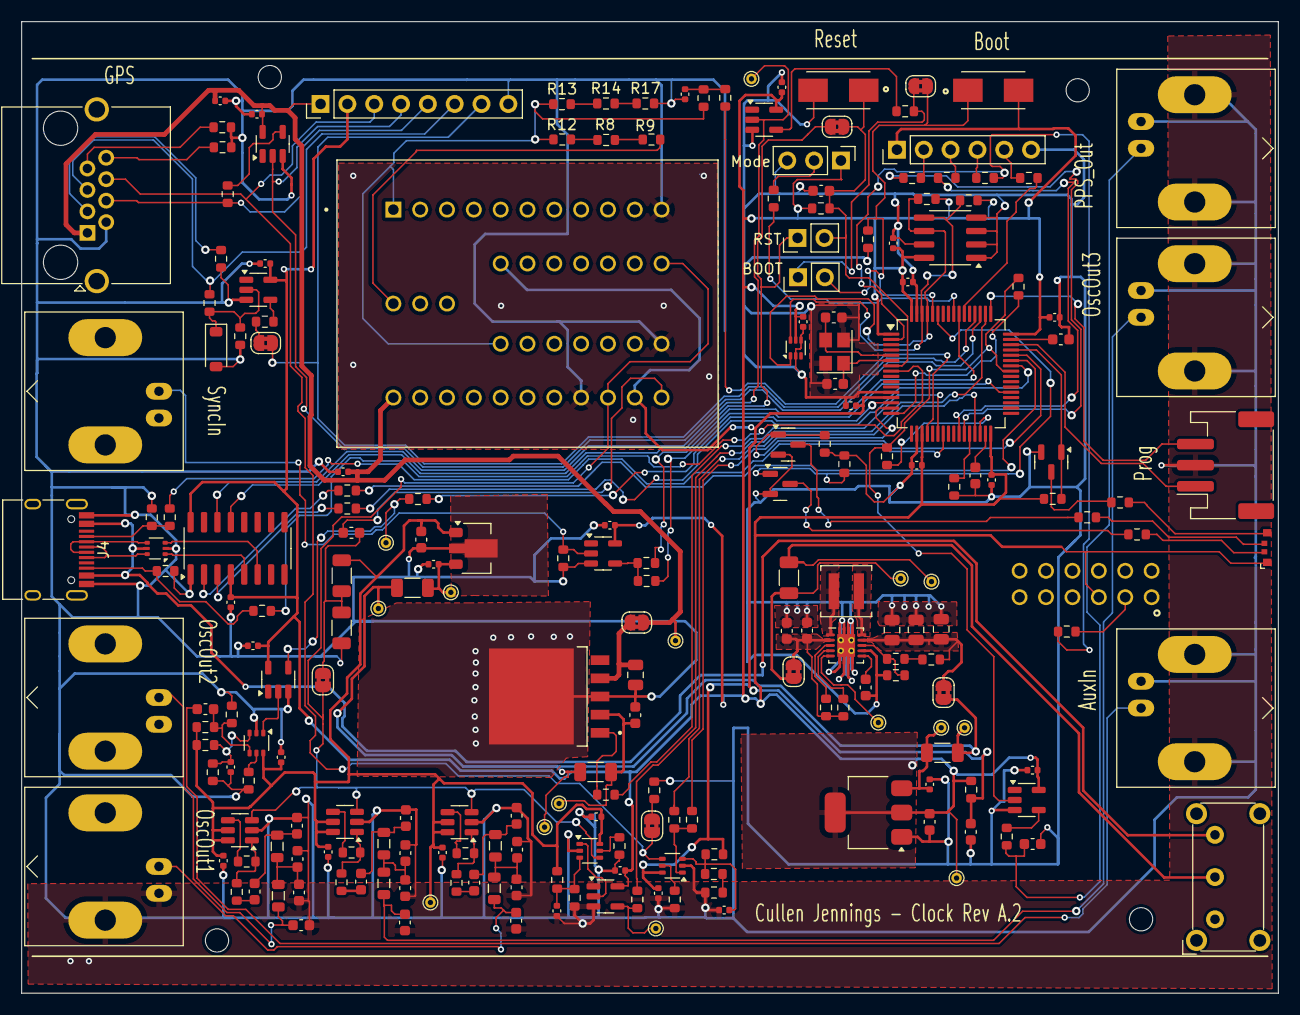
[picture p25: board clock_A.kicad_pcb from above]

Board: 2 copper layers, 119.0 x 92.0 mm, 225 parts (0 on the bottom side), 141 nets.

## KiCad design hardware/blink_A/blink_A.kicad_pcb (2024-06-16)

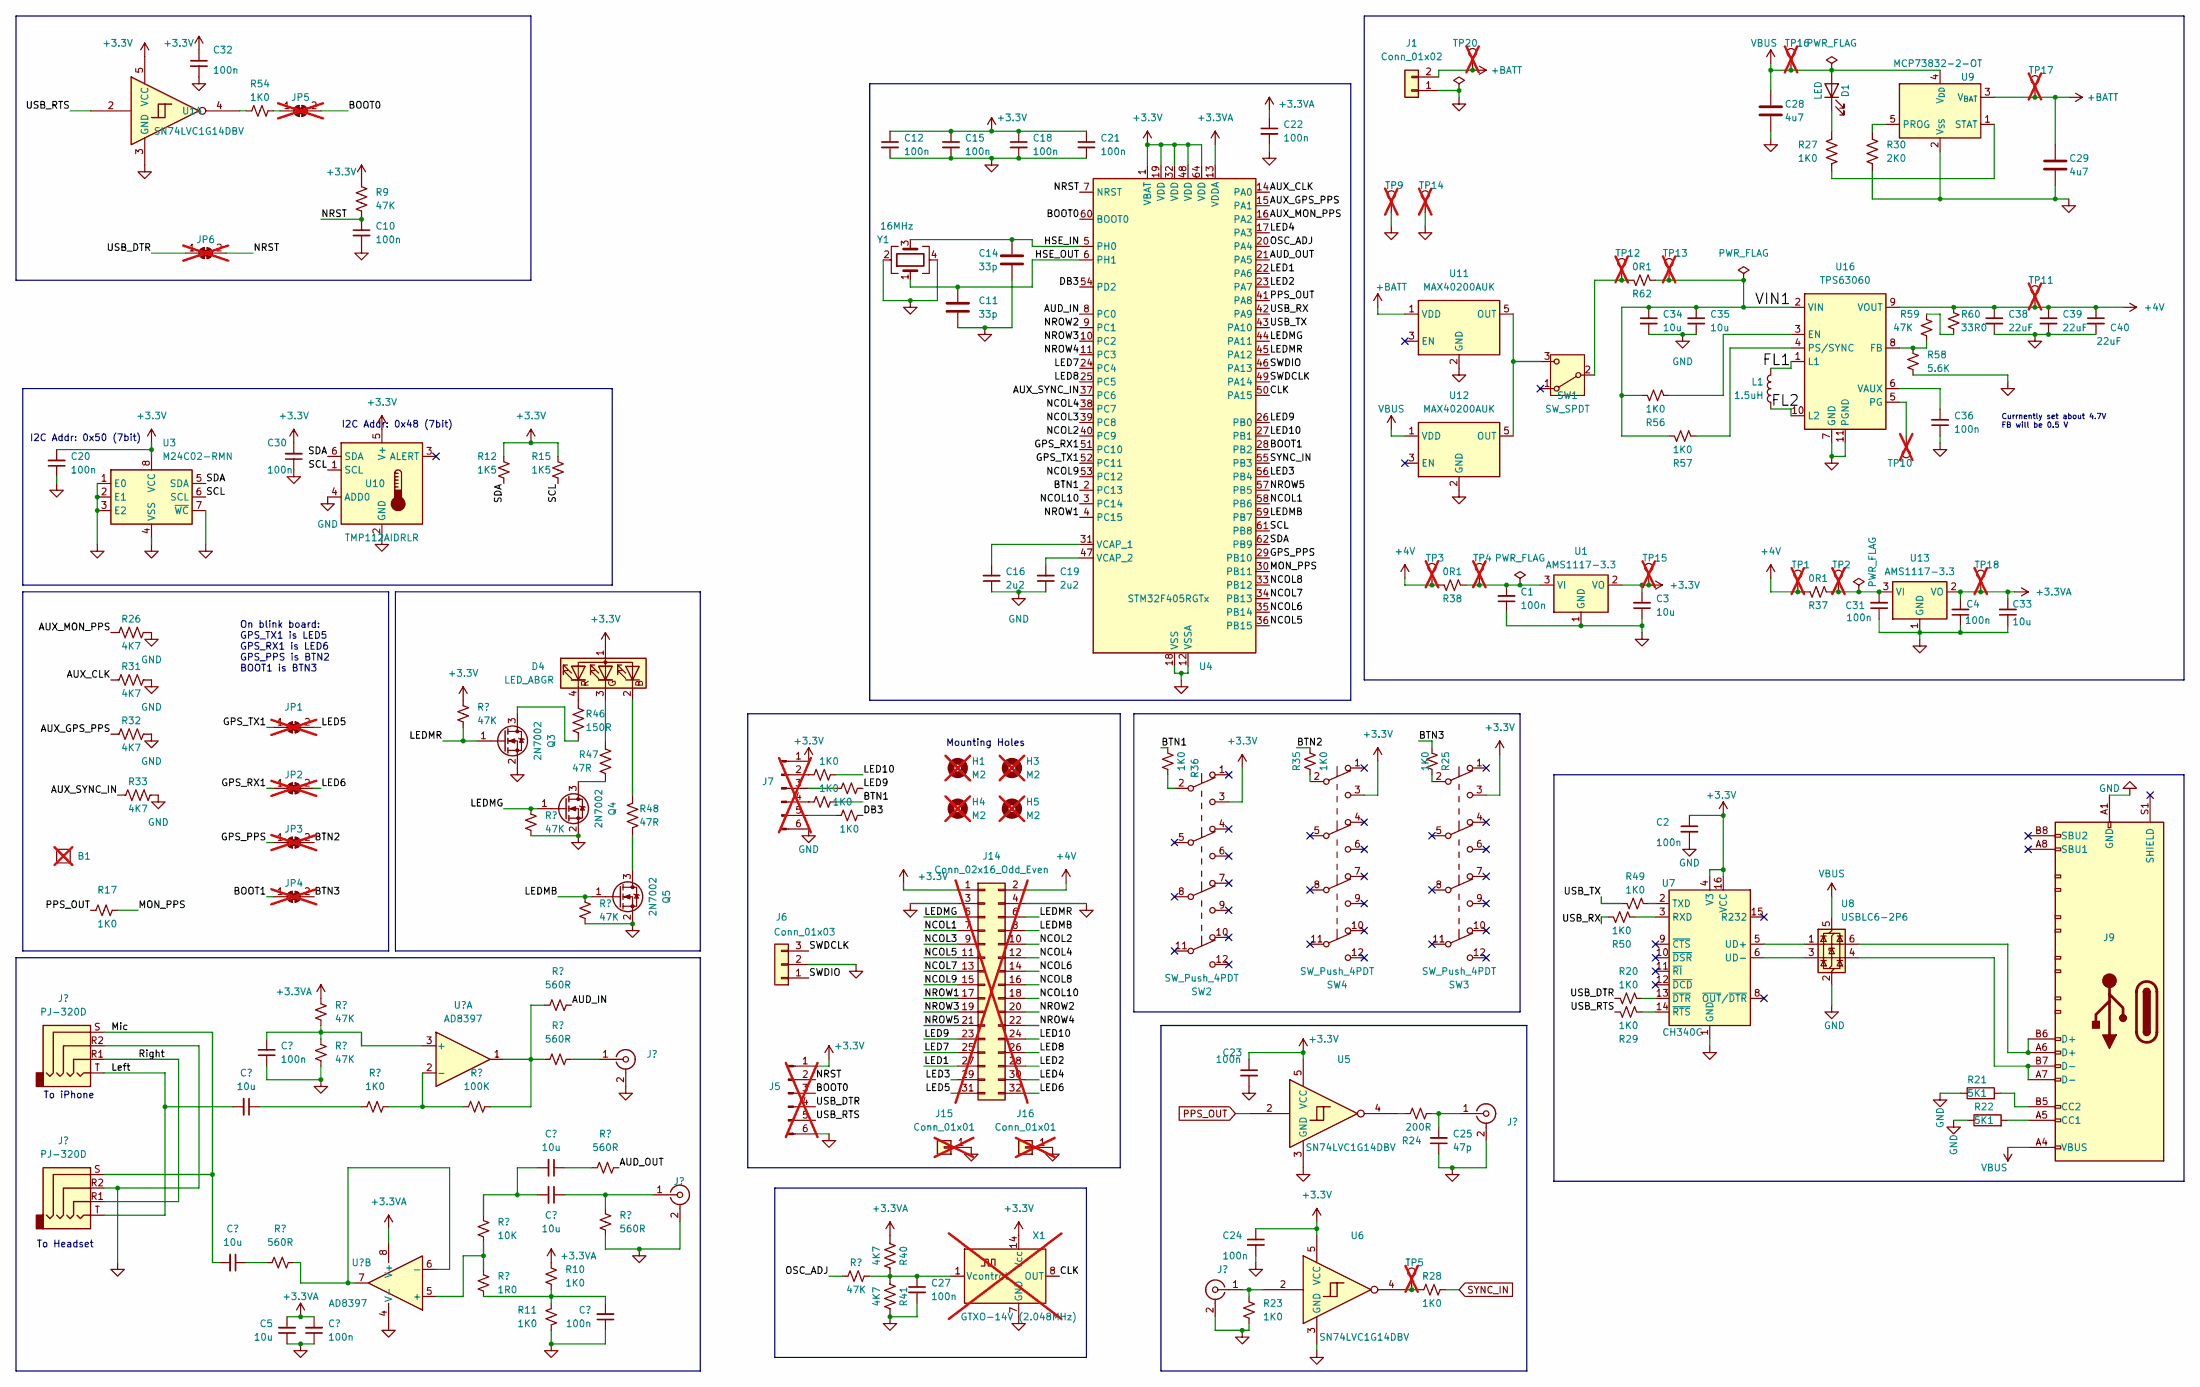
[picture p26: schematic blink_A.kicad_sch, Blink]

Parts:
B1: BatteryFlat1; not fitted
C1, C2, C12, C15, C18, C20, C21, C22, C23, C24, C30, C31, C32: 100n; C_0402_1005Metric; JLCPCB Part # C307331
C3, C5, C7, C8, C13, C26, C33: 10u; C_0603_1608Metric; JLCPCB Part # C19702
C4, C6, C9, C10, C17, C27, C36: 100n; C_0603_1608Metric; JLCPCB Part # C14663
C11, C14: 33p; C_0603_1608Metric; JLCPCB Part # C1663
C16, C19: 2u2; C_0603_1608Metric; JLCPCB Part # C23630
C25: 47p; C_0603_1608Metric; JLCPCB Part # C1671
C28, C29: 4u7; C_0603_1608Metric; JLCPCB Part # C19666
C34, C35: 10u; C_0603_1608Metric; JLCPCB Part # C96446
C38, C39, C40: 22uF; C_0805_2012Metric; JLCPCB Part # C45783
D1: LED; LED_0805_2012Metric; JLCPCB Part # C130114
D4: LED_ABGR; LED_RGB_MHS110FRGBCT; MPN MHS110FRGBCT; JLCPCB Part # C496820
H1, H3, H4, H5: M2; MountingHole_2.2mm_M2; not fitted
J1: Conn_01x02; JST_PH_S2B-PH-SM4-TB_1x02-1MP_P2.00mm_Horizontal; JLCPCB Part # C295747
J2, J3: PJ-320D; Jack_3.5mm_PJ320D_Horizontal-CJ; MPN PJ-320D; JLCPCB Part # C431535
J4, J11, J12, J13: KH-BNC50-3511; BNC_Amphenol_B6252HB-NPP3G-50_Horizontal-CJ; MPN KH-BNC50-3511; JLCPCB Part # C2837587
J5, J7: Conn_01x06_Pin; PinHeader_1x06_P2.54mm_Vertical; not fitted
J6: Conn_01x03; JST_PH_S3B-PH-SM4-TB_1x03-1MP_P2.00mm_Horizontal; JLCPCB Part # C265101
J9: USB_C_Receptacle; USB_C_Receptacle_HRO_TYPE-C-31-M-12; JLCPCB Part # C165948
J14: Conn_02x16_Odd_Even; PinHeader_2x16_P2.54mm_Vertical; not fitted
J15, J16: Conn_01x01; PinSocket_1x01_P2.54mm_Vertical; not fitted
JP1, JP2, JP3, JP4: SolderJumper_2_Bridged; SolderJumper-2_P1.3mm_Bridged_RoundedPad1.0x1.5mm; not fitted
JP5, JP6: SolderJumper_2_Bridged; SolderJumper-2_P1.3mm_Bridged2Bar_RoundedPad1.0x1.5mm; not fitted
L1: 1.5uH; L_Coilcraft_XAL4020-XXX; MPN XFL4020-152MEC; JLCPCB Part # C3033018
Q3, Q4, Q5: 2N7002; SOT-23; JLCPCB Part # C8545
R1, R2, R13, R16, R19: 560R; R_0603_1608Metric; JLCPCB Part # C23204
R3, R4, R9, R39, R51, R52, R53, R59: 47K; R_0603_1608Metric; JLCPCB Part # C25819
R5, R10, R11, R17, R20, R23, R25, R27, R28, R29, R35, R36, R42, R43, R44, R45, R49, R50, R54, R56, R57: 1K0; R_0603_1608Metric; JLCPCB Part # C21190
R6: 10K; R_0603_1608Metric; JLCPCB Part # C25804
R7: 1R0; R_0603_1608Metric; JLCPCB Part # C22936
R8: 100K; R_0603_1608Metric; JLCPCB Part # C25803
R12, R15: 1K5; R_0603_1608Metric; JLCPCB Part # C22843
R21, R22: 5K1; R_0603_1608Metric; JLCPCB Part # C23186
R24: 200R; R_0603_1608Metric; JLCPCB Part # C8218
R26, R31, R32, R33, R40, R41: 4K7; R_0603_1608Metric; JLCPCB Part # C23162
R30: 2K0; R_0603_1608Metric; JLCPCB Part # C22975
R37, R38, R62: 0R1; R_1206_3216Metric; JLCPCB Part # C25334
R46: 150R; R_0603_1608Metric; JLCPCB Part # C22808
R47, R48: 47R; R_0603_1608Metric; JLCPCB Part # C23182
R58: 5.6K; R_0603_1608Metric; JLCPCB Part # C23189
R60: 33R0; R_0603_1608Metric; JLCPCB Part # C23140
SW1: SW_SPDT; SW_E-Switch_EG1224_SPDT_Angled; JLCPCB Part # C273395
SW2, SW3, SW4: SW_Push_4PDT; PBH4UOANAGX; JLCPCB Part # C273424
TP1, TP2, TP3, TP4, TP12, TP13: TestPoint_THTPad_D1.0mm_Drill0.5mm; not fitted
TP5, TP9, TP10, TP11, TP14, TP15, TP16, TP17, TP18, TP20: TestPoint_THTPad_D1.5mm_Drill0.7mm; not fitted
U1, U13: AMS1117-3.3; SOT-223-3_TabPin2; JLCPCB Part # C6186
U2: AD8397; SOIC-8_3.9x4.9mm_P1.27mm; JLCPCB Part # C578714
U3: M24C02-RMN; SOIC-8_3.9x4.9mm_P1.27mm; JLCPCB Part # C83836
U4: STM32F405RGTx; LQFP-64_10x10mm_P0.5mm; JLCPCB Part # C15742
U5, U6, U14: SN74LVC1G14DBV; SOT-23-5; JLCPCB Part # C133145
U7: CH340C; SOIC-16_3.9x9.9mm_P1.27mm; JLCPCB Part # C7464026
U8: USBLC6-2P6; SOT-666; JLCPCB Rotation Offset 270
U9: MCP73832-2-OT; SOT-23-5; JLCPCB Part # C424093
U10: TMP112AIDRLR; SOT-563; JLCPCB Part # C28927
U11, U12: MAX40200AUK; SOT-23-5; JLCPCB Part # C2649430
U16: TPS63060; Texas_S-PWSON-N10_ThermalVias; JLCPCB Part # C48567
X1: GTXO-14V (2.048MHz); OSC_DIP-14; MPN ACVTX1018A-2.048MHZ-D10; not fitted
Y1: 16MHz; Crystal_SMD_3225-4Pin_3.2x2.5mm; JLCPCB Part # C13738

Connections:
+3.3V: C2.1, C3.2, C12.1, C15.1, C18.1, C20.2, C21.1, C23.1, C24.1, C30.2, C32.1, D4.1 (A), J5.1, J7.1, J14.1, R9.1, R12.1, R15.1, R51.2, SW2.3 (C), SW3.3 (C), SW4.3 (C), TP15.1, U1.2 (VO), U3.8 (VCC), U4.1 (VBAT), U4.19 (VDD), U4.32 (VDD), U4.48 (VDD), U4.64 (VDD), U5.5 (VCC), U6.5 (VCC), U7.4 (V3), U7.16 (VCC), U10.5 (V+), U14.5 (VCC), X1.14 (Vcc)
+3.3VA: C4.2, C5.2, C6.2, C22.1, C33.2, R3.2, R10.1, R40.1, TP18.1, U2.8 (V+), U4.13 (VDDA), U13.2 (VO)
+4V: C38.1, C39.1, C40.1, J14.2, R37.2, R38.2, R60.1, TP1.1, TP3.1, TP11.1, U16.9 (VOUT)
+BATT: C29.1, J1.2, TP17.1, TP20.1, U9.3 (V_{BAT}), U11.1 (VDD)
/AUD_IN: R1.1, U4.8 (PC0)
/AUD_OUT: R19.2, U4.21 (PA5)
/AUX_CLK: R31.1, U4.14 (PA0)
/AUX_GPS_PPS: R32.1, U4.15 (PA1)
/AUX_MON_PPS: R26.1, U4.16 (PA2)
/AUX_SYNC_IN: R33.1, U4.37 (PC6)
/BOOT0: J5.3, JP5.2 (B), U4.60 (BOOT0)
/BOOT1: JP4.1 (A), U4.28 (PB2)
/BTN1: R36.2, R44.1, U4.2 (PC13)
/BTN2: JP3.2 (B), R35.2
/BTN3: JP4.2 (B), R25.2
/CLK: U4.50 (PA15), X1.8 (OUT)
/DB3: R45.1, U4.54 (PD2)
/FL1: L1.1, U16.1 (L1)
/FL2: L1.2, U16.10 (L2)
/GPS_PPS: JP3.1 (A), U4.29 (PB10)
/GPS_RX1: JP2.1 (A), U4.51 (PC10)
/GPS_TX1: JP1.1 (A), U4.52 (PC11)
/HSE_IN: C14.1, U4.5 (PH0), Y1.3
/HSE_OUT: C11.1, U4.6 (PH1), Y1.1
/LED1: J14.27, U4.22 (PA6)
/LED2: J14.28, U4.23 (PA7)
/LED3: J14.29, U4.56 (PB4)
/LED4: J14.30, U4.17 (PA3)
/LED5: J14.31, JP1.2 (B)
/LED6: J14.32, JP2.2 (B)
/LED7: J14.25, U4.24 (PC4)
/LED8: J14.26, U4.25 (PC5)
/LED9: J14.23, R43.1, U4.26 (PB0)
/LED10: J14.24, R42.1, U4.27 (PB1)
/LEDMB: J14.8, Q5.1 (G), R53.2, U4.59 (PB7)
/LEDMG: J14.5, Q4.1 (G), R52.2, U4.44 (PA11)
/LEDMR: J14.6, Q3.1 (G), R51.1, U4.45 (PA12)
/Left: C8.2, J2.T, J3.T
/MON_PPS: R17.2, U4.30 (PB11)
/Mic: C7.2, J2.S, J3.S
/NCOL1: J14.7, U4.58 (PB6)
/NCOL2: J14.10, U4.40 (PC9)
/NCOL3: J14.9, U4.39 (PC8)
/NCOL4: J14.12, U4.38 (PC7)
/NCOL5: J14.11, U4.36 (PB15)
/NCOL6: J14.14, U4.35 (PB14)
/NCOL7: J14.13, U4.34 (PB13)
/NCOL8: J14.16, U4.33 (PB12)
/NCOL9: J14.15, U4.53 (PC12)
/NCOL10: J14.18, U4.3 (PC14)
/NROW1: J14.17, U4.4 (PC15)
/NROW2: J14.20, U4.9 (PC1)
/NROW3: J14.19, U4.10 (PC2)
/NROW4: J14.22, U4.11 (PC3)
/NROW5: J14.21, U4.57 (PB5)
/NRST: C10.1, J5.2, JP6.2 (B), R9.2, U4.7 (NRST)
/OSC_ADJ: R39.2, U4.20 (PA4)
/Right: J2.R1, J3.R1
/SCL: R15.2, U3.6 (SCL), U4.61 (PB8), U10.1 (SCL)
/SDA: R12.2, U3.5 (SDA), U4.62 (PB9), U10.6 (SDA)
/SWDCLK: J6.3, U4.49 (PA14)
/SWDIO: J6.1, U4.46 (PA13)
/USB_DTR: J5.4, JP6.1 (A), R20.2
/USB_RTS: J5.5, R29.1, U14.2
/USB_RX: R50.1, U4.42 (PA9)
/USB_TX: R49.2, U4.43 (PA10)
/VIN1: C34.1, C35.1, R56.1, R57.1, R62.1, TP13.1, U16.2 (VIN)
GND: C1.1, C2.2, C3.1, C4.1, C5.1, C6.1, C9.1, C10.2, C11.2, C12.2, C14.2, C15.2, C16.1, C17.1, C18.2, C19.1, C20.1, C21.2, C22.2, C23.2, C24.2, C25.1, C27.2, C28.2, C29.2, C30.1, C31.1, C32.2, C33.1, C34.2, C35.2, C36.1, C38.2, C39.2, C40.2, J1.1, J2.R2, J3.R2, J4.2 (Ext), J5.6, J6.2, J7.6, J9.A1 (GND), J9.A12 (GND), J9.B1 (GND), J9.B12 (GND), J11.2 (Ext), J12.2 (Ext), J13.2 (Ext), J14.3, J14.4, J15.1, J16.1, Q3.2 (S), Q4.2 (S), Q5.2 (S), R4.1, R11.2, R13.2, R21.1, R22.1, R23.2, R26.2, R30.2, R31.2, R32.2, R33.2, R41.2, R52.1, R53.1, R58.2, TP9.1, TP14.1, U1.1 (GND), U2.4 (V-), U3.1 (E0), U3.2 (E1), U3.3 (E2), U3.4 (VSS), U3.7 (~WC)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
unnamed: C7.1, R2.1
unnamed: C8.1, R5.2
unnamed: C13.2, C26.2, R6.1
unnamed: C17.2, R7.2, R10.2, R11.1
unnamed: C26.1, R19.1
unnamed: D1.1 (K), R27.1
unnamed: D4.2 (BK), R48.1
unnamed: D4.3 (GK), R47.2
unnamed: D4.4 (RK), R46.2
unnamed: C25.2, J4.1 (In), R24.2
unnamed: J7.2, R42.2
unnamed: J7.3, R43.2
unnamed: J7.4, R44.2
unnamed: J7.5, R45.2
unnamed: J9.A5 (CC1), R22.2
unnamed: J9.B5 (CC2), R21.2
unnamed: J9.A6 (D+), J9.B6 (D+), U8.6 (I/O1)
unnamed: J9.A7 (D-), J9.B7 (D-), U8.4 (I/O2)
unnamed: C13.1, J11.1 (In), R13.1
unnamed: J12.1 (In), R23.1, U6.2
unnamed: J13.1 (In), R16.1
unnamed: JP5.1 (A), R54.2
unnamed: Q3.3 (D), R46.1
unnamed: Q4.3 (D), R47.1
unnamed: Q5.3 (D), R48.2
unnamed: R1.2, R8.1, R16.2, U2.1
unnamed: R24.1, U5.4
unnamed: R25.1, SW3.2 (B)
unnamed: R28.2, TP5.1, U6.4
unnamed: R35.1, SW4.2 (B)
unnamed: R36.1, SW2.2 (B)
unnamed: R54.1, U14.4
unnamed: R59.1, R60.2
unnamed: R62.2, SW1.2 (B), TP12.1
unnamed: SW1.3 (C), U11.5 (OUT), U12.5 (OUT)
unnamed: C1.2, R38.1, TP4.1, U1.3 (VI)
unnamed: C9.2, R3.1, R4.2, U2.3 (+)
unnamed: R5.1, R8.2, U2.2 (-)
unnamed: R6.2, R7.1, U2.5 (+)
unnamed: R2.2, U2.6 (-), U2.7
unnamed: C16.2, U4.31 (VCAP_1)
unnamed: C19.2, U4.47 (VCAP_2)
unnamed: R50.2, U7.3 (RXD)
unnamed: R49.1, U7.2 (TXD)
unnamed: U7.5 (UD+), U8.1 (I/O1)
unnamed: U7.6 (UD-), U8.3 (I/O2)
unnamed: R20.1, U7.13 (~DTR)
unnamed: R29.2, U7.14 (~RTS)
unnamed: R30.1, U9.5 (PROG)
unnamed: R27.2, U9.1 (STAT)
unnamed: C31.2, R37.1, TP2.1, U13.3 (VI)
unnamed: R56.2, U16.3 (EN)
unnamed: R58.1, R59.2, U16.8 (FB)
unnamed: TP10.1, U16.5 (PG)
unnamed: R57.2, U16.4 (PS/SYNC)
unnamed: C36.2, U16.6 (VAUX)
unnamed: C27.1, R39.1, R40.2, R41.1, X1.1 (Vcontrol)
PPS_OUT: R17.1, U4.41 (PA8), U5.2
SYNC_IN: R28.1, U4.55 (PB3)
VBUS: C28.1, D1.2 (A), J9.A4 (VBUS), J9.A9 (VBUS), J9.B4 (VBUS), J9.B9 (VBUS), TP16.1, U8.5 (VBUS), U9.4 (V_{DD}), U12.1 (VDD)

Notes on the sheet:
I2C Addr: 0x48 (7bit)
Currnently set about 4.7V FB will be 0.5 V
To iPhone
To Headset
I2C Addr: 0x50 (7bit)
Mounting Holes
On blink board: GPS_TX1 is LED5 GPS_RX1 is LED6 GPS_PPS is BTN2 BOOT1 is BTN3

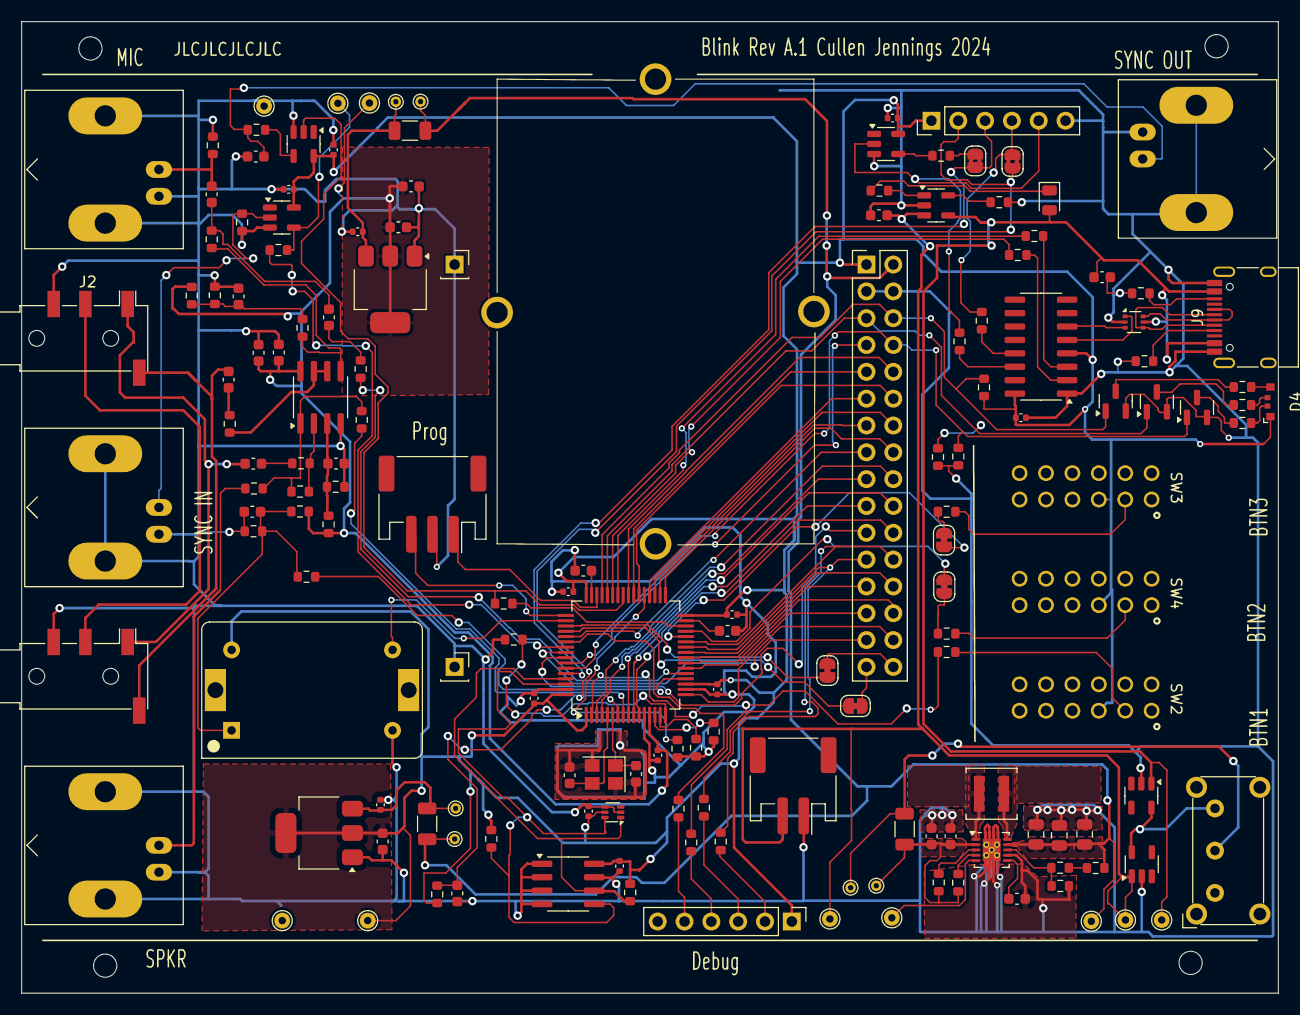
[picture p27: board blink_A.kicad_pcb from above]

Board: 2 copper layers, 119.0 x 92.0 mm, 164 parts (0 on the bottom side), 128 nets.

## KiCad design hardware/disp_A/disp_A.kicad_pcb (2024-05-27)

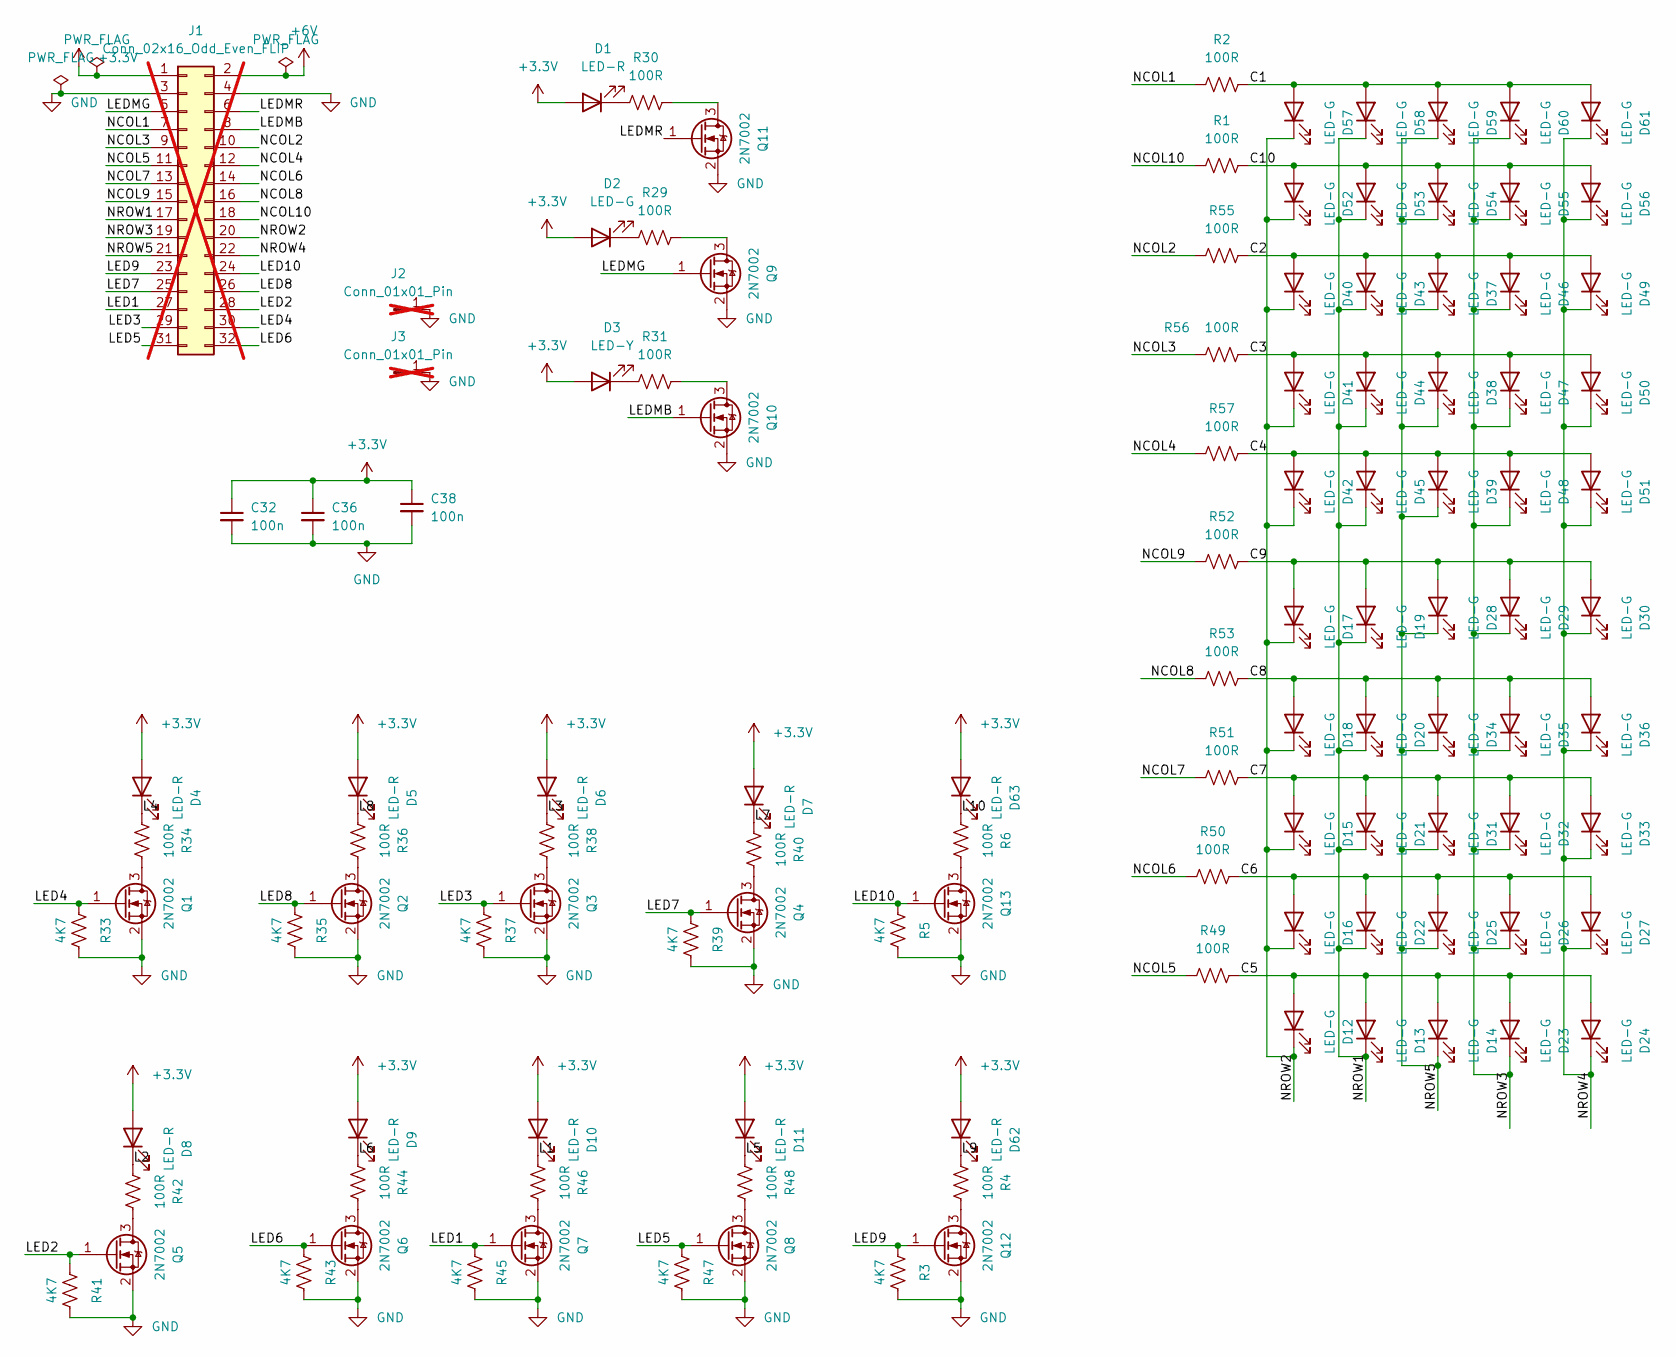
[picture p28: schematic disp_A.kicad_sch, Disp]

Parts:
C32, C36, C38: 100n; C_0402_1005Metric; JLCPCB Part # C307331
D1, D4, D5, D6, D7, D8, D9, D10, D11, D62, D63: LED-R; LED_0603_1608Metric; JLCPCB Part # C94869
D2, D12, D13, D14, D15, D16, D17, D18, D19, D20, D21, D22, D23, D24, D25, D26, D27, D28, D29, D30, D31, D32, D33, D34, D35, D36, D37, D38, D39, D40, D41, D42, D43, D44, D45, D46, D47, D48, D49, D50, D51, D52, D53, D54, D55, D56, D57, D58, D59, D60, D61: LED-G; LED_0603_1608Metric; JLCPCB Part # C125093
D3: LED-Y; LED_0603_1608Metric; JLCPCB Part # C72038
J1: Conn_02x16_Odd_Even_FLIP; PinHeader_2x16_P2.54mm_Vertical; not fitted
J2, J3: Conn_01x01_Pin; PinHeader_1x01_P2.54mm_Vertical; not fitted
Q1, Q2, Q3, Q4, Q5, Q6, Q7, Q8, Q9, Q10, Q11, Q12, Q13: 2N7002; SOT-23; JLCPCB Part # C8545
R1, R2, R4, R6, R29, R30, R31, R34, R36, R38, R40, R42, R44, R46, R48, R49, R50, R51, R52, R53, R55, R56, R57: 100R; R_0603_1608Metric; JLCPCB Part # C22775
R3, R5, R33, R35, R37, R39, R41, R43, R45, R47: 4K7; R_0603_1608Metric; JLCPCB Part # C23162

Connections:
+3.3V: C32.1, C36.1, C38.1, D1.2 (A), D2.2 (A), D3.2 (A), D4.2 (A), D5.2 (A), D6.2 (A), D7.2 (A), D8.2 (A), D9.2 (A), D10.2 (A), D11.2 (A), D62.2 (A), D63.2 (A), J1.1
+6V: J1.2
/C1: D57.2 (A), D58.2 (A), D59.2 (A), D60.2 (A), D61.2 (A), R2.1
/C2: D37.2 (A), D40.2 (A), D43.2 (A), D46.2 (A), D49.2 (A), R55.1
/C3: D38.2 (A), D41.2 (A), D44.2 (A), D47.2 (A), D50.2 (A), R56.1
/C4: D39.2 (A), D42.2 (A), D45.2 (A), D48.2 (A), D51.2 (A), R57.1
/C5: D12.2 (A), D13.2 (A), D14.2 (A), D23.2 (A), D24.2 (A), R49.1
/C6: D16.2 (A), D22.2 (A), D25.2 (A), D26.2 (A), D27.2 (A), R50.1
/C7: D15.2 (A), D21.2 (A), D31.2 (A), D32.2 (A), D33.2 (A), R51.1
/C8: D18.2 (A), D20.2 (A), D34.2 (A), D35.2 (A), D36.2 (A), R53.1
/C9: D17.2 (A), D19.2 (A), D28.2 (A), D29.2 (A), D30.2 (A), R52.1
/C10: D52.2 (A), D53.2 (A), D54.2 (A), D55.2 (A), D56.2 (A), R1.1
/L1: D10.1 (K), R46.1
/L2: D8.1 (K), R42.1
/L3: D6.1 (K), R38.1
/L4: D4.1 (K), R34.1
/L5: D11.1 (K), R48.1
/L6: D9.1 (K), R44.1
/L7: D7.1 (K), R40.1
/L8: D5.1 (K), R36.1
/L9: D62.1 (K), R4.1
/L10: D63.1 (K), R6.1
/LED1: J1.27, Q7.1 (G), R45.2
/LED2: J1.28, Q5.1 (G), R41.2
/LED3: J1.29, Q3.1 (G), R37.2
/LED4: J1.30, Q1.1 (G), R33.2
/LED5: J1.31, Q8.1 (G), R47.2
/LED6: J1.32, Q6.1 (G), R43.2
/LED7: J1.25, Q4.1 (G), R39.2
/LED8: J1.26, Q2.1 (G), R35.2
/LED9: J1.23, Q12.1 (G), R3.2
/LED10: J1.24, Q13.1 (G), R5.2
/LEDMB: J1.8, Q10.1 (G)
/LEDMG: J1.5, Q9.1 (G)
/LEDMR: J1.6, Q11.1 (G)
/NCOL1: J1.7, R2.2
/NCOL2: J1.10, R55.2
/NCOL3: J1.9, R56.2
/NCOL4: J1.12, R57.2
/NCOL5: J1.11, R49.2
/NCOL6: J1.14, R50.2
/NCOL7: J1.13, R51.2
/NCOL8: J1.16, R53.2
/NCOL9: J1.15, R52.2
/NCOL10: J1.18, R1.2
/NROW1: D13.1 (K), D19.1 (K), D20.1 (K), D21.1 (K), D22.1 (K), D43.1 (K), D44.1 (K), D45.1 (K), D53.1 (K), D58.1 (K), J1.17
/NROW2: D12.1 (K), D15.1 (K), D16.1 (K), D17.1 (K), D18.1 (K), D40.1 (K), D41.1 (K), D42.1 (K), D52.1 (K), D57.1 (K), J1.20
/NROW3: D23.1 (K), D26.1 (K), D29.1 (K), D32.1 (K), D35.1 (K), D46.1 (K), D47.1 (K), D48.1 (K), D55.1 (K), D60.1 (K), J1.19
/NROW4: D24.1 (K), D27.1 (K), D30.1 (K), D33.1 (K), D36.1 (K), D49.1 (K), D50.1 (K), D51.1 (K), D56.1 (K), D61.1 (K), J1.22
/NROW5: D14.1 (K), D25.1 (K), D28.1 (K), D31.1 (K), D34.1 (K), D37.1 (K), D38.1 (K), D39.1 (K), D54.1 (K), D59.1 (K), J1.21
GND: C32.2, C36.2, C38.2, J1.3, J1.4, J2.1, J3.1, Q1.2 (S), Q2.2 (S), Q3.2 (S), Q4.2 (S), Q5.2 (S), Q6.2 (S), Q7.2 (S), Q8.2 (S), Q9.2 (S), Q10.2 (S), Q11.2 (S), Q12.2 (S), Q13.2 (S), R3.1, R5.1, R33.1, R35.1, R37.1, R39.1, R41.1, R43.1, R45.1, R47.1
unnamed: D1.1 (K), R30.1
unnamed: D2.1 (K), R29.1
unnamed: D3.1 (K), R31.1
unnamed: Q1.3 (D), R34.2
unnamed: Q2.3 (D), R36.2
unnamed: Q3.3 (D), R38.2
unnamed: Q4.3 (D), R40.2
unnamed: Q5.3 (D), R42.2
unnamed: Q6.3 (D), R44.2
unnamed: Q7.3 (D), R46.2
unnamed: Q8.3 (D), R48.2
unnamed: Q9.3 (D), R29.2
unnamed: Q10.3 (D), R31.2
unnamed: Q11.3 (D), R30.2
unnamed: Q12.3 (D), R4.2
unnamed: Q13.3 (D), R6.2

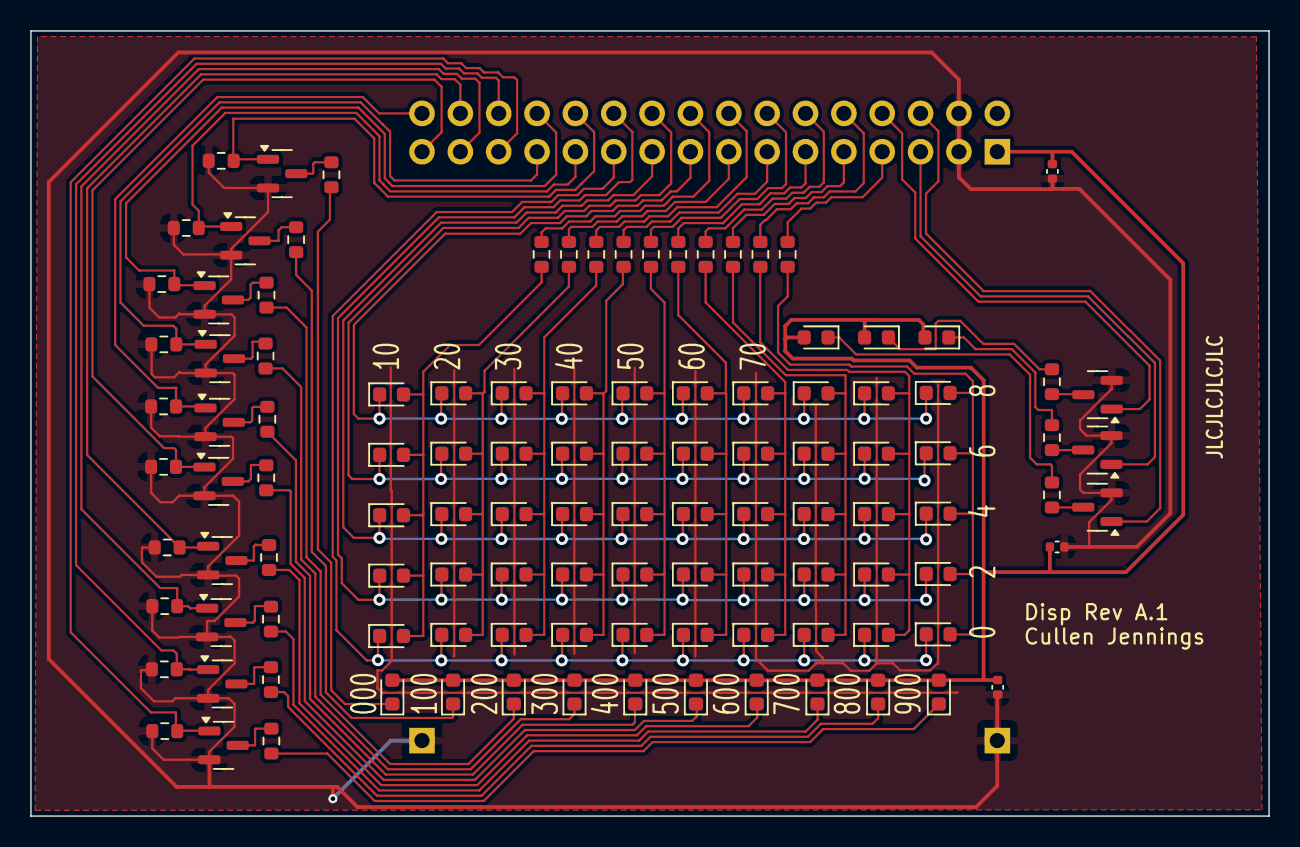
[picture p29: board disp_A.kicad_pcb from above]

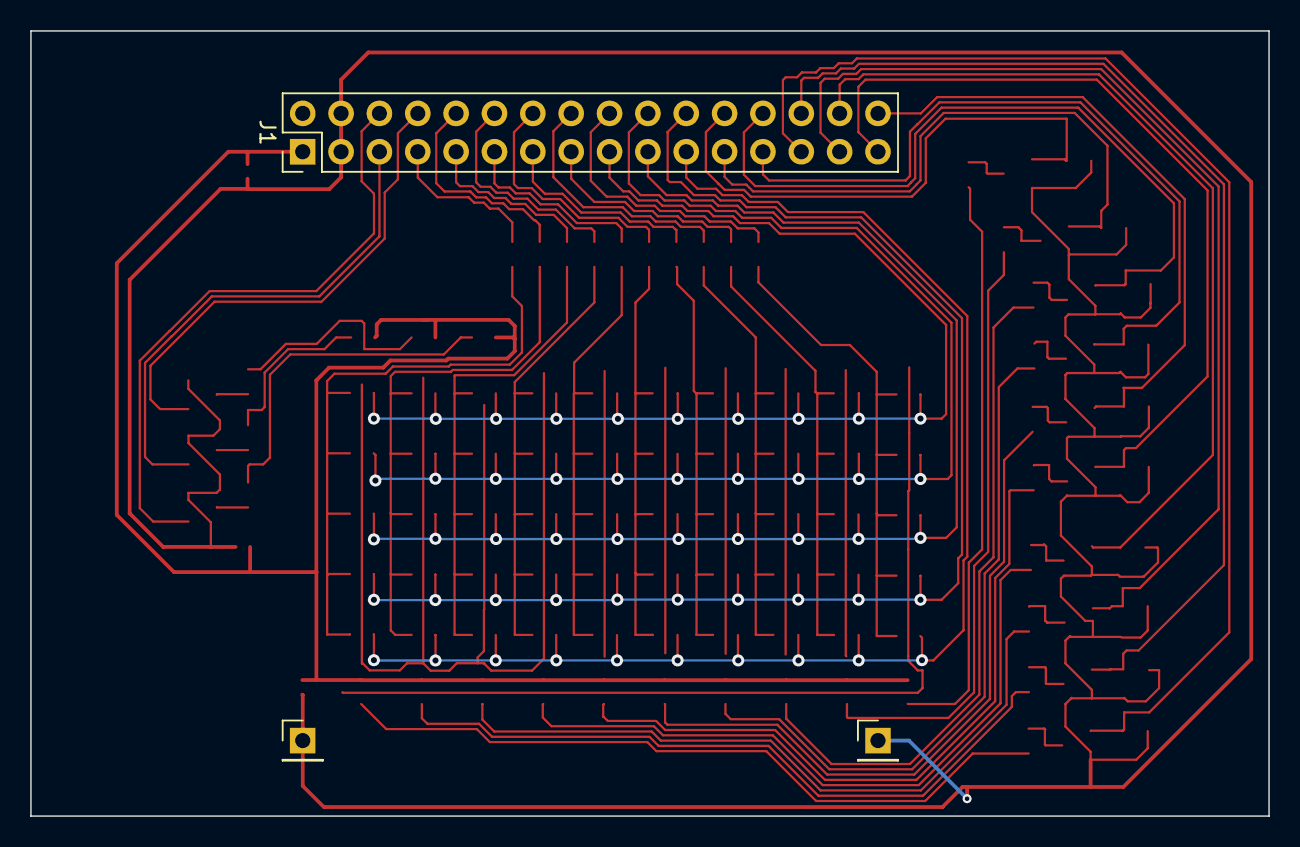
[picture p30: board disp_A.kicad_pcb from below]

Board: 2 copper layers, 82.0 x 52.0 mm, 115 parts (3 on the bottom side), 66 nets.

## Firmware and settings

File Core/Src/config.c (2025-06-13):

// SPDX-FileCopyrightText: Copyright (c) 2023 Cullen Jennings
// SPDX-License-Identifier: BSD-2-Clause

#include "config.h"

#include <stdio.h>
#include <string.h>

#include "hardware.h"
#include "main.h"
#include "setting.h"

Config config;

void configInit() {
  setting.capture2uSRatioM = 125;
  setting.capture2uSRatioN = 256;
}

void configSetup() {
  // access EEProm
  if (1) {
    char buffer[100];
    const uint16_t i2cAddr = 0x50;
    uint32_t timeout = 256;
    uint8_t eepromMemAddr = 0;
    HAL_StatusTypeDef status;

    status = HAL_I2C_IsDeviceReady(&hI2c, i2cAddr << 1, 2, timeout);
    if (status != HAL_OK) {
      snprintf(buffer, sizeof(buffer), "Error: EEProm not found \r\n");
      HAL_UART_Transmit(&hUartDebug, (uint8_t *)buffer, strlen(buffer), 1000);
    }

#ifdef FORMAT_EEPROM
    const int writeConfigEEProm = 1;
#else
    // TODO move to seperate program
    const int writeConfigEEProm = 0;
#endif
    if (writeConfigEEProm) {
      snprintf(buffer, sizeof(buffer),
               "\r\n\r\nPROGRAMMING EEProm CONFIG ONLY \r\n");
      HAL_UART_Transmit(&hUartDebug, (uint8_t *)buffer, strlen(buffer), 1000);

      // write config to EEProm
      config.version = 2;  // config file version

      config.product = 1;  // 1=blink, 2=clock, 3=gps
      config.revMajor = 1; // 1 is Rev A
      config.revMinor = 1;

      config.serialNum = 34;  // next serial is 34

      config.usePPS = 0;
      config.future13 = 0;
      config.future14 = 0;
      config.future15 = 0;

      // external osc type ( 0=none, 2= 2.048 MHz, 10=10 MHz)
      config.extOscType = 0;
      config.oscAdj = -535;  // TODO - this value seems very high , is this a
                             // bug with the 10.5 vs 10

      config.vcoValue = 625;
      // For 10Mhz osc, slope is period goes down 1 ns per about 100 VCO goes up

      status = HAL_I2C_Mem_Write(&hI2c, i2cAddr << 1, eepromMemAddr,
                                 sizeof(eepromMemAddr), (uint8_t *)&config,
                                 (uint16_t)sizeof(config), timeout);
      if (status != HAL_OK) {
        // stat: 0=0k, 1 is HAL_ERROR, 2=busy , 3 = timeout
        snprintf(buffer, sizeof(buffer),
                 "EEProm Write Error:  data hal error %d \r\n", status);
        HAL_UART_Transmit(&hUartDebug, (uint8_t *)buffer, strlen(buffer), 1000);
      }

      // chip has 1.5 ms max page write time when it will not respond
      HAL_Delay(2 /*ms */);
      HAL_Delay(20 /*ms */);
    }

    status = HAL_I2C_Mem_Read(&hI2c, i2cAddr << 1, eepromMemAddr,
                              sizeof(eepromMemAddr), (uint8_t *)&config,
                              (uint16_t)sizeof(config), timeout);
    if (status != HAL_OK) {
      // stat: 0=0k, 1 is HAL_ERROR, 2=busy , 3 = timeout
      snprintf(buffer, sizeof(buffer),
               "EEProm Read Error:  data hal error %d \r\n", status);
      HAL_UART_Transmit(&hUartDebug, (uint8_t *)buffer, strlen(buffer), 1000);
    }

    if ((config.version < 1) || (config.version > 10)) {
      snprintf(buffer, sizeof(buffer), "EEProm not initalized: %d \r\n",
               config.version);
      HAL_UART_Transmit(&hUartDebug, (uint8_t *)buffer, strlen(buffer), 1000);

      Error_Handler();
    }

    if (config.version == 1) {
      // if it is an old config data, fill in the missing data
      config.usePPS = 0;
      config.future13 = 0;
      config.future14 = 0;
      config.future15 = 0;
    }

    snprintf(buffer, sizeof(buffer), "  Hardware version: " );
    if (config.revMajor == 0) {
      snprintf(buffer, sizeof(buffer), "EV%d\r\n",
               config.revMinor);
    }
    else  {
      snprintf(buffer, sizeof(buffer), "Rev:%c.%d\r\n",
               (char) 'A' + config.revMajor -1,
               config.revMinor);
    }

    if (((config.revMajor == 0) && (config.revMinor >= 10) &&
        (config.revMinor <= 12)) ||
        ((config.revMajor == 1 /*A*/ ) && (config.revMinor >= 1) &&
         (config.revMinor <= 2)))
      {
      HAL_UART_Transmit(&hUartDebug, (uint8_t *)buffer, strlen(buffer), 1000);

      setClk(config.extOscType, config.vcoValue,
             config.oscAdj);  // TODO - setup power first

      if (config.product == 1) {
        // This is blink board

        // reconfigure ext_clk to be input buton 2
        GPIO_InitTypeDef GPIO_InitStruct = {0};
        GPIO_InitStruct.Pin = AUX_CLK_Pin;
        GPIO_InitStruct.Mode = GPIO_MODE_INPUT;
        GPIO_InitStruct.Pull = GPIO_PULLDOWN;
        HAL_GPIO_Init(AUX_CLK_GPIO_Port, &GPIO_InitStruct);
      }

      if (config.product == 2) {  // TODO - move this code to setting.c
        // This is clock board

        // turn off options
        setting.blinkHaveDisplay = 0;

        // turn off audio and display
        setting.blinkMute = 1;
        setting.blinkBlank = 1;
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

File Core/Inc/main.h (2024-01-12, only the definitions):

#define BTN1_Pin GPIO_PIN_13
#define BTN1_GPIO_Port GPIOC
#define NCOL10_Pin GPIO_PIN_14
#define NCOL10_GPIO_Port GPIOC
#define NROW1_Pin GPIO_PIN_15
#define NROW1_GPIO_Port GPIOC
#define HSE_IN_Pin GPIO_PIN_0
#define HSE_IN_GPIO_Port GPIOH
#define HSE_OUT_Pin GPIO_PIN_1
#define HSE_OUT_GPIO_Port GPIOH
#define AUD_IN_Pin GPIO_PIN_0
#define AUD_IN_GPIO_Port GPIOC
#define NROW2_Pin GPIO_PIN_1
#define NROW2_GPIO_Port GPIOC
#define NROW3_Pin GPIO_PIN_2
#define NROW3_GPIO_Port GPIOC
#define NROW4_Pin GPIO_PIN_3
#define NROW4_GPIO_Port GPIOC
#define AUX_CLK_Pin GPIO_PIN_0
#define AUX_CLK_GPIO_Port GPIOA
#define AUX_GPS_PPS_Pin GPIO_PIN_1
#define AUX_GPS_PPS_GPIO_Port GPIOA
#define AUX_SYNC_MON_Pin GPIO_PIN_2
#define AUX_SYNC_MON_GPIO_Port GPIOA
#define LED4_Pin GPIO_PIN_3
#define LED4_GPIO_Port GPIOA
#define OSC_ADJ_Pin GPIO_PIN_4
#define OSC_ADJ_GPIO_Port GPIOA
#define AUD_OUT_Pin GPIO_PIN_5
#define AUD_OUT_GPIO_Port GPIOA
#define LED1_Pin GPIO_PIN_6
#define LED1_GPIO_Port GPIOA
#define LED2_Pin GPIO_PIN_7
#define LED2_GPIO_Port GPIOA
#define LED7_Pin GPIO_PIN_4
#define LED7_GPIO_Port GPIOC
#define LED8_Pin GPIO_PIN_5
#define LED8_GPIO_Port GPIOC
#define LED9_Pin GPIO_PIN_0
#define LED9_GPIO_Port GPIOB
#define LED10_Pin GPIO_PIN_1
#define LED10_GPIO_Port GPIOB
#define BOOT1_Pin GPIO_PIN_2
#define BOOT1_GPIO_Port GPIOB
#define GPS_PPS_Pin GPIO_PIN_10
#define GPS_PPS_GPIO_Port GPIOB
#define SYNC_MON_Pin GPIO_PIN_11
#define SYNC_MON_GPIO_Port GPIOB
#define NCOL8_Pin GPIO_PIN_12
#define NCOL8_GPIO_Port GPIOB
#define NCOL7_Pin GPIO_PIN_13
#define NCOL7_GPIO_Port GPIOB
#define NCOL6_Pin GPIO_PIN_14
#define NCOL6_GPIO_Port GPIOB
#define NCOL5_Pin GPIO_PIN_15
#define NCOL5_GPIO_Port GPIOB
#define AUX_SYNC_IN_Pin GPIO_PIN_6
#define AUX_SYNC_IN_GPIO_Port GPIOC
#define NCOL4_Pin GPIO_PIN_7
#define NCOL4_GPIO_Port GPIOC
#define NCOL3_Pin GPIO_PIN_8
#define NCOL3_GPIO_Port GPIOC
#define NCOL2_Pin GPIO_PIN_9
#define NCOL2_GPIO_Port GPIOC
#define SYNC_OUT_Pin GPIO_PIN_8
#define SYNC_OUT_GPIO_Port GPIOA
#define USB_RX_Pin GPIO_PIN_9
#define USB_RX_GPIO_Port GPIOA
#define USB_TX_Pin GPIO_PIN_10
#define USB_TX_GPIO_Port GPIOA
#define LEDMG_Pin GPIO_PIN_11
#define LEDMG_GPIO_Port GPIOA
#define LEDMR_Pin GPIO_PIN_12
#define LEDMR_GPIO_Port GPIOA
#define SWDIO_Pin GPIO_PIN_13
#define SWDIO_GPIO_Port GPIOA
#define SWDCLK_Pin GPIO_PIN_14
#define SWDCLK_GPIO_Port GPIOA
#define CLK_Pin GPIO_PIN_15
#define CLK_GPIO_Port GPIOA
#define GPS_RX1_Pin GPIO_PIN_10
#define GPS_RX1_GPIO_Port GPIOC
#define GPS_TX1_Pin GPIO_PIN_11
#define GPS_TX1_GPIO_Port GPIOC
#define NCOL9_Pin GPIO_PIN_12
#define NCOL9_GPIO_Port GPIOC
#define DB3_Pin GPIO_PIN_2
#define DB3_GPIO_Port GPIOD
#define SYNC_IN_Pin GPIO_PIN_3
#define SYNC_IN_GPIO_Port GPIOB
#define LED3_Pin GPIO_PIN_4
#define LED3_GPIO_Port GPIOB
#define NROW5_Pin GPIO_PIN_5
#define NROW5_GPIO_Port GPIOB
#define NCOL1_Pin GPIO_PIN_6
#define NCOL1_GPIO_Port GPIOB
#define LEDMB_Pin GPIO_PIN_7
#define LEDMB_GPIO_Port GPIOB
#define SCL_Pin GPIO_PIN_8
#define SCL_GPIO_Port GPIOB
#define SDA_Pin GPIO_PIN_9
#define SDA_GPIO_Port GPIOB

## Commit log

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2023-06-11 update to starting adding clock stuff
    [AOCJY4A-10.000MHZ-SW.step, blinky_v3.kicad_pcb, blinky_v3.kicad_sch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]
2023-06-11 start to add sin wave output
    [U.FL-R-SMT-1.step, blinky_v3.kicad_pcb, blinky_v3.kicad_sch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]
2023-06-11 add converter to cmos square wave
    [blinky_v3.kicad_pcb, blinky_v3.kicad_sch]
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2023-06-12 most components places except power capcitors
    [blinky_v3.kicad_pcb, blinky_v3.kicad_sch]
2023-06-12 updare pin mapping to CPU
    [blinky_v3.kicad_pcb, blinky_v3.kicad_sch]
2023-06-13 refactor sin to square conversion
    [blinky_v3.kicad_pcb, blinky_v3.kicad_sch]
2023-06-13 update gps compare for pps
    [blinky_v3.kicad_pcb, blinky_v3.kicad_sch]
2023-06-13 clean up power supplies
    [blinky_v3.kicad_pcb, blinky_v3.kicad_sch]
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2023-06-14 most ERC errors sorted out
    [OPA357AIDBVR.step, blinky_v3.kicad_pcb, blinky_v3.kicad_sch]
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2023-06-17 update comparator and start routing
    [blinky_v3.kicad_pcb, blinky_v3.kicad_sch]
2023-06-18 fix errors
    [blinky_v3.kicad_pcb, blinky_v3.kicad_sch]
2023-06-18 fix most errors
    [blinky_v3.kicad_pcb, blinky_v3.kicad_sch]
2023-06-18 fix all rules
    [blinky_v3.kicad_pcb]
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2023-06-19 update op amp for single supply
    [blinky_v3.kicad_pcb, blinky_v3.kicad_sch]
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2023-06-28 move the COL3 off of BOOOT1
    [blinky_v4.kicad_pcb, blinky_v4.kicad_sch]
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2023-06-28 add ext 10Mhz in BNC
    [blinky_v4.kicad_pcb, blinky_v4.kicad_sch]
2023-06-30 starting updates for V4
    [blinky_v4.kicad_sch]
2023-06-30 updates for output filter
    [blinky_v4.kicad_pcb, blinky_v4.kicad_sch]
2023-07-02 update voltages for req adj
    [blinky_v4.kicad_sch]
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2023-07-03 updated schematic to remove lots of not used stuff
    [blinky_v4.kicad_sch]
2023-07-03 re layout output buffers
    [blinky_v4.kicad_pcb]
2023-07-03 added 2nd output bufer
    [blinky_v4.kicad_pcb, blinky_v4.kicad_sch]
2023-07-03 did routing for 3 output channels
    [blinky_v4.kicad_pcb, blinky_v4.kicad_sch]
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2023-07-03 set orgin to lower left
    [blinky_v4.kicad_pcb, positions.csv]
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2023-07-04 bunch of re layout
    [blinky_v4.kicad_pcb, blinky_v4.kicad_sch]
2023-07-04 clean up analog side
    [blinky_v4.kicad_pcb]
2023-07-04 layout to LED connecector
    [blinky_v4.kicad_pcb, blinky_v4.kicad_sch]
2023-07-04 redo LED A layout
    [blinky_v4.kicad_pcb]
2023-07-05 add the A to G LED
    [blinky_v4.kicad_pcb, blinky_v4.kicad_sch]
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2023-07-05 add board 2 board power connector
    [blinky_v4.kicad_pcb, blinky_v4.kicad_sch]
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2023-07-07 fix LED footprints
    [blinky_v4.kicad_pcb, blinky_v4.kicad_sch]
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2023-07-07 clean up TP to not be in BOM
    [blinky_v4.kicad_sch, bom.csv, designators.csv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]
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2023-07-08 update all v4 prod files, schematic, and code gen
    [bom.csv, designators.csv, positions.csv]
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2023-07-29 fix the COL2 pin
    [blinky.ioc]
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2023-08-10 Validate the DBG outputs, fixes#59
    [blinky.ioc]
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2023-08-11 sort out edge directiosn for transitions given inverts on input/output
    [blinky.ioc]
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2023-08-12 tim 1 couting wrong
    [blinky.ioc]
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2023-08-17 fix GPS PPS routing bug
    [blinky_v5.kicad_pcb, blinky_v5.kicad_sch]
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2023-08-17 move LED resistors to pull down from pull up
    [blinky_v5.kicad_pcb, blinky_v5.kicad_sch]
2023-08-17 update to have FET drivers for some of status LEDs
    [blinky_v5.kicad_pcb, blinky_v5.kicad_sch]
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2023-08-28 fix up rotations for JLCPCB
    [audio_amp_r1.kicad_pcb, audio_amp_r1.kicad_sch, positions.csv]
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2023-09-12 Fix up M1,2,3 LED mapping
    [blinky.c, blinky.ioc, main.h]
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2023-09-13 moved parts from audio test board into blink board
    [blink_v6.kicad_pcb, blink_v6.kicad_sch]
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2023-09-17 version sent for R2build of audio amp HW
    [audio_amp_r2.kicad_pcb, audio_amp_r2.kicad_sch, bom.csv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]
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2023-09-23 fix up track widths
    [blink_v6.kicad_pcb]
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2023-09-30 change output gain of audio out by -20dB
    [blink_v7.kicad_pcb, blink_v7.kicad_sch]
2023-09-30 clean up connections and add gps tx voltage dividers
    [clock_v6.kicad_pcb, clock_v6.kicad_sch]
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2023-10-14 turn on RED status LED on error or assert
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2023-10-21 fix up rotation and locations
    [blink_v7.kicad_pcb, blink_v7.kicad_sch]
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2023-10-21 fux up errors on USB connector
    [blink_v7.kicad_pcb, blink_v7.kicad_sch]
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2023-10-22 fix up flip connector warning
    [disp_v7.kicad_pcb, disp_v7.kicad_sch]
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2023-10-23 fix interupt handler bug
    [blinky.c]
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2023-10-24 sync led timer to main to remove LED jitter
    [blinky.ioc]
2023-10-25 fix up compile warnings
    [blinky.c]
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2023-11-13 start mapping v8 clock pins to match bliky
    [clock_v8.kicad_sch]
2023-11-13 clean up clock 8 to match new pinouts
    [clock_v8.kicad_pcb, clock_v8.kicad_sch]
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2023-11-14 update disp schematics for new footprints / symbols
    [disp_v8.kicad_pcb, disp_v8.kicad_sch]
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2023-11-18 fix LED5/6
2023-11-24 invert LEDM drivers
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2023-11-24 fix bug with grid driver
    [blinky.c]
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2023-12-01 add protection on inputs flips to outputs
    [clock_v9.kicad_sch]
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2023-12-01 start swap usb rx/tx
    [blink_v9.kicad_sch]
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2023-12-01 start routing GPS RS232 inverts
    [clock_v9.kicad_pcb, clock_v9.kicad_sch]
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2023-12-01 fix clearances
    [clock_v9.kicad_pcb]
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2023-12-05 fix up osc footprint
    [blink_v9.kicad_pcb, blink_v9.kicad_sch, clock_v9.kicad_pcb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]
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2023-12-05 fix up SMD sizes to motly 0603 on clock
    [clock_v9.kicad_pcb, clock_v9.kicad_sch]
2023-12-05 fix up SMD sizes to motly 0603 on blink
    [blink_v9.kicad_pcb, blink_v9.kicad_sch]
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2023-12-11 fix diode selection for RS232
    [clock_v9.kicad_pcb, clock_v9.kicad_sch]
2023-12-13 make sure USB TX/RX protected from CPU driving
    [blink_v9.kicad_sch]
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2023-12-18 fixed speed of tim8 in other clock domain
    [blinky.ioc]
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2023-12-23 fix print location
2023-12-24 fix invert4ers for GPS serial
    [clock_v9.kicad_pcb, clock_v9.kicad_sch]
2023-12-24 update for new reset circuit
    [clock_v9.kicad_pcb, clock_v9.kicad_sch]
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2023-12-25 fix power jack on v9.2
    [clock_v9.kicad_pcb, clock_v9.kicad_sch]
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2023-12-26 update JLCPCB rotations and offsets for clock board
    [clock_v9.kicad_pcb, clock_v9.kicad_sch]
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2023-12-28 fix up sync code
    [blinky.c]
2023-12-28 fix up printf
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2023-12-29 output drift rate metrics
    [blinky.c, metrics.c]
2023-12-29 add the variso version of v9 clock hw
    [clock_v9.0.kicad_pcb, clock_v9.0.kicad_sch, clock_v9.1.kicad_pcb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]
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2024-01-04 update stm32flash line to be correct
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2024-01-06 start debug of problem where get out of sync for a cycle
    [metrics.c]
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2024-01-06 clean up simple 9.4 for new power supply
    [clock_9.4.kicad_pcb, clock_9.4.kicad_sch]
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2024-01-07 Fix bug with loosing last transition of LTC
    [blinky.c]
2024-01-07 turn off broken ppm and pbm code
    [metrics.c]
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2024-01-07 fix clock 9.4 for rotations that JLCPCB found after I submitted
    [clock_9.4.kicad_pcb, clock_9.4.kicad_sch]
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2024-01-10 Fixes #259 pwrd on gpx rx
    [clock_v10.0.kicad_pcb, clock_v10.0.kicad_sch]
2024-01-10 Fixes #211 led setting when not running
    [blink_v10.0.kicad_pcb, blink_v10.0.kicad_sch, clock_v10.0.kicad_pcb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]
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2024-01-12 change LEDMY to LEDMB. Fixes #230
    [blink_v10.0.kicad_pcb, blink_v10.0.kicad_sch, clock_v10.0.kicad_pcb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]
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2024-01-15 fix up setting linking
    [blinky.c, config.c]
2024-01-21 update to fix link problems from refactor
    [pps.c]
2024-01-23 clean up LED5/6 problem and BTN2
    [blink_v10.0.kicad_pcb, blink_v10.0.kicad_sch]
2024-01-23 fix buttons. Fixes #264 Fixes #261
    [blink_v10.0.kicad_pcb, blink_v10.0.kicad_sch, clock_v10.0.kicad_pcb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]
2024-01-23 fix up layout on clock
    [clock_v10.0.kicad_pcb, clock_v10.0.kicad_sch]
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2024-01-23 add sense resitors to other ps on bink
    [blink_v10.0.kicad_pcb, blink_v10.0.kicad_sch]
2024-01-24 replace power selection diodes with ideal diodes
    [blink_v10.0.kicad_pcb, blink_v10.0.kicad_sch]
2024-01-24 start adding reset circuit to v10 blink
    [blink_v10.0.kicad_pcb, blink_v10.0.kicad_sch]
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2024-01-25 update reset boot on clock v10
    [clock_v10.0.kicad_pcb, clock_v10.0.kicad_sch]
2024-01-25 fix up ground on clock v10
    [clock_v10.0.kicad_pcb, clock_v10.0.kicad_sch]
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2024-01-26 Add PP/LTC Jumper Fixes #275
    [clock_v10.0.kicad_pcb, clock_v10.0.kicad_sch]
2024-01-26 add power sense resisitors Fixes #294
    [clock_v10.0.kicad_pcb, clock_v10.0.kicad_sch]
2024-01-26 add jumper for USB / Reset disconnect Fixes #293
    [clock_v10.0.kicad_pcb, clock_v10.0.kicad_sch]
2024-01-26 moved to 250mW resisotrs. Fixes #289
    [clock_v10.0.kicad_pcb, clock_v10.0.kicad_sch]
2024-01-26 fiux voltage dirvide for GPS TX. Fixes #260
    [clock_v10.0.kicad_pcb, clock_v10.0.kicad_sch]
2024-01-26 fix up clock board errors
    [clock_v10.0.kicad_pcb, clock_v10.0.kicad_sch]
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2024-02-10 fix tyupo
    [clock_v11.kicad_sch]
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2024-02-10 fix but on adc1 for power detection
    [blinky.ioc, power.c]
2024-02-10 correctly detect USB power available
    [power.c]
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2024-02-10 Revert "update power handling"
    This reverts commit a4118a9430703536556e278bcb235b756ac733e4.
    [blinky.c, config.c, power.c]
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2024-02-10 correct pin names
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2024-02-12 make clock board USB power only. Fixes #307
    [clock_v11.kicad_pcb, clock_v11.kicad_sch]
2024-02-13 Remove R49. Fixes #303
    [clock_v11.kicad_pcb, clock_v11.kicad_sch]
2024-02-13 remove needless pull down reistors. Fixes #304
    [blink_v11.kicad_pcb, blink_v11.kicad_sch, clock_v11.kicad_pcb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]
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2024-02-16 chance current sense resistor. Fixes#308
    [clock_v11.kicad_pcb, clock_v11.kicad_sch]
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2024-02-21 swap sync in / pps out
    [blink_v11.kicad_pcb, blink_v11.kicad_sch]
2024-02-21 fix up footprints
    [blink_v11.kicad_pcb, blink_v11.kicad_sch, clock_v11.kicad_pcb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]
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2024-02-22 fix rotations on blink hw V11
    [blink_v11.kicad_sch]
2024-02-22 fix rotation on clock V11 based on things in blink V11
    [clock_v11.kicad_sch]
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2024-02-23 fixing up routing on clock
    [clock_v11.kicad_pcb, clock_v11.kicad_sch]
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2024-02-25 fixed mult osc symbol error
    [clock_v11.kicad_pcb, clock_v11.kicad_sch]
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2024-03-05 add auto sync for GPS board. Fixes #312
    [blinky.c]
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2024-03-10 start v12 of clock and gps in kicad8
    [clock_v12.kicad_pcb, clock_v12.kicad_sch, gps_v12.kicad_pcb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]
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2024-03-12 basic back end of blink box in freecad
    [box-v12.FCStd]
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2024-03-28 update for correct size side offsets
    [box-v12-BlinkBack.3mf, box-v12-BlinkBack.step, box-v12-BlinkBackSketch.dxf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]
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2024-03-31 update box whole locations for Blink Rev 9.0
    [box-v12.FCStd]
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2024-04-03 fix symbol for USBLC6-2P6 that seems chaged in kicad 8
    [blink_v12.kicad_pcb, blink_v12.kicad_sch]
2024-04-03 fix up schematic for new USBLC6-2P6 footprint
    [blink_v12.kicad_pcb, blink_v12.kicad_sch]
2024-04-03 fix error on PCB from kicad8
    [blink_v12.kicad_pcb]
2024-04-03 fix warnings from kicad8
    [blink_v12.kicad_pcb]
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2024-04-04 fix rotations for V12 blink
    [blink_v12.kicad_pcb, blink_v12.kicad_sch]
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2024-04-06 fixed offset for JLCPCB
    [blink_v12.kicad_pcb, blink_v12.kicad_sch]
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2024-04-10 replace tanntium caps and start blink v13
    [blink_v13.kicad_pcb, blink_v13.kicad_sch]
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2024-04-30 update box with new model and adjust locations
    [box-v12.FCStd]
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2024-05-18 update JST PH S3B connector with 3D model
    [clock_A.kicad_pcb, clock_A.kicad_sch]
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2024-05-26 generate production files for disp board Rev A
    [bom.csv, designators.csv, disp_A.kicad_pcb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]
2024-05-27 updade clock order with correct diode. Fixes #339
    [clock_A.kicad_pcb, clock_A.kicad_sch]
2024-05-27 start generation of GPS rev A.1 production files
    [bom.csv, designators.csv, gps_A.kicad_pcb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]
2024-05-27 version of GPS Rev A.1 submitted to JLCPCB
    [gps_A.kicad_pcb, gps_A.kicad_sch, positions.csv]
2024-05-27 remove tal caps on GPS, clean up schamatic
    [gps_A.kicad_pcb, gps_A.kicad_sch]
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2024-05-27 updadte osc footprint to use one with mount holes
    [blink_A.kicad_sch]
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2024-05-28 fix RJ45 size in box and regen the prod files for clockA box
    [blink-front.dxf, blinkBoxA-BlinkBoxABack.3mf, blinkBoxA-BlinkBoxAFront.3mf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]
2024-05-28 tune up locations of wholes in blink boxA
    [blinkBoxA.FCStd]
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2024-06-16 update rotation and offsets on clock and gps
    [blink_A.kicad_sch, clock_A.kicad_sch, gps_A.kicad_sch]
2024-06-16 Update jlc part num for CH340 Fixes#346
    [blink_A.kicad_sch, clock_A.kicad_sch, gps_A.kicad_sch]
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2024-06-16 fix rotation on disp
    [disp_A.kicad_sch]
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

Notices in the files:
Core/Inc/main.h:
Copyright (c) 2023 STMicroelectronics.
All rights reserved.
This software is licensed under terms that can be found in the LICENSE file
